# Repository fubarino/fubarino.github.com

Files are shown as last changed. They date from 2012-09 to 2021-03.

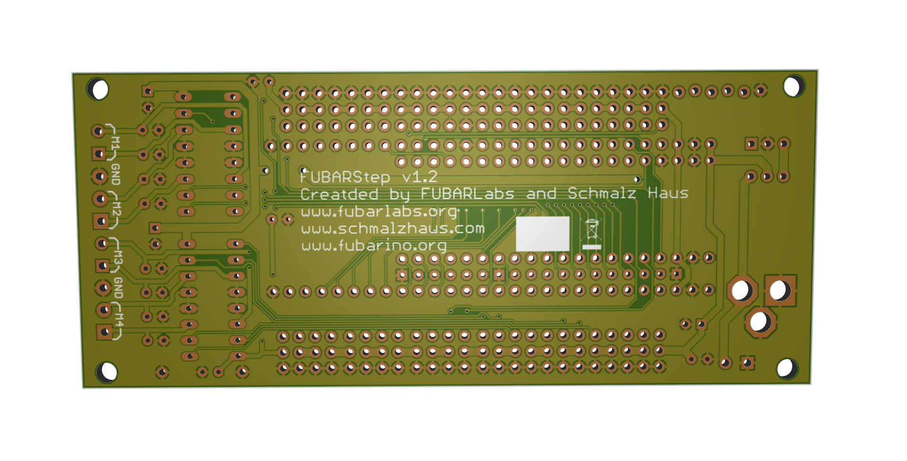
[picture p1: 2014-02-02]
accessories/FubarStep/FuabarStep_v13/BottomRender.png

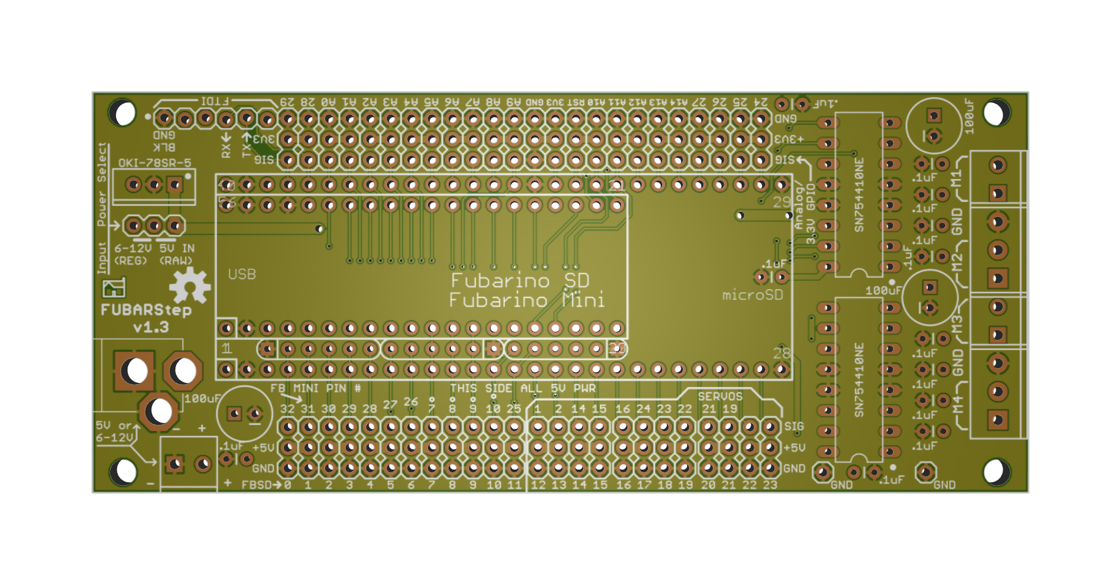
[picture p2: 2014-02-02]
accessories/FubarStep/FuabarStep_v13/TopRender.png

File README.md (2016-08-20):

fubarino: Social Hardware and Software
========
Main Project Pages are:
http://fubarino.org

The chipKIT Fubarino SD board brings affordable, breadboard compatible high speed computing power to the Arduino-compatible chipKIT/MPIDE platform. It is able to run almost all Arduino sketches right out of the box at a great price, and includes more memory, speed, and I/O pins than a typical Arduino or clone. And it includes a microSD card slot for easy sketch access to huge file storage.
chipKIT FubarinoSD
======
Class on a stick. Course materials can fit on the SD card. The device mounts as a USB device. Unfortunately, at 1.0 speeds. But 
it will cut 45 minutes of getting started to 15 minutes. When offering online course using electronics all the course materials can be placed on the board.

The goal with the project is two have two boards that are excellent for small, and bread boardable projects.

Social Hardware:
=====
* Open Source
* Open Hardware
* Sharable

Licensing
====
The chipKIT Fubarino SD hardware is licensed under the Solderpad Hardware License v0.5. All MPIDE source code is licensed under GPL or other open source software licenses.

Availability:
========
These boards are Open Source Hardware and all the files are managed in this project, and are licensed as OpenSource.

* Purchase Fubarino SD version 1.5 at [microchipDIRECT](http://www.microchipdirect.com/ProductSearch.aspx?Keywords=TCHIP010)
* Purchase Fubarino SD version 1.4 at [Seeed Studio](http://www.seeedstudio.com/depot/fubarino-sd-p-1265.html?cPath=132_133)
* Purchase Fubarino Mini version 1.5 at [microchipDIRECT](http://www.microchipdirect.com/ProductSearch.aspx?Keywords=TCHIP011)

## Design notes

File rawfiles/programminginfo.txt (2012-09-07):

Power Fubarino from USB

Unzip Fubarino.zip into variants folder

I have a ICD3 (at the top of the picture) with my custom made RJ-11 to 6-pin .100" header. On that cable (from the ReadlIce) (from left to right)

Direct Connect

ICD3 : value
Blue: unused
Yellow: PGC
Green: PGD
Red: GND
Black: 3.3V
White: MCLR/RESET

Bread Board Example

R:B: value
Blue: White : unused
Yellow: Black : PGC
Green: Red : PGD
Red: Green : GND
Black: Yellow : 3.3V
White: Blue : MCLR/RESET

Then I have five jumpers that connect that ICD3 cable to the Fubarino, again, from left to right

ICD3 : Color : Fubarino
PGC :: Red : A9
PGD :: Yellow : A8
GND :: Green : GND
3.3V :: Black : 3.3
MCLR/RESET : : RST

The important thing is that the cable from the ICD3 goes into the Fubarino 1:1 except for PGC and PGD which need to be reversed.

Hopefully this will help you when you start to program yours on Friday.

ICD3: FubarinoSD
1: PGM 
2: PGC : A9
3: PGD : A8
4: Ground : GND
5: Vdd : 3.3
6: MCLR/Vpp, reset : RST

ICD3: Fubarino Mini end of board left to right
White: Reset
Black: 3.3V
Red: GND
Green: PGD
Yellow: PGC

Note: no blue, unusued

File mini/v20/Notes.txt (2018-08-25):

Fubarino Mini v1.0 board - changes for v1.1 : 04/04/2012
* For v1.1, move 32KHz crystal so it lies flat. Rotate 90 degrees to right. (done)
* Add some silk screen on some pins so you know where to start counting. (done)
* Calculate correct crystal cap values and update BOM (done)
* Make 32KHz crystal a do not populate on schematic and in BOM (done)
* Move PRG and RESET switches further apart (done)

Fubarino Mini v1.1 board - changes for v1.2 : 06/08/2012
* Add in two diodes to allow USB or external VIN power
* Separate out 5V_OUT and VIN as separate pins
* Swap GND and 5V_OUT/VIN so 5V_OUT/VIN are on end

Fubarino Mini v1.2 board - changes for v1.3 : 07/17/2012
* Extended pads for CPU by .3mm so you can rework the part (at request of SeeedStudio)
* Switched power LED to RED in BOM

Fubarino Mini v1.3 board - changes for v1.4 : 07/18/2012
* Switched CPU footprint to QFN44, routing updates to support this change
* C13 switched to 10uF for better 3.3V stability

Fubarino Mini v1.5 board - changes to v1.4 : 02/23/2012 (for Microchip)
* Added chipKIT to silk screen
* Added RoSH garbage icon to silk screen
* Added CE icon to silk screen
* Updated to different USB connector (Hirose UX60-MB-5ST) and re-routed USB signals to fit

Fubarino Mini v1.6 board - changes to v1.5 : 03/14/2012
* J2 pin 17 is now RESET rather than GND. This allows external RESET connection without needing to use J3
* Changed BOM to use 820 ohm LED current limiting resistors rather than 330s

Fubarino Mini v1.7 (now v2.0) board - changes to v1.6 : 08/13/2015
* Connected VBUS net to VBUS PIC32 pin rather than 5V to prevent over voltage on Vin from damaging PIC32 VBUS pin.
* Changed D1 and D2 to CUS15S40,H3F types to handle 1.5A max current
* Changed IC1 to AP7215-33YG-13 to handle 600mA of current (rather than 250mA from old part). Note that max Vin is now 5.5V. (see below)
* Change CPU to PIC32MX270F256D-I/ML. Same as before but with twice the Flash and RAM
  August 2018 update, to create final v1.7 (v2.0) design, based on emails with Matt Jenkins:
  * Change regulator to SPX1117M3-L-3-3/TR (requires layout change)
  * Change USB connector to micro-USB
  * LEDs get 820 ohm resistors
  
Fubarino Mini v2.0 - 10 built up on 8/24/2018. All work as expected.

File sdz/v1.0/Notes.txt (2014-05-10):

These are internal developer change notes created during the development process of the Fubarino SDZ board.
Written by Brian Schmalz of Schmalz Haus LLC (www.schmalzhaus.com)
2014

Version 1.0 ToDo:
* For primary oscillator, find cheap TTL osc rather than crystal, and replace footprint
*

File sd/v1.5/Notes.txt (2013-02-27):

These are internal developer change notes created during the development process of the Fubarino SD board.
Written by Brian Schmalz of Schmalz Haus LLC (www.schmalzhaus.com)
2012

Version 1.0, problems:

* Silk screen messed up - acidentally turned on the part names on the silk layer
    Fix: turn them off before next build
* Swapped PGC and PGD on ICSP connector
    Fix: swap them back for v1.1
* No LED orentation markers on silk screen
    Fix: add them to v1.1
* Crystal is really, really big
    Fix: Find smaller one for v1.1
* For 3.3V regulator, change to one with fixed voltage (3.3V), and smaller if possible
* 250mA poly fuse is too small
    Fix: Switch to 500mA polyfuse for v1.1
* VUSB needs to be tied to +3.3V
* Update MX440 symbol to have all pin functions listed
* MCLR should not have a pin number - can't use it as an I/O pin
* Should we have a pin 0? (rather than starting at 1)

Version 1.1 problems - fix for v1.2:

* Forgot to remove the PTC - should be removed for v1.2 (done)
* Possible change - make all silk screen pin names read same way? (done)
* Silk screen next to green LED is wrong. It should read 21. (done)
* Reverse green LED so it goes to GND rather than 3.3V. (done)
* Check cap values for both crystals (done)
* Move reset and program switches further apart (done)

Version 1.2 - changes for v1.3:

* Add two diodes to allow power from USB or VIN input pin
* Separate out 5V in from post-diode power net, bring to pins
* Swap GND and 5V_OUT/VIN so 5V_OUT/VIN are on end

Version 1.3 - changes for v1.4:

* C13 changed from 1uF to 10uF, and from 0603 ro 0805, to help reduce VCC drop on microSD insert

Version 1.4 - changes for v1.5 (for Microchip):

* Added chipKIT, CE mark, and RoHS mark to bottom silk screen and chipKIT to top silk screen
* added RX silk to pin 8 and TX silk to pin 9
* changed USB connector to Microchip's preferred Hirose UX60-MB-5ST

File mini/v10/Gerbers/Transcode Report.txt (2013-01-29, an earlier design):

   ---- Transcoding 'D:\Projects\UBW32\EE\FubarinoMini\v10\Gerbers\FubarinoMini_v10.GTS' ----   Tue Mar 20 21:46:35 2012

D10   --> D100
D11   --> D101
D12   --> D102
D13   --> D103
D14   --> D104
D15   --> D105
D16   --> D106
D17   --> D107
-----------------------------------------------------------------

   ---- Transcoding 'D:\Projects\UBW32\EE\FubarinoMini\v10\Gerbers\FubarinoMini_v10.cmp' ----   Tue Mar 20 21:46:35 2012

D10   --> D108
D11   --> D109
D12   --> D110
D13   --> D111
D14   --> D112
D15   --> D113
D16   --> D114
D17   --> D115
D19   --> D116
D20   --> D117
D21   --> D118
D24   --> D119
-----------------------------------------------------------------

   ---- Transcoding 'D:\Projects\UBW32\EE\FubarinoMini\v10\Gerbers\FubarinoMini_v10.GBL' ----   Tue Mar 20 21:46:35 2012

D10   --> D120
D11   --> D121
D12   --> D122
D13   --> D123
D14   --> D124
D15   --> D125
-----------------------------------------------------------------

   ---- Transcoding 'D:\Projects\UBW32\EE\FubarinoMini\v10\Gerbers\FubarinoMini_v10.GBS' ----   Tue Mar 20 21:46:35 2012

D10   --> D126
D11   --> D127
D12   --> D128
-----------------------------------------------------------------

   ---- Transcoding 'D:\Projects\UBW32\EE\FubarinoMini\v10\Gerbers\FubarinoMini_v10.GBO' ----   Tue Mar 20 21:46:36 2012

D10   --> D129
D11   --> D130
D12   --> D131
D13   --> D132
-----------------------------------------------------------------

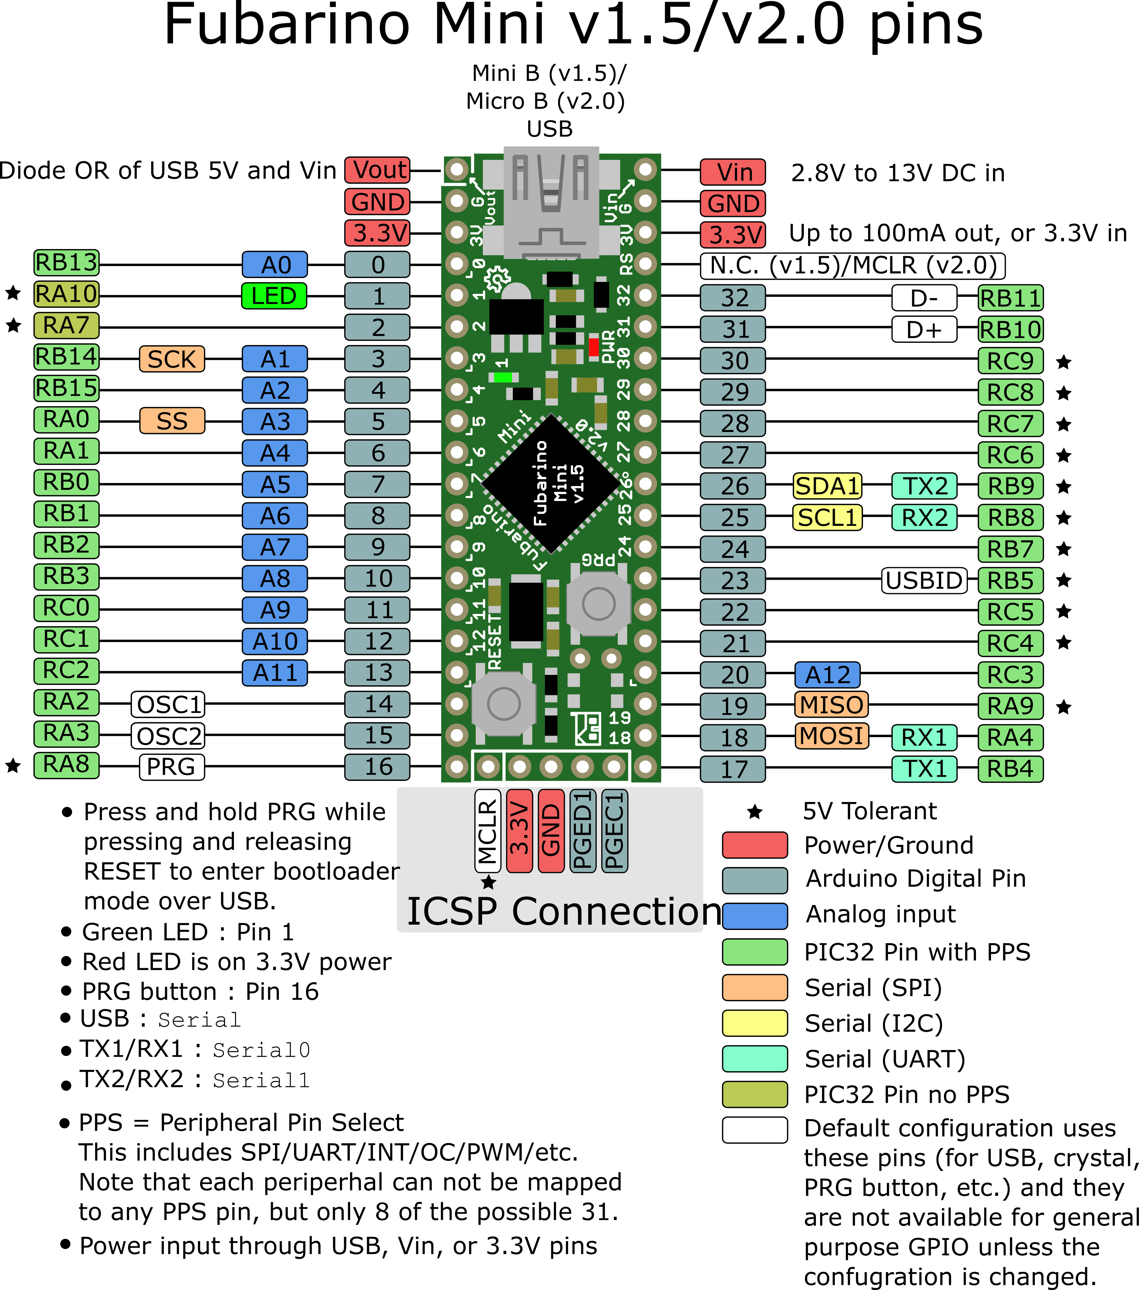
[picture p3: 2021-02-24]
mini/docs/FubarinoMiniDiagram.png

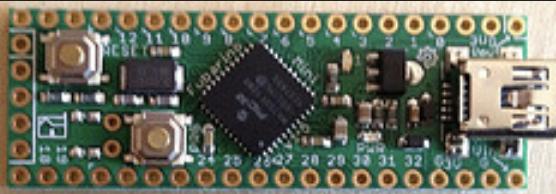
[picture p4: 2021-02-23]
images/FubarinoMini.png

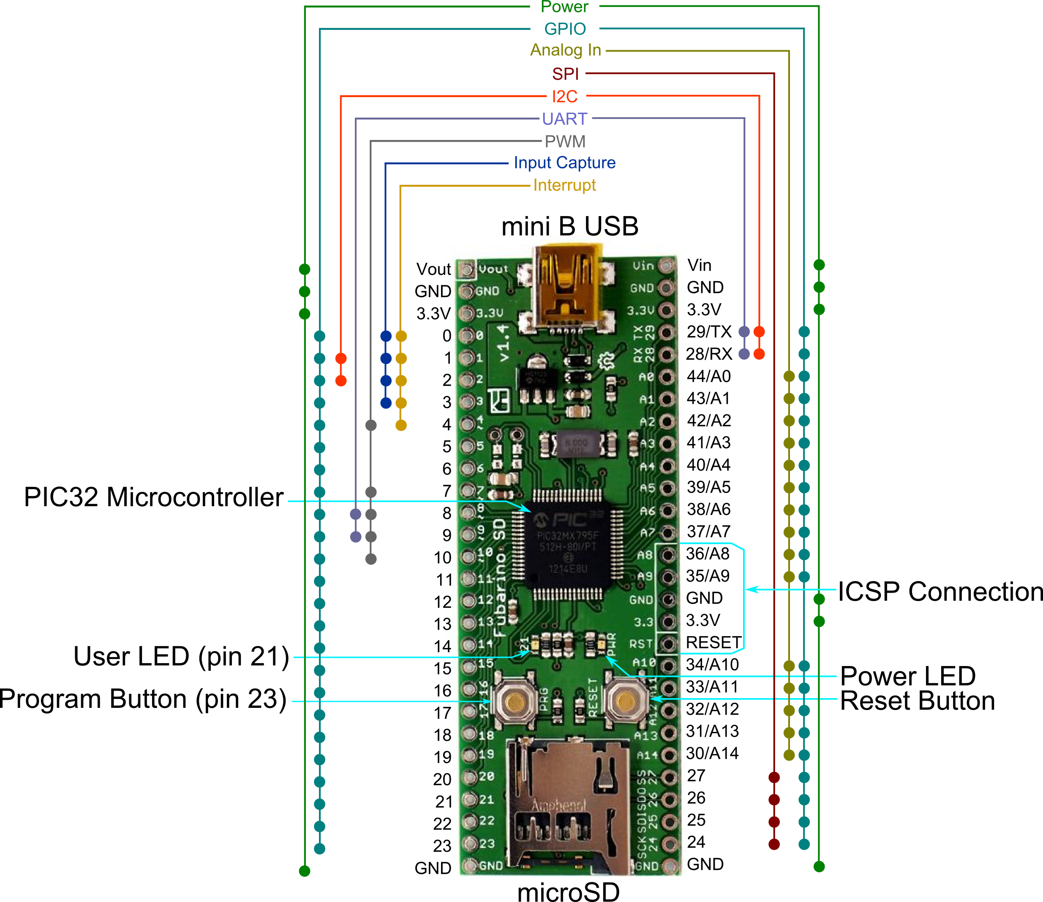
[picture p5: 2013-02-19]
sd/docs/FubarinoSDv1_4Diagram.png

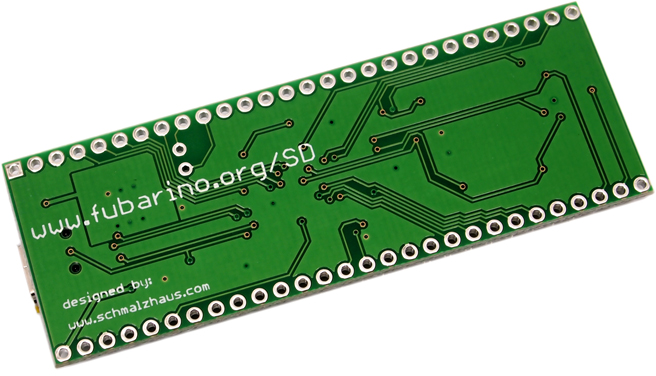
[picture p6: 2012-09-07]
images/fubarinosd2.png

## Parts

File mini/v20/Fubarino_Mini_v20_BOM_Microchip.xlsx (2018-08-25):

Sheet: BOM Report
Bill of Materials |  | Bill of Materials For Project Fubarino Mini v2.0
Part Number: | 02-10133r16.xls
Revision: | 2
Engineer: | Brian Schmalz
Drawn By: | Brian Schmalz
Creation Date:
Print Date:
Quantity | Designator | Description | Manufacturer 1 | Manufacturer Part Number 1 | Supplier 1 | Supplier Part Number 1 | RoHS compliant? | Supplier Order Qty 1 | Supplier Unit Price 1 | Extension | Price @1K | Total @1K
1 | Q1 | CRYSTAL 8.0000MHZ 8PF SMD | NDK America, Inc. | NX3225GD-8MHZ-STD-CRA-3 | Digi-Key | 644-1178-1-ND | Yes | 1 | $0.94 | $0.94 | $0.54 | $0.54
1 | U2 | IC REG LINEAR 3.3V 800MA SOT223 | MaxLinear, Inc. | SPX1117M3-L-3-3/TR | Digi-Key | 1016-1848-1-ND | Yes | 1 | $0.45 | $0.45 | $0.12 | $0.12
1 | C3 | CAP CER 4.7UF 35V X5R 0603 | Murata Electronics North America | GRM188R6YA475KE15D | Digi-Key | 490-7205-1-ND | Yes | 1 | $0.57 | $0.57 | $0.15 | $0.15
2 | C5, C13 | CAP CER 10UF 10V X5R 0805 | Samsung Electro-Mechanics | CL21A106KPFNNNE | Digi-Key | 1276-1052-1-ND | Yes | 2 | $0.16 | $0.32 | $0.03 | $0.06
1 | J8 | CONN RCPT USB MICRO B 2.0 5P SMD | Hirose Electric Co Ltd | ZX62D-B-5PA8(30) | Digi-Key | H125718CT-ND | Yes | 1 | $0.77 | $0.77 | $0.40 | $0.40
2 | PRG, RESET | SWITCH TACTILE SPST-NO 0.05A 16V | C&K Components | PTS810 SJM 250 SMTR LFS | Digi-Key | CKN10502DKR-ND | Yes | 2 | $0.30 | $0.60 | $0.17 | $0.35
4 | C4, C8, C9, C10 | CAP CER 0.1UF 50V Y5V 0603 | Yageo | CC0603ZRY5V9BB104 | Digi-Key | 311-1343-1-ND | Yes | 4 | $0.10 | $0.40 | $0.02 | $0.06
1 | LED1 | LED RED CLEAR CHIP SMD | Lite-On Inc. | LTST-C193KRKT-5A | Digi-Key | 160-1830-1-ND | Yes | 1 | $0.41 | $0.41 | $0.08 | $0.08
1 | LED2 | LED GREEN CLEAR CHIP SMD | Lite-On Inc. | LTST-C193KGKT-5A | Digi-Key | 160-1828-1-ND | Yes | 1 | $0.41 | $0.41 | $0.08 | $0.08
2 | R8,R11 | RES 820 OHM 1/10W 5% 0603 SMD | Panasonic | ERJ-3GEYJ821V | Digi-Key | P820GCT-ND | Yes | 2 | $0.10 | $0.20 | $0.01 | $0.02
3 | R1,R9,R10 | RES 10K OHM 1/10W 5% 0603 SMD | Panasonic | ERJ-3GEYJ103V | Digi-Key | P10KGCT-ND | Yes | 3 | $0.10 | $0.30 | $0.01 | $0.03
1 | U1 | IC MCU 32BIT 256KB FLASH 44QFN | Microchip | PIC32MX270F256D-50I/ML | Digi-Key | PIC32MX270F256D-50I/ML-ND | Yes | 1 | $4.62 | $4.62 | $3.84 | $3.84
2 | C14, C15 | CAP CER 12PF 50V C0G/NP0 0603 | AVX Corporation | 06035A120GAT2A | Digi-Key | 478-7910-1-ND | Yes | 2 | $0.52 | $1.04 | $0.14 | $0.27
1 |  | Fubarino Mini v1.7 blank PCB |  |  |  |  | Yes | 1 |  | $0.00 |  | $0.00
2 | D1, D2 | DIODE SCHOTTKY 40V 1.5A SOD323 | Toshiba Semiconductor and Storage | CUS15S40,H3F | Diki-Key | CUS15S40H3FCT-ND | Yes | 2 | $0.47 | $0.94 | $0.09 | $0.17
DO NOT POPULATE ANY PARTS BELOW THIS LINE
0 | Q2 | CRYSTAL 32.768KHZ 12.5PF | Siko Insturments | VT200F-12.5PF20PPM | Digi-Key | 728-1001-ND | Yes | 0 | $0.30 | $0.00 |  | $0.00
0 | C1, C2 | CAP CERAMIC 18PF 50V NP0 0603 | Kemet | C0603C180J5GACTU | Digi-Key | 399-1052-1-ND | Yes | 0 | $0.10 | $0.00 |  | $0.00
0 | J3 | ICSP 5-pin .100" header
 |  |  |  |  |  |  |  |  |  | $11.97 |  | $6.17
Approved | Notes
 |  | Parts changed from last production build

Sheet: Project Information
Project Full Path
Project Filename
Variant Name
Data-Source Filename
Data-Source Full Path
Title
Total Quantity
Report Time
Report Date
Report Date & Tine
Output Name
Output Type
Output Generator Name
Output Generator Description

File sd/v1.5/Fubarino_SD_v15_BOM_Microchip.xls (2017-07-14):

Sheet: BOM Report
Bill of Materials |  | Bill of Materials For Project Fubarino SD v1.5
Part Number: | 05-10133r15.xls |  |  |  |  |  |  | M
Revision: | 1.5
Engineer: | Brian Schmalz
Drawn By: | Brian Schmalz
Creation Date:
Print Date:
Quantity | Designator | Description | Manufacturer 1 | Manufacturer Part Number 1 | Supplier 1 | Supplier Part Number 1 | RoHS compliant? | Supplier Order Qty 1 | Supplier Unit Price 1 | Extension
1 | Q1 | CRYSTAL 8.00 MHZ 8PF SMD | NDK | NX5032GA 8MHZ AT-W | Digikey | 644-1132-1-ND | Yes | 1 | 1.7 | $1.70
1 | IC2 | IC REG SOT89 3.3V | Microchip | MCP1702T-3302E/MB | MicrochipDirect | MCP1702T-3302E/MB | Yes | 1 | 0.48 | $0.48
1 | C3 | CAP 1UF 10V CER Y5V SMD 0603 | Kemet | C0603C105Z8VACTU | Digi-Key | 399-3216-1-ND | Yes | 1 | 0.1 | $0.10
2 | C5, C13 | CAP CER 10UF 10V Y5V 0805 | Kemet | C2012Y5V1A106Z | Digi-Key | 445-1371-1-ND | Yes | 2 | 0.15 | $0.30
1 | J8 | CONN RECEPT MINI USB2.0 5POS | Hirose | UX60-MB-5ST | Digi-Key | H2959TR-ND | Yes | 1 | 0.528 | $0.53
2 | PRG, RESET | SWITCH TACT SMT SPST 160GF | C&K Components | PTS525SM10SMTR LFS | Digi-Key | CKN9104CT-ND | Yes | 2 | 0.61 | $1.22
4 | C4, C8, C9, C10 | CAP CERAMIC .100UF 50V X7R 0603 | Kemet | C0603C104K5RACTU | Digi-Key | 399-5089-1-ND | Yes | 4 | 0.1 | $0.40
1 | LED1 | LED SMARTLED 630NM RED 0603 SMD | OSRAM | LS L29K-G1J2-1-Z | Digi-Key | 475-2506-1-ND | Yes | 1 | 0.17 | $0.17
1 | LED2 | LED SMARTLED GREEN 570NM 0603 | OSRAM | LG L29K-G2J1-24-Z | Digi-Key | 475-2709-1-ND | Yes | 1 | 0.22 | $0.22
2 | R8,R11 | RES 330 OHM 1/10W 5% 0603 SMD | Panasonic | ERJ-3GEYJ331V | Digi-Key | P330GCT-ND | Yes | 2 | 0.1 | $0.20
4 | R1,R3,R9,R10 | RES 10K OHM 1/10W 5% 0603 SMD | Panasonic | ERJ-3GEYJ103V | Digi-Key | P10KGCT-ND | Yes | 4 | 0.1 | $0.40
1 | IC1 | PIC32 USB CPU | Microchip | PIC32MX795F512H-80I/PT | MicrochipDirect | PIC32MX795F512H-80I/PT | Yes | 1 | 8.75 | $8.75
2 | C14, C15 | CAP CER 12PF 50V 5% NP0 0603 | Kemet | C0603C120J5GACTU (http://www.digikey.com/product-detail/en/C0603C120J5GACTU) | Digi-Key | 399-1050-1-ND | Yes | 2 | 0.1 | $0.20
1 |  | Fubarino SD v1.5 blank PCB | ??? | ??? | ??? | ??? | Yes | 1 |  | $0.00
2 | D1, D2 | DIODE SCHOTTKY 0.5A 40V SOD323 | Diodes Inc | B0540WS-7 (http://www.digikey.com/product-detail/en/B0540WS-7) | Digi-Key | B0540WSDICT-ND | Yes | 2 | 0.45 | $0.90
1 | MICROSD | CONN MINI MICRO-SD 8PIN PCB GOLD | Amphenol | 101-00581-59 | Digi-Key | 101-00581-59-1-ND | Yes | 1 | 1.97 | $1.97
DO NOT POPULATE ANY PARTS BELOW THIS LINE
0 | Q2 | CRYSTAL 32.768KHZ 12.5PF | Siko Insturments | VT200F-12.5PF20PPM | Digi-Key | 728-1001-ND | Yes | 0 | 0.3 | $0.00
0 | C1, C2 | CAP CERAMIC 18PF 50V NP0 0603 | Kemet | C0603C180J5GACTU | Digi-Key | 399-1052-1-ND | Yes | 0 | 0.1 | $0.00
 |  |  |  |  |  |  |  |  |  | $17.54
Approved | Notes

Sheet: Project Information
Project Full Path
Project Filename
Variant Name
Data-Source Filename
Data-Source Full Path
Title
Total Quantity
Report Time
Report Date
Report Date & Tine
Output Name
Output Type
Output Generator Name
Output Generator Description

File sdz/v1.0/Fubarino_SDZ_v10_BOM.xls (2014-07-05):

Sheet: BOM Report
Bill of Materials |  | Bill of Materials For Project Fubarino SDZ v1.0
Part Number: |  |  |  |  |  |  |  | M
Revision: | 1.0
Engineer: | Brian Schmalz
Drawn By: | Brian Schmalz
Creation Date:
Print Date:
Quantity | Designator | Description | Manufacturer 1 | Manufacturer Part Number 1 | Supplier 1 | Supplier Part Number 1 | RoHS compliant? | Supplier Order Qty 1 | Supplier Unit Price 1 | Extension
1 | IC3 | OSC MEMS 24.000MHZ CMOS SMD | Silicon Labs | 501JCA24M0000CAF | Digi-Key | 336-2924-ND | Yes | 1 | 1.04 | $1.04
1 | IC2 | IC REG SOT89 3.3V | Microchip | MCP1702T-3302E/MB | Digi-Key | MCP1702T-3302E/MBCT-ND | Yes | 1 | 0.58 | $0.58
1 | C3 | CAP 1UF 10V CER Y5V SMD 0603 | Kemet | C0603C105Z8VACTU | Digi-Key | 399-3216-1-ND | Yes | 1 | 0.1 | $0.10
2 | C13 | CAP CER 10UF 10V Y5V 0805 | Kemet | C2012Y5V1A106Z | Digi-Key | 445-1371-1-ND | Yes | 2 | 0.15 | $0.30
1 | J4 | Conn Micro USB Type B RCP 5 POS | Hirose | ZX62-B-5PA(11) | Digi-Key | H11634CT-ND | Yes | 1 | 0.96 | $0.96
2 | PRG, RESET | SWITCH TACTILE SPST-NO 0.05A 32V | C&K Components | KMR221NG LFS | Digi-Key | CKN10244CT-ND | Yes | 2 | 0.58 | $1.16
4 | C4, C6, C8, C9, C10 | CAP CERAMIC .100UF 50V X7R 0603 | Kemet | C0603C104K5RACTU | Digi-Key | 399-5089-1-ND | Yes | 4 | 0.1 | $0.40
1 | LED1 | LED SMARTLED 630NM RED 0603 SMD | OSRAM | LS L29K-G1J2-1-Z | Digi-Key | 475-2506-1-ND | Yes | 1 | 0.17 | $0.17
1 | LED2 | LED SMARTLED GREEN 570NM 0603 | OSRAM | LG L29K-G2J1-24-Z | Digi-Key | 475-2709-1-ND | Yes | 1 | 0.22 | $0.22
2 | R8,R11 | RES 330 OHM 1/10W 5% 0603 SMD | Panasonic | ERJ-3GEYJ331V | Digi-Key | P330GCT-ND | Yes | 2 | 0.1 | $0.20
4 | R1,R3,R9,R10 | RES 10K OHM 1/10W 5% 0603 SMD | Panasonic | ERJ-3GEYJ103V | Digi-Key | P10KGCT-ND | Yes | 4 | 0.1 | $0.40
1 | IC1 | PIC32 USB CPU | Microchip | PIC32MZ2048ECH064 | MicrochipDirect | PIC32MZ2048ECH064 | Yes | 1 | 8.75 | $8.75
1 | R2 | RES 1K OHM 1/10W 5% 0603 SMD | Panasonic | ERJ-3GEYJ102V | Digi-Key | P1.0KGCT-ND | Yes | 1 | 0.1
1 |  | Fubarino SDZ v1.0 blank PCB |  |  |  |  | Yes | 1 |  | $0.00
2 | D1, D2 | DIODE SCHOTTKY 0.5A 40V SOD323 | Diodes Inc | B0540WS-7 (http://www.digikey.com/product-detail/en/B0540WS-7) | Digi-Key | B0540WSDICT-ND | Yes | 2 | 0.5 | $1.00
1 | MICROSD | CONN MINI MICRO-SD 8PIN PCB GOLD | Amphenol | 101-00581-59 | Digi-Key | 101-00581-59-1-ND | Yes | 1 | 1.84 | $1.84
DO NOT POPULATE ANY PARTS BELOW THIS LINE
0 | Q2 | CRYSTAL 32.768KHZ 12.5PF | Siko Insturments | VT200F-12.5PF20PPM | Digi-Key | 728-1001-ND | Yes | 0 | 0.3 | $0.00
0 | C5 | CAP CER 10UF 10V Y5V 0805 | Kemet | C2012Y5V1A106Z | Digi-Key | 445-1371-1-ND | Yes | 2 | 0.15 | $0.30
0 | J5
0 | C1, C2 | CAP CERAMIC 18PF 50V NP0 0603 | Kemet | C0603C180J5GACTU | Digi-Key | 399-1052-1-ND | Yes | 0 | 0.1 | $0.00
 |  |  |  |  |  |  |  |  |  | $17.42
Approved | Notes

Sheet: Project Information
Project Full Path
Project Filename
Variant Name
Data-Source Filename
Data-Source Full Path
Title
Total Quantity
Report Time
Report Date
Report Date & Tine
Output Name
Output Type
Output Generator Name
Output Generator Description

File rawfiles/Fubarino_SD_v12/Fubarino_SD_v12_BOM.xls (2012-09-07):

Qty | Ref | Description | Mfg Part Number | Disti part number | Distributor | Price @1 | Price @1000 | Total @1 | Total @1000
1 | Q1 | CRYSTAL 8.00 MHZ 8PF SMD | NX5032GA 8MHZ AT-W | 644-1132-1-ND | Digi-Key | $1.70 | $0.86 | $1.70 | $0.86
1 | IC2 | IC REG SOT89 3.3V | MCP1702T-3302E/MB | MCP1702T-3302E/MB | MicrochipDirect | $0.48 | $0.86 | $0.48 | $0.86
2 | C3, C13 | CAP 1UF 10V CER Y5V SMD 0603 | C0603C105Z8VACTU | 399-3216-1-ND | Digi-Key | $0.04 | $0.03 | $0.08 | $0.06
1 | C5 | CAP CER 10UF 10V Y5V 0805 | C2012Y5V1A106Z | 445-1371-1-ND | Digi-Key | $0.32 | $0.08 | $0.32 | $0.08
1 | J8 | CONN RECEPT MINI USB2.0 5POS | 10033526-N3212MLF | 10033526-N3212MLF | Newark | $0.54 | $0.35 | $0.54 | $0.35
2 | PRG, RESET | SWITCH TACT SMT SPST 160GF | PTS525SM10SMTR LFS | CKN9104CT-ND | Digi-Key | $0.56 | $0.36 | $1.12 | $0.71
4 | C4, C8, C9, C10 | CAP CERAMIC .100UF 50V X7R 0603 | C0603C104K5RACTU | 399-5089-1-ND | Digi-Key | $0.14 | $0.05 | $0.58 | $0.21
1 | LED1 | LED SMART 470NM BLUE 0603 SMD | LB L293-M2P1-36-1-10-R18-Z | 475-1383-1-ND | Digi-Key | $0.69 | $0.46 | $0.69 | $0.46
1 | LED2 | LED GRN HI BRT SS TYPE LO CUR S | LNJ308G8TRA | P525CT-ND | Digi-Key | $0.46 | $0.20 | $0.46 | $0.20
2 | R8,R11 | RES 330 OHM 1/10W 5% 0603 SMD | ERJ-3GEYJ331V | P330GCT-ND | Digi-Key | $0.02 | $0.01 | $0.04 | $0.01
3 | R1,R3,R10 | RES 10K OHM 1/10W 5% 0603 SMD | ERJ-3GEYJ103V | P10KGCT-ND | Digi-Key | $0.02 | $0.01 | $0.06 | $0.02
1 | U1 | PIC32 USB CPU | PIC32MX440F256H-80I/PT | PIC32MX440F256H-80I/PT | MicrochipDirect | $6.30 | $4.81 | $6.30 | $4.81
1 |  | 2.8 sq inches of PCB at .71 each |  |  | GoldPhoenix | $1.99 | $0.50 | $1.99 | $0.50
4 | C1, C2, C14, C15 | CAP CERAMIC 18PF 50V NP0 0603 | C0603C180J5GACTU | 399-1052-1-ND | Digi-Key | $0.07 | $0.03 | $0.28 | $0.10
1 | MICROSD | CONN MINI MICRO-SD 8PIN PCB GOLD | 101-00581-59 | 101-00581-59-1-ND | Digi-Key | $1.94 | $1.05 | $1.94 | $1.05
1 | Q2 | CRYSTAL 32.768KHZ 12.5PF | VT200F-12.5PF20PPM | 728-1001-ND | Digi-Key | $0.42 | $0.28 | $0.42 | $0.28
 |  |  |  |  |  |  | Total | $15.30 | $10.56

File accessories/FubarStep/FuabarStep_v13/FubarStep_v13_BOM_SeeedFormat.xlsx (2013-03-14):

Electronic Engineering BOM List
Product Name： FubarStep
Version：V1.0
Issue Date：03/13/2013
Item No. (序号) | Reference Des (上件位置) | Qty (用量) | Catalog (分类） | Part_Description (规格描述) | Part_Value （元件值） | Part_Package （元件封装） | Manufacturers Name (使用厂牌名称) | Manufacturers Part No. (使用厂牌型号) | Distributors Name （供应商名称） | Distributors Part No. (供貨商型号) | Unit Price （单价） | Price Break To Use （价格分段的购买量） | Notes/Remark （备注）
Example（填写范例）
1 | U1 | 2 | Connector | 28 pin female .100" header for Fubarino SD footprint |  |  | Ebay |  |  |  | $0.5500 |  | $1.10
2 | U2 | 2 | Connector | 20 pin female .100" header for Fubarino Mini footprint |  |  | Ebay |  |  |  | $0.3500 |  | $0.70
3 | JP7,JP9,JP13,JP24,JP30,JP25,JP28,JP29,JP31,JP32,JP33, | 3 | Connector | 12 pin male .100" header for servo connections |  |  | Ebay |  |  |  | $0.1200 |  | $0.36
4 | JP18,JP19,JP20,Jp21,JP26,JP27,JP14,JP15,JP16,JP17,Jp22,JP23,JP10,JP11,JP12 | 3 | Connector | 15 pin male .100" header for analog connections |  |  | Ebay |  |  |  | $0.1500 |  | $0.45
5 | C3,C11,C10,C12,C9,C13,C8,C15,C14,C18,C19,C1 | 12 | Capacitor | .1uF through hole ceramic capactor |  |  | Murata | RPER71H104K2P1A03B | Arrow | RPER71H104K2P1A03B | $0.0485 |  | $0.58
6 | C5,C2,C17,C16 | 4 | Capacitor | 100uF >35V electrolytic through hole capacitor |  |  | Nichicon | UVR1H101MPD | Arrow | UVR1H101MPD | $0.0426 |  | $0.17
7 | IC2,IC3 | 2 | IC | SN754410NE H-Bridge in 16 PDIP |  |  | Texas Instruments | SN754410NE | Arrow | SN754410NE | $0.8899 |  | $1.78
8 | SOC1,SOC2 | 2 | Connector | 16 PDIP socket for IC2, IC3 |  |  | TE Connectivity | 13902614 | Arrow | 13902614 | $0.0923 |  | $0.18
9 | JP1, JP2 | 2 | Connector | 4-pin 3.5mm screw terminal |  |  | Molex | 393570004 | Arrow | 393570004 | $0.5619 |  | $1.12
10 | JP8 | 1 | Connector | 6-pin right angle .100 male header |  |  | FCI | 68016136HLF | Arrow | 68016136HLF | $0.8062 |  | $0.81
11 | JP3 | 1 | Connector | 3-pin male .100 header for power select |  |  | Ebay |  |  |  | $0.0300 |  | $0.03
12 | JP4 | 1 | Connector | 2-pin 3.5mm screw terminal |  |  | Molex | 393570002 | Arrow | 393570002 | $0.2721 |  | $0.27
13 | X1 | 1 | Connector | barrel jack power input |  |  | Switchcraft | RAPC722X | Arrow | RAPC722X | $0.3942 |  | $0.39
14 | U3 | 1 | IC | 5V switching regulator |  |  | Murata Power Solutions | OKI-78SR-5/1.5-W36H-C | DigiKey | 811-2196-5-ND | $4.3000 |  | $4.30
15 | JP3_JUMP | 1 | Connector | .100 2-pin shorting jumper |  |  | FCI | 68786102LF | Arrow | 68786102LF | $0.0726 |  | $0.07
16 | PCB | 1 | OTHER | FubarStep v1.0 PCB |  |  | SeeedStudio |  |  |  | $3.4000 |  | $3.40
 |  |  |  |  |  |  |  |  |  |  |  |  | $0.00
 |  |  |  |  |  |  |  |  |  |  |  | Total | $15.73
1. Recommended Distributor: Digi-Key, Mouser, Avnet Express, Farnell.
2. Catalog: Capacitor,Resister,Diode,Connector,Transistor,IC,PROTECTOR CATEGORY,OTHER
3. Required Fields: Item No, Reference Des, Qty, Catalog, Part_Value, Part Package
Optional Fields: Part_Description, Manufacturers Name, Manufacturers Part No, Distributors Name, Distributors Part No, Unit Cost, Price break to use, Notes/Remark

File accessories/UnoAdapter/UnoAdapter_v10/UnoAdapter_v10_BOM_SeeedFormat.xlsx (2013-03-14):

Electronic Engineering BOM List
Product Name： Fubarino UnoAdapter
Version : 1.0
Issue Date
Item No. (序号) | Reference Des (上件位置) | Qty (用量) | Catalog (分类） | Part_Description (规格描述) | Part_Value （元件值） | Part_Package （元件封装） | Manufacturers Name (使用厂牌名称) | Manufacturers Part No. (使用厂牌型号) | Distributors Name （供应商名称） | Distributors Part No. (供貨商型号) | Unit Price （单价） | Price Break To Use （价格分段的购买量） | Notes/Remark （备注）
Example（填写范例）
1 |  | 1 | Connector | 10 pin .100" x .735" high female header |  |  | Samtec | ESW-110-44-T-S | Samtec | ESW-110-44-T-S | 1.09
2 |  | 2 | Connector | 8 pin .100" x .735" high female header |  |  | Samtec | ESW-108-44-T-S | Samtec | ESW-108-44-T-S | .869
3 |  | 1 | Connector | 6 pin .100" x .735" high female header |  |  | Samtec | ESW-106-44-T-S | Samtec | ESW-106-44-T-S | .652
1. Recommended Distributor: Digi-Key, Mouser, Avnet Express, Farnell.
2. Catalog: Capacitor,Resister,Diode,Connector,Transistor,IC,PROTECTOR CATEGORY,OTHER
3. Required Fields: Item No, Reference Des, Qty, Catalog, Part_Value, Part Package
Optional Fields: Part_Description, Manufacturers Name, Manufacturers Part No, Distributors Name, Distributors Part No, Unit Cost, Price break to use, Notes/Remark

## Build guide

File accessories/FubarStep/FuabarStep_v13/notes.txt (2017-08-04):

FUBARStep v1.0

First board soldered up on 4/1/2013 at Schmalz Haus.

Problems to fix for v1.1:

* 100uF caps are too wide. Either find skinnier caps, or move footprints around for more space
* 3-pin power header is really hard to get to. Could there be a better place? Or more room?
* Need to use 5-pin screw terminals for motors so we can accommodate uni-polar motors
* Make sure to check voltage regulator part number for vertical, not horizontal, part
* Give power jack a touch more room - it's squashed against header
* Re-order motor outputs so that motor 1 is at top and motor 4 is at bottom
* Fix silk screen label for center pin on top I/O row - should be +3V3 not +5V

Problems to fix for v1.2:

* FTDI TX and RX are backwards (Make sure to check with SD and Mini to be sure)

Problems to fix for v1.3:

* Silk screen is too thin for Seeed's process : make bigger/thicker
* Swap placement for power selector header and 5V regulator - in v1.2, regulator may interfere with USB connector
* Copy silk screen for motor outputs to bottom of board
* Add pull-down resistors to all 4 enable lines
* Add pull-down resistors to all 8 motor control lines
* Change text of PWRSEL to REG/UNREG or something similar - 5V/6-12V is too confusing
* Separate 3-pin servo headers so that you can stack them full of servos
* Move PWRSEL to right in front of USB connection
* Move voltage regulator away from USB connection a bit.
* Make silk text thicker
* Update BOM so it's accurate
* (From Rick) Add heat shrink around the switcher to protect it from wires

Problems with v1.3:
* The voltage regulator is too close to the voltage jumper. They need to be moved apart more.
* Make the + and - on the power input screw terminal bigger/thicker
* Could separate each of the 3-pin servo headers even a bit more (now grouped in groups of 4)
* Forgot to change the version number on the silk screen!! Should be v1.3, is v1.2

Assembly Notes:
  Assemble in the following (height) order:
  1) .1uf caps
  2) resistor packs
  3) chip sockets
  4) Female Headers (make sure to use FBMini and FBSD or male headers to get spacing correct)
  5) Male Headers (make sure to use separate 3-pin headers for servos)
  6) Screw Terminals, barrel jack
  7) Electrolytic caps
  8) Switching regulator

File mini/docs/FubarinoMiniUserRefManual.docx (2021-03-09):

# Fubarino™ Mini Reference Manual

Last Revision: March 7th, 2021

## Introduction:

The Fubarino™ Mini is a small microcontroller board that uses a powerful PIC32 microcontroller. It is chipKITTM/MPIDE compatible and can run the same sketches that run on an ArduinoTM. It is designed to have all I/O pins on either side of the board in a traditional DIP pattern so that it can easily be plugged into a breadboard. It has a USB connector for power, programming, and a connection to a PC.

Features:

- PIC32MX250F128D-50I/ML microcontroller, which includes 128KB Flash and 32K RAM (FB Mini v1.5)
- PIC32MX250F256D-50I/ML microcontroller, which includes 256KB Flash and 64K RAM (FB Mini v2.5)
- Supported as development target from within MPIDE
- Max 33 I/O pins (normally 27)
- Pads for 32 KHz crystal
- CPU runs at 48MHz
- USB connector for power, programming, and connection to PC (serial, mass storage, etc.)
- Two buttons: RESET for resetting the board, and PRG for getting into bootloader mode and user application use
- USB bootloader pre-programmed at the factory – no other hardware needed to program board\
- Separate ICSP connector – for hardware programming/debugging with PICKit3 or other ICSP programmer (not needed for use with MPIDE environment)

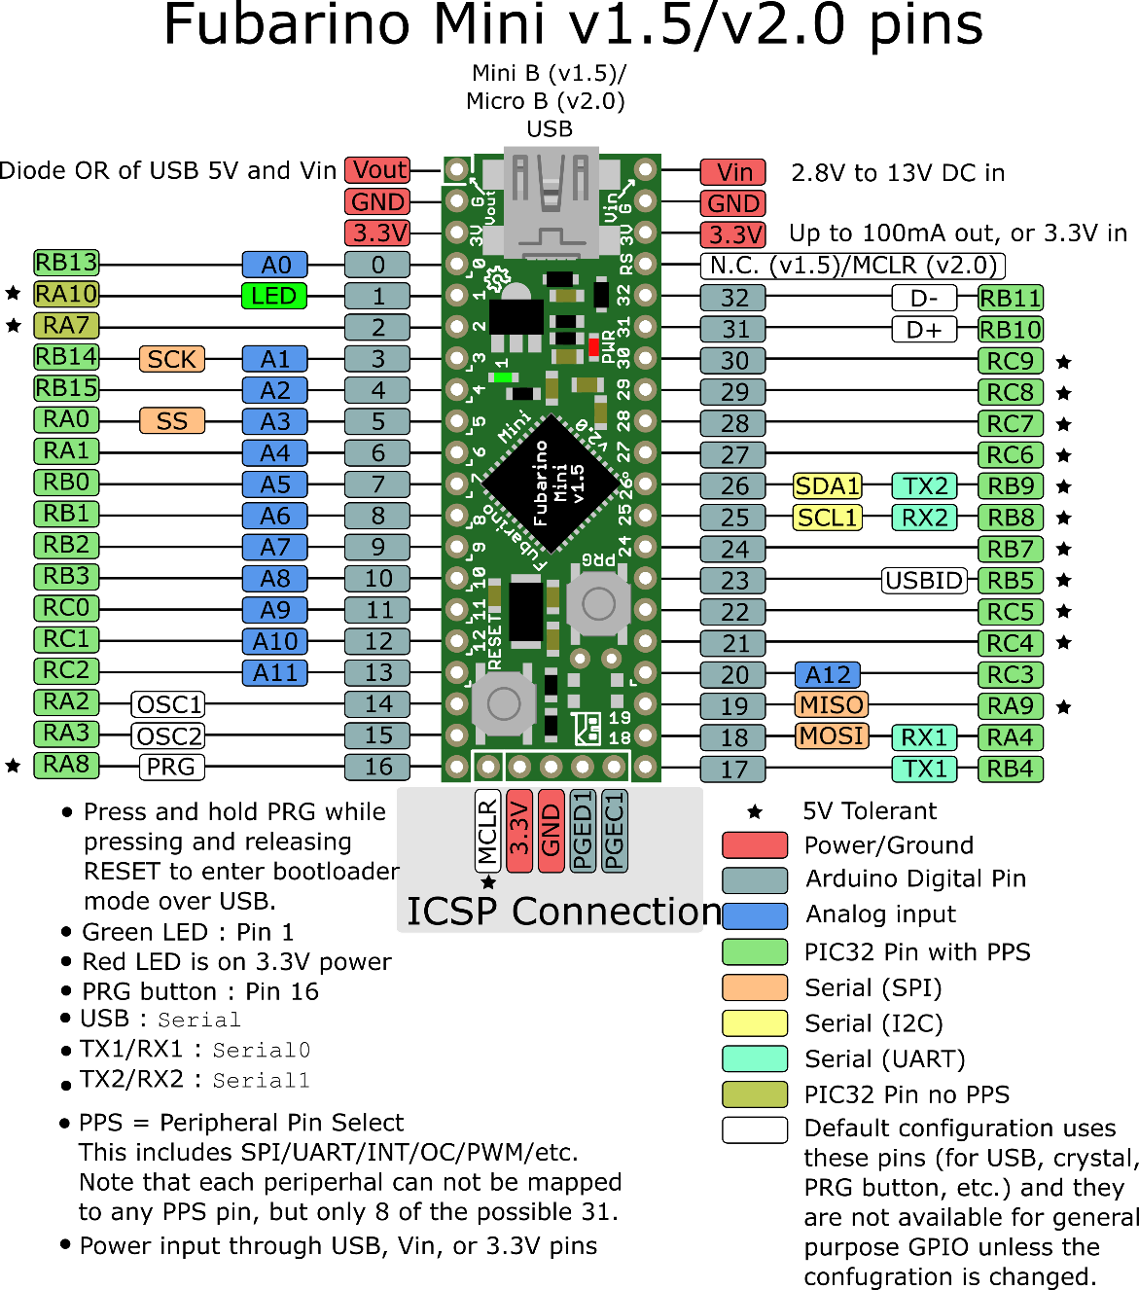
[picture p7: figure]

Figure 1 : Fubarino™ Mini Pin Map

## Entering Bootloader Mode

To enter bootloader mode (also called programming mode) simply press the PRG button while pressing and releasing the RESET button. As long as the PRG button is held down when the RESET button is released, the bootloader will start waiting for a new program to be downloaded over USB. It will wait indefinitely.

The bootloader on the Fubarino™ Mini implements the avrdude STK500 v2 protocol, just like the other chipKITTM/MPIDE boards. For Windows users, you may need to install the drivers\Stk500v2.ini file so that the FubarinoTM Mini is recognized by the PC. Mac and Linux users do not have to install any drivers.

## Programming in MPIDE

To program the Fubarino Mini board from within MPIDE, simply download the latest MPIDE version (http://bit.ly/getmpide), http://bit.ly/getmpide, unzip and run it, and select “Fubarino Mini” from the Tools->Boards->Fubarino menu. Then, put the Fubarino Mini into bootloader mode (see above), and then select the proper serial port in the Tools->Serial Port menu.

After you enter your sketch and click the Upload button, MPIDE will compile your sketch and upload it to the Fubarino Mini. After the upload is complete, the Fubarino Mini will automatically reset and immediately begin running your sketch code. This includes sending information to the USB serial, UART1, and UART2.

## Serial communications

The Fubarino Mini board has two hardware serial ports: UART1 on pins 17 (TX) and 18 (RX), and UART2 on pins 26 (TX) and 25 (RX). It also has a USB serial port that operates as the default serial port. See the Code Examples wiki page on the Fubarino Mini website for example sketch code on how to uses the three serial ports. Note that UART1 and UART2 can be configured (using PPS) to appear on multiple different I/O pins – the pins listed below are simply the defaults that are applied at boot.

- USB serial init: Serial.begin()
- UART1 pins 17 (TX), 18 (RX): Serial0.begin()
- UART2 pins 26 (TX), 25 (RX): Serial1.begin()

## Power

The Fubarino Mini can be powered in a number of different ways.

1. USB: When 5V is present on the USB connector (from a PC or a powered hub for example), the Fubarino Mini will use this power source. This power source has a reverse protection diode connection to the 3.3V regulator. If both USB and Vin are powered, whichever is higher will end up providing the power to the regulator.
2. Vin pin: You can also place 2.8V to 13.2V on the Vin pin to power it from an external power source. This power source has a reverse protection diode connection to the 3.3V regulator. If both USB and Vin are powered, whichever is higher in voltage will power the device.
3. 3.3V pin(s): You can power the Fubarino Mini by connecting a 3.3V source to either 3.3V pin. You must be careful not to exceed 3.6V on these pins or the PIC32 will be destroyed.

## Fubarino Mini Versions

Fubarino Mini versions 1.0 to 1.3 were not produced in any number and were not widely distributed.

Fubarino Mini version 1.4 made its way into several users’ hands and is functionally identical to version 1.5 except that it uses a 40MHz rated PIC32 part and only runs at 40MHz. Thus, the bootloader is slightly different, and the “Fubarino Mini (dev)” board should be chosen in the MPIDE Boards->Fubarino menu.

Fubarino Mini v1.5 was the first version Microchip built and uses a 50MHz rated PIC32 part. Its internal clock speed is set to 48MHz, and thus uses a slightly different bootloader than the v1.4 and earlier boards. Make sure to select “Fubarino Mini” from the MPIDE Boards->Fubarino menu for version 1.5 boards.

Fubarino Mini v2.0 was the last version built by Microchip. It has the following changes from v1.5:

- VBUS pin on PIC32 connected to VBUS net (before D1) rather than 5V net (after D1) to prevent excessive voltage on Vin from damaging VBUS pin on PIC32.
- D1 and D2 changed to handle more current (1.5A).
- 3.3V LDO changed. Higher current (800mA) and higher max input voltage (20V).
- MCU changed to PIC32MX270F256D-I/ML. Doubled the Flash and RAM from v1.5.
- USB connector changed from mini-B to micro-B.
- LED current limiting resistors changed to dim the overly-bright LEDs of v1.5.

## Peripheral Pin Select

The PIC32MX250 part used on Fubarino Mini has a Peripheral Pin Select function for almost all of its I/O pins. When writing sketches for the Fubarino Mini, you must remember to connect an internal peripheral (like SPI or UART) to a particular set of I/O pins using the PPS functions (ppsInputSelect() and ppsOutputSelect()) before trying to use the peripheral if that peripheral is not connected to the pin you want by default. See the example code on the Fubarino Mini Github site for more detailed information.

## Pin Reference

This table provides a cross reference of all functions and labels for each pin of the Fubarino Mini. Note that the ‘Fubarino Pin’ is the pin number of the whole board (as if the whole thing were one large DIP chip), starting with pin 1 = Vout, and correspond to the J1 and J2 pin numbers in the schematic. The ‘Arduino Pin’ is the pin number you use in your code and is what is listed on the silk screen of the board. (Note that the Mini is too small for all pins to have numbers printed next to each pin – so use the diagram above to see the pin number for every pin on the board.) Make sure to never put more than 3.3V into any pin that is not 5V tolerant, as that will damage the PIC32 CPU.

The Arduino pins 14, 15, 16, 23, 31 and 32 are taken up with existing functions in the default configuration and are not available for GPIO use unless the configuration is changed.

Fubarino Pin | Arduino Pin | Analog | PIC32 Pin | Silk Name | Alt functions | 5V tolerant?
J1-1 | - | - | - | Vout | - | -
J1-2 | - | - | - | G | GND | -
J1-3 | - | - | - | 3V | - | -
J1-4 | Pin 0 | Yes (A0) | RB13 | 0 | AN11/RPB13/CTPLS/PMRD/INT2 | No
J1-5 | Pin 1 | - | RA10 | 1 | PGED/TMS/PMA10 (LED) | Yes
J1-6 | Pin 2 | - | RA7 | 2 | PGEC/TCK/CTED8/PMA7 | Yes
J1-7 | Pin 3 | Yes (A1) | RB14 | 3 | CVREF/AN10/C3INB/RPB14/VBUSON/ SCK1/CTED5/INT1 | No
J1-8 | Pin 4 | Yes (A2) | RB15 | 4 | AN9/C3INA/RPB15/SCK2/CTED6/PMCS1/INT4 | No
J1-9 | Pin 5 | Yes (A3) | RA0 | 5 | PGED3/VREF+/CVREF+/AN0/C3INC/ RPA0/CTED1/PMD7 | No
J1-10 | Pin 6 | Yes (A4) | RA1 | 6 | PGEC3/VREF-/CVREF-/AN1/RPA1/ CTED2/PMD6/INT3 | No
J1-11 | Pin 7 | Yes (A5) | RB0 | 7 | PGED1/AN2/C1IND/C2INB/C3IND/ RPB0/PMD0 | No
J1-12 | Pin 8 | Yes (A6) | RB1 | 8 | PGEC1/AN3/C1INC/C2INA/RPB1/ CTED12/PMD1 | No
J1-13 | Pin 9 | Yes (A7) | RB2 | 9 | AN4/C1INB/C2IND/RPB2/SDA2/ CTED13/PMD2 | No
J1-14 | Pin 10 | Yes (A8) | RB3 | 10 | AN5/C1INA/C2INC/RTCC/RPB3/SCL2/ PMWR/CNB3 | No
J1-15 | Pin 11 | Yes (A9) | RC0 | 11 | AN6/RPC0 | No
J1-16 | Pin 12 | Yes (A10) | RC1 | 12 | AN7/RPC1 | No
J2-17 | Pin 13 | Yes (A11) | RC2 | 13 | AN8/RPC2/PMA2 | No
J2-18 | Pin 14 | - | RA2 | 14 | OSC1/CLKI/PRA2 (used - crystal) | No
J2-19 | Pin 15 | - | RA3 | 15 | OSC2/CLKO/RPA3 (used - crystal) | No
J2-20 | Pin 16 | - | RA8 | 16 | TDO/RPA8/PMA8 (PRG button) | Yes
J2-1 | Pin 17 | - | RB4 | 17 | SOSCI/PRB4 | No
J2-2 | Pin 18 | - | RA4 | 18 | SOSCO/RPA4/T1CK/CTED9 | No
J2-3 | Pin 19 | - | RA9 | 19 | TDI/RPA9/PMA9 | Yes
J2-4 | Pin 20 | Yes (A12) | RC3 | 20 | AN12/RPC4 | No
J2-5 | Pin 21 | - | RC4 | 21 | RPC4/PMA4 | Yes
J2-6 | Pin 22 | - | RC5 | 22 | RPC5/PMA3 | Yes
J2-7 | Pin 23 | - | RB5 | 23 | PRB5/USBID (used - USB) | Yes
J2-8 | Pin 24 | - | RB7 | 24 | RPB7/CTED3/PMD5/INT0 | Yes
J2-9 | Pin 25 | - | RB8 | 25 | RPB8/SCL1/CTED10/PMD4 | Yes
J2-10 | Pin 26 | - | RB9 | 26 | RPB9/SDA1/CTED4/PMD3 | Yes
J2-11 | Pin 27 | - | RC6 | 27 | RPC6/PMA1 | Yes
J2-12 | Pin 28 | - | RC7 | 28 | RPC7/PMA0 | Yes
J2-13 | Pin 29 | - | RC8 | 29 | RPC8/PMA5 | Yes
J2-14 | Pin 30 | - | RC9 | 30 | RPC9/CTED7/PMA6 | Yes
J2-15 | Pin 31 | - | RB10 | 31 | PGED2/RPB10/D+/CTED11 (used - USB) | No
J2-16 | Pin 32 | - | RB11 | 32 | PGEC2/RPB11/D- (used - USB) | No
J2-17 (v1.5) | - | - | - | G | Do not use (reserved for future use) | -
J2-17 (v2.0) | | | MCLR | RS | Master Clear (reset) | -
J2-18 | - | - | - | 3V | 3.3V | -
J2-19 | - | - | - | G | GND | -
J2-20 | - | - | - | Vin | Vin | -

## Schematic

For the v1.5 schematic, please see the Fubarino_Mini_v15_sch.pdf (https://github.com/fubarino/fubarino.github.com/blob/master/mini/v15/FubarinoMini_v15_sch.pdf?raw=true) file on the Fubarino Mini website. https://github.com/fubarino/fubarino.github.com/blob/master/mini/v15/FubarinoMini_v15_sch.pdf?raw=true

For the v2.0 schematic, please see the Fubarino_Mini_v20_sch.pdf (https://github.com/fubarino/fubarino.github.com/blob/master/mini/v20/FubarinoMini_v20_schematic.pdf?raw=true) file on the Fubarino Mini website. https://github.com/fubarino/fubarino.github.com/blob/master/mini/v20/FubarinoMini_v20_schematic.pdf?raw=true

## Default Peripherals

There are several hardware peripherals that, by default, are mapped to certain pins.

### PWM

The Arduino analogWrite() function turns on hardware PWM on certain pins. By default, the pins of the Fubarino Mini that can output hardware PWM with the analogWrite() function are 0, 4, 7, 8 and 9.

### Interrupts

The Arduino attachInterrupt() function is used to connect a software function to one of five hardware interrupts.

Interrupt Pins
Digital Pin | Function
24 (PIN_INT0) | INT0
3 (PIN_INT1) | INT1
0 (PIN_INT2) | INT2
4 (PIN_INT3) | INT3
5 (PIN_INT4) | INT4

The attachInterrupt() function takes three arguments. The first is an interrupt number, the second is the function to call and the third is the edge to interrupt on (RISING or FALLING). You can use the digitalPinToInterrupt() function to look up which interrupt number a given pin has been assigned. For example, if you wanted to have the foo() function called on the rising edge of PIN_INT3, write:

attachInterrupt(digitalPinToInterrupt(PIN_INT3), foo, RISING);

While only INT0 is on a fixed pin, and INT1 through INT4 can be changed using PPS, the chipKIT core function attachInterrupt() will always re-set INT1 through INT4 to the above digital pins each time you call it.

### SPI

While the Fubarino Mini has 2 SPI ports, the standard Arduino SPI library <SPI.h> only allows the use of one. On the Fubarino Mini, the SPI port used for this library is SPI1, which uses the following pins:

SPI1 – Default SPI Port for SPI.h and DSPI.h
Digital Pin | Function | Changeable?
3 | SCK (clock) | No
18 | MOSI (SDO) | Yes - via PPS
19 | MISO (SDI) | Yes – via PPS
5 | SS (slave select/chip select) | Yes – any GPIO pin

The DSPI library (<DSPI.h>) allows the use of both SPI ports – both SPI1 and SPI2. These are the pins used for SPI2:

SPI2 – (DSPI only)
Digital Pin | Function | Changeable?
4 | SCK (clock) | No
29 | MOSI (SDO) | Yes - via PPS
28 | MISO (SDI) | Yes – via PPS
30 | SS (slave select/chip select) | Yes – any GPIO pin

## More Information

The best places to get support for Fubarino Mini are

- Main chipKIT website (http://chipkit.net/)
- chipKIT forum (http://www.chipkit.org/forum/index.php)

## License

The Fubarino series of boards are released by Schmalz Haus LLC and FubarLabs under a Solderpad Hardware License v0.51. For more information, see: http://solderpad.org/licenses/SHL-0.51/

## Developers

The Fubarino series of boards were developed by Rick Anderson of FubarLabs (http://www.fubarlabs.org/) and Brian Schmalz of Schmalz Haus LLC (http://www.schmalzhaus.com/). They are registered chipKITTM boards and are designed to be programmed with the MPIDE system.

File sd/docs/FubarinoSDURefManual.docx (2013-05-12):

# FubarinoTM SD Reference Manual

Last Revision: May 11th, 2013

## Introduction:

The FubarinoTM SD is a small microcontroller board that uses a powerful PIC32 microcontroller. It is chipKITTM/MPIDE compatible and can run the same sketches that run on an ArduinoTM. It is designed to have all I/O pins on either side of the board in a traditional DIP pattern so that it can easily be plugged into a breadboard. It has a USB connector for power, programming, and a connection to a PC. It also has a microSD slot for increased storage.

Features:

- PIC32MX440F256H (Fubarino SD v1.4) or PIC32MX795F512H (Fubarino SD v1.5) microcontroller, which includes either 256KB or 512KB Flash and 32K or 128KB of RAM
- Supported as development target from within MPIDE
- 45 I/O pins
- microSD slot connected to hardware SPI port
- Pads for 32 KHz crystal
- USB connector for power, programming, and connection to PC (serial, mass storage, etc.)
- Two buttons: RESET for resetting the board, and PRG for getting into bootloader mode and user application use
- USB bootloader pre-programmed at the factory – no other hardware needed to program board


Figure 1 : FubarinoSD Pin Map

## Entering Bootloader Mode

To enter bootloader mode (also called programming mode) simply press the PRG button while pressing and releasing the RESET button. As long as the PRG button is held down when the RESET button is released, the bootloader will start waiting for a new program to be downloaded over USB. It will wait indefinitely.

The bootloader on the Fubarino SD implements the avrdude STK500 v2 protocol, just like the other chipKITTM/MPIDE boards.

## Programming in MPIDE

To program the Fubarino SD board from within MPIDE, simply download the latest MPIDE version, http://chipkit.net/started/install-chipkit-software/, unzip and run it, and select Fubarino SD from the Tools->Boards->Fubarino menu. Then, put the Fubarino SD into bootloader mode (see above), and then select the proper serial port in the Tools->Serial Port menu.

After you enter your sketch and click the Upload button, MPIDE will compile your sketch and then upload it to the Fubarino SD. After the upload is complete, the Fubarino SD will automatically reset and immediately begin running your sketch code. This includes sending information to the USB serial, UART1, and UART2.

## Serial communications

The Fubarino SD board has two hardware serial ports: UART2 on pins 29 (TX) and 28 (RX), and UART1 on pins 9 (TX) and 8 (RX). It also has a USB serial port that operates as the default serial port. See the Code Examples wiki page on the Fubarino SD website for example sketch code on how to uses the three serial ports.

- USB serial init: Serial.begin()
- On board serial1 pins 8 (RX), 9 (TX): Serial0.begin()
- On board serial2 pins 28 (RX), 29 (TX): Serial1.begin()

## Using the microSD

The Fubarino SD has a single SPI port, which is tied to the microSD memory card slot as well as pins 24 through 27. The standard SD library that comes with MPIDE will work with the FubarinoSD microSD slot without modifications.

## Power

The Fubarino SD can be powered in a number of different ways.

1. USB : When 5V are present on the USB connector (from a PC or a powered hub for example), the FubarinoSD will use this power source. This power source has a reverse protection diode connection to the 3.3V regulator. If both USB and Vin are powered, whichever is higher will end up providing the power to the regulator.
2. Vin pin: You can also place 2.8V to 13.2V on the Vin pin to power it from an external power source. This power source has a reverse protection diode connection to the 3.3V regulator. If both USB and Vin are powered, whichever is higher in voltage will power the device.
3. 3.3V pin(s): You can power the FubarinoSD by connecting a 3.3V source to either 3.3V pin. You must be careful not to exceed 3.6V on these pins or the PIC32 will be destroyed.

## Fubarino SD Versions

Fubarino SD versions 1.0 to 1.3 were not produced in any number and were not widely distributed.

Fubarino SD version 1.4 is being manufactured and sold by SeeedStudio (http://www.seeedstudio.com/depot/fubarino-sd-p-1265.html?cPath=132_208). It uses the PIC32MX440F256H processor, which has 256KB of Flash and 32KB of RAM. Because the memory size is different from other Fubarino SD boards, if you have this version of the board, you should use the “Fubarino SD (Seesd)” board in the MPIDE Boards->Fubarino menu.

Fubarino SD v1.5 was the first version Microchip built, and uses a PIC32MX795F512H PIC32 part. This part has 512KB of Flash and 128KB of RAM. Make sure to select “Fubarino SD” from the MPIDE Boards->Fubarino menu for version 1.5 boards.

## Pin Reference

This table provides a cross reference of all functions and labels for each pin of the Fubarino SD. Note that the ‘Fubarino Pin’ is the pin number of the entire board, starting with pin 1 = Vout and correspond to the J2 and J3 pin numbers in the schematic. The ‘Arduino Pin’ is the pin number you use in your code, and is what is listed on the silk screen of the board.

Fubarino Pin | Arduino Pin | Analog | PIC32 Pin | Silk Name | Alt functions | 5V tolerant?
J2-1 | - | - | - | Vout | - | -
J2-2 | - | - | - | Gnd | - | -
J2-3 | - | - | - | 3.3V | - | -
J2-4 | Pin 0 | - | RD8 | 0 | RTCC/IC1/INT1 | Yes
J2-5 | Pin 1 | - | RD9 | 1 | U1CTS/SDA1/IC2/INT2 | Yes
J2-6 | Pin 2 | - | RD10 | 2 | SCL1/IC3/PMCS2/PMA15/INT3 | Yes
J2-7 | Pin 3 | - | RD11 | 3 | IC4/PMCS1/PMA14/INT4 | Yes
J2-8 | Pin 4 | - | RD0 | 4 | OC1/INT0/RD0 | Yes
J2-9 | Pin 5 | - | RC13 | 5 | SOSCI/CN1 | No
J2-10 | Pin 6 | - | RC14 | 6 | SOSCO/T1CK/CN0 | No
J2-11 | Pin 7 | - | RD1 | 7 | U1RTS/OC2 | Yes
J2-12 | Pin 8 | - | RD2 | 8 | U1RX/OC3 | Yes
J2-13 | Pin 9 | - | RD3 | 9 | U1TX/OC4 | Yes
J2-14 | Pin 10 | - | RD4 | 10 | OC5/IC5/PMWR/CN13 | Yes
J2-15 | Pin 11 | - | RD5 | 11 | PMRD/CN14 | Yes
J2-16 | Pin 12 | - | RD6 | 12 | CN15 | Yes
J2-17 | Pin 13 | - | RD7 | 13 | CN16 | Yes
J2-18 | Pin 14 | - | RF0 | 14 | | Yes
J2-19 | Pin 15 | - | RF1 | 15 | | Yes
J2-20 | Pin 16 | - | RE0 | 16 | PMD0 | Yes
J2-21 | Pin 17 | - | RE1 | 17 | PMD1 | Yes
J2-22 | Pin 18 | - | RE2 | 18 | PMD2 | Yes
J2-23 | Pin 19 | - | RE3 | 19 | PMD3 | Yes
J2-24 | Pin 20 | - | RE4 | 20 | PMD4 | Yes
J2-25 | Pin 21 | - | RE5 | 21 | PMD5 | Yes
J2-26 | Pin 22 | - | RE6 | 22 | PMD6 | Yes
J2-27 | Pin 23 | - | RE7 | 23 | PMD7 | Yes
J2-28 | - | - | - | GND | - | -
J3-1 | - | - | - | GND | - | -
J3-2 | Pin 24 | - | RG6 | SCK/24 | SCK2/PMA5/CN8 | Yes
J3-3 | Pin 25 | - | RG7 | SDI/25 | SDI2/PMA4/CN9 | Yes
J3-4 | Pin 26 | - | RG8 | SDO/26 | SDO2/PMA3/CN10 | Yes
J3-5 | Pin 27 | - | RG9 | SCK/27 | SS2/PMA2/CN11 | Yes
J3-6 | Pin 30 | A14 | RB4 | A14 | AN4/C1IN-/CN6 | No
J3-7 | Pin 31 | A13 | RB3 | A13 | AN3/C2IN+/CN5 | No
J3-8 | Pin 32 | A12 | RB2 | A12 | AN2/C2IN-/CN4 | No
J3-9 | Pin 33 | A11 | RB1 | A11 | PGEC1/AN1/VREF-/CVREF-/CN3 | No
J3-10 | Pin 34 | A10 | RB0 | A10 | PGED1/AN0/VREG+/CVREF+/PMA6/CN2 | No
J3-11 | - | - | MCLR | RST | MCLR | Yes
J3-12 | - | - | - | 3.3V | - | -
J3-13 | - | - | - | GND | - | -
J3-14 | Pin 35 | A9 | RB7 | A9 | PGED2/AN7 | No
J3-15 | Pin 36 | A8 | RB6 | A8 | PGEC2/AN6/OCFA | No
J3-16 | Pin 37 | A7 | RB8 | A7 | AN8/U2CTS/C1OUT | No
J3-17 | Pin 38 | A6 | RB9 | A6 | AN9/C2OUT/PMA7 | No
J3-18 | Pin 39 | A5 | RB10 | A5 | TMS/AN10/CVREFOUT/PMA13 | No
J3-19 | Pin 40 | A4 | RB11 | A4 | TDO/AN11/PMA12/RB11 | No
J3-20 | Pin 41 | A3 | RB12 | A3 | TCK/AN12/PMA11 | No
J3-21 | Pin 42 | A2 | RB13 | A2 | TDI/AN13/PMA10 | No
J3-22 | Pin 43 | A1 | RB14 | A1 | AN14/U2RTS/PMALH/PMA1 | No
J3-23 | Pin 44 | A0 | RB15 | A0 | AN15/OCFB/PMALL/PMA0/CN12 | No
J3-24 | Pin 28 | - | RF4 | RX/28 | SDA2/U2RC/PMA9/CN17 | Yes
J3-25 | Pin 29 | - | RF5 | TX/29 | SCL2/U2TX/PMA8/CN18 | Yes
J3-26 | - | - | - | 3.3V | - | -
J3-27 | - | - | - | GND | - | -
J3-28 | - | - | - | Vin | - | -

## Schematic

For the schematic, please see the Fubarino_SD_v15_sch.pdf file on the Fubarino SD website. https://github.com/fubarino/fubarino.github.com/blob/master/sd/v1.5/Fubarino_SD_v15.sch?raw=true

## More Information

The best places to get support for Fubarino Mini are

- Main chipKIT website (http://chipkit.net/)
- chipKIT forum (http://www.chipkit.org/forum/index.php)

## License

The Fubarino series of boards are released by Schmalz Haus LLC and FubarLabs under a Solderpad Hardware License v0.51. For more information, see: http://solderpad.org/licenses/SHL-0.51/

## Developers

The Fubarino series of boards were developed by Rick Anderson of FubarLabs (http://www.fubarlabs.org/) and Brian Schmalz of Schmalz Haus LLC (http://www.schmalzhaus.com/). They are registered chipKITTM boards and are designed to be programmed with the MPIDE system.

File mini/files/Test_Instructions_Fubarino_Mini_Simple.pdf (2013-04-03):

# Functional Test Procedure – Simple Version

for Fubarino Mini

To be used with FubarinoMini_ManufactureTest_Simple.pde v1.1

Components:

For the test procedure, the following are needed:

1) Assembled Fubarino Mini board
2) Some method of programming the PIC32 (Like a PICKit3)
3) PC with mini B USB cable and terminal emulator
4) Fubarino Mini HEX file (like BL_1_0_8_FuncTest_1_1_48Mhz.hex)

Overview:

This test procedure is to be run after the Fubarino Mini board has been manufactured. It will confirm proper operation of some of the parts of the board. The actual testing is broken down into 4 separate tests:

1) Power on LED test
2) USB test
3) Button/LED test
4) Bootloader entry test

Procedure:

The Fubarino Mini board must be programmed with the latest HEX file. The latest HEX file available is BL_1_0_8_FuncTest_1_1_48Mhz.hex, which indicates that it contains Bootloader version 1.0.8 and Functional Test sketch v1.1. A PICKit3 can be plugged into the 5-pins at the end of the Fubarino Min opposite the USB connector and the PICKit3 can then program the HEX file onto the PIC32 processor. Other programmers can be used, of course, or the parts could be pre-programmed.

1) Power on LED test:

Once the board is programmed, plug in the USB cable to the PC and to the Fubarino Mini board. This will apply power and start the test running. The first thing that should happen is the red power LED should come on. The green LED will also turn blink once. This indicates that the first test (Power on LED test) has passed. If the green LED does not blink once, or the red LED does not come on, then there is a problem with the power supply, or the crystal, or the programming of the HEX file into the part.

2) USB Test

At this point, the test operator waits until the LED is on solid then opens the serial port on the test computer with a terminal emulator. The test will print "Press Enter" over and over to the serial port. When the test program sees an ‘Enter’ press from the terminal emulator, it will print "USB test PASSED". Make sure the terminal emulator being used is sending Carriage Returns (0x0D). If this test passes, it means that the PIC32 is clocking at the right frequency (or USB would not work), and that the USB connector is soldered on properly.

3) Button/LED test

The test operator should now see the green LED blink where the on-time is about 800ms and the off time is about 200ms. If the test operator pushes down the PRG button, the blinking will stop. This indicates proper operation of the PRG button and the green LED.

4) Bootloader entry test

The test operator must then press the PRG button, press and release the RESET button, then release the PRG button. This will test both buttons, and place the board into bootloader mode. The red LED should be on, and the green LED should be blinking rapidly on and off. This indicates proper entry into bootloader mode.

If the main test sketch is entered (green LED blinks once, then turns on solid) then this test has failed because the bootloader was not entered properly.

Once all of the tests have passed, the test operator can remove the USB cable from the Fubarino Mini.

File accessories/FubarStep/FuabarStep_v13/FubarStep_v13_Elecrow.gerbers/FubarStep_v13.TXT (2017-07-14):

%
M48
M72
T01C0.01300
T02C0.01500
T03C0.02756
T04C0.03150
T05C0.03200
T06C0.03543
T07C0.03937
T08C0.04000
T09C0.04724
T10C0.12598
T11C0.13000
%
T01
X155350Y57833
X165350Y59333
X205350Y62333
X215350Y62333
X245350Y115833
X240350Y117333
X240350Y128333
X245350Y128333
X230350Y128333
X225350Y128333
X215350Y128333
X205350Y128333
X195350Y128333
X190350Y128333
X185350Y128333
X175350Y131333
X170350Y131333
X165350Y131333
X160350Y131333
X155350Y131333
X150350Y131333
X145350Y131333
X140350Y131333
X135350Y131333
X125350Y138333
X250350Y172333
X260350Y175333
X335350Y160333
X361350Y143333
X349350Y139833
X342850Y140833
X349350Y135333
X349350Y131333
X342850Y130333
X361350Y133333
X359850Y103333
X359850Y93333
X345350Y89333
X352850Y47333
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

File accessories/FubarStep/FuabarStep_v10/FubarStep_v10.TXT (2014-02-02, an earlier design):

%
M48
M72
T01C0.0120
T02C0.0276
T03C0.0320
T04C0.0394
T05C0.0400
T06C0.0472
T07C0.1260
T08C0.1300
%
T01
X4150Y10833
X4150Y11833
X7150Y14133
X8150Y13633
X8650Y13633
X9150Y13633
X9650Y13483
X10150Y13483
X10400Y13233
X10650Y13483
X11150Y13483
X11450Y13233
X12650Y12833
X13150Y12833
X13650Y12833
X14150Y12833
X15150Y12833
X16150Y12833
X17150Y12833
X17650Y12833
X18150Y12833
X19150Y12833
X20150Y12833
X21150Y12833
X18650Y15083
X18150Y15083
X18150Y11033
X17650Y11033
X13650Y14683
X12650Y13933
X11450Y14683
X10400Y14683
X9650Y14683
X8650Y14683
X15300Y6833
X15600Y6183
X15250Y5933
X16150Y6733
X16650Y6633
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

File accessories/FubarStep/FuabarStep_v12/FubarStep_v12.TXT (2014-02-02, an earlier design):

%
M48
M72
T01C0.0130
T02C0.0276
T03C0.0320
T04C0.0354
T05C0.0394
T06C0.0400
T07C0.0472
T08C0.1260
T09C0.1300
%
T01
X15535Y6983
X16535Y6983
X20535Y7233
X21135Y6733
X24035Y11083
X24535Y11083
X24535Y12833
X24035Y12833
X23035Y12833
X22535Y12833
X21535Y12833
X20535Y12833
X19535Y12833
X19035Y12833
X18535Y12833
X17535Y13133
X17035Y13133
X16535Y13133
X16035Y13133
X15535Y13133
X15035Y13133
X14535Y13133
X14035Y13133
X13535Y13133
X12535Y13833
X25035Y17233
X26035Y17333
X33535Y16033
X36135Y14333
X34935Y13983
X34285Y14083
X34935Y13533
X34935Y13133
X34285Y13033
X36135Y13333
X36185Y10333
X36185Y9333
X34535Y8833
X35285Y4733
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

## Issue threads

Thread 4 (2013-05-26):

"what would you like to see?"

mxmxmx, 2013-05-26:
sorry, didn't find another place to submit this...fubarino SD with dsPIC/DAC would be one of those things ..
ie http://www.microchip.com/wwwproducts/Devices.aspx?dDocName=en532310

Closed 2019-03-14.

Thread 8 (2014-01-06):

Real Time Clock on Fubarino SD

christophe-dupriez, 2014-01-06:
Hi! We are trying to take advantage of Fubarino SD RTC.
We changed the bootloader so the BoardConfig.h so we have now:
#pragma config FSOSCEN  = ON
within
#elif defined(_BOARD_FUBARINO_SD_512K_USB_)
We uploaded the new bootloader with an ICD3 and reuploaded the ChipKit sketch.
This sketch makes an GPRS transaction and get the date/time from the network.
This works.
But the time does not change within the RTC and we do not see the Cristal waves with an oscilloscope.
The class used is RTCC from Majenko.

Any idea would be very very welcome!

Christophe

EmbeddedMan, 2015-01-17:
This issue appears to have been solved - solution on the forum.

JacobChrist, 2015-01-19:
It would be nice to add a link to this thread to the form so that someone
searching the issue list can easily find the solution.

On Sat, Jan 17, 2015 at 8:22 AM, Brian Schmalz <notifications@github.com>
wrote:

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

--
Jacob Christ
*ProLinear/PONTECH, Inc.*
1-877-985-9286 Phone
1-413-235-1651 Fax
http://www.pontech.com

Closed 2015-01-17.

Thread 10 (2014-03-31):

Need binary /  instructions to reload bootloader on Fubarino SD

davidsmoot, 2014-03-31:
My company bought a half dozen or so Fubarino SD's for a rapid prototype for a customer and they worked great.  However I was running my own native PIC code, not MPIDE code.

My company has no more need for these prototypes and I want to use them to teach basic programming skills to a group of kids.  I want to be able to use them with MPIDE again.  Can you please post / provide binaries and instructions?  I have access to a Pickit  programmer as well as several ICD 3's.
Thanks,
David

EmbeddedMan, 2015-01-17:
I believe that the original question has been answered here so I'm going to close this issue.

Closed 2015-01-17.

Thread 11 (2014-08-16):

MISO/MOSI incorrect.

AtomSoftTech, 2014-08-16:
You have this:
SDO, MISO
SDI, MOSI

When its actually supposed to be:
SDO, MOSI
SDI, MISO

Here: https://github.com/fubarino/fubarino.github.com/wiki/SD-Board-Pin-Features

EmbeddedMan, 2015-01-17:
Since the documentation is now fixed, I believe, I'm going to close this issue.

Closed 2015-01-17.

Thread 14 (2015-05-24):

Document I2C pins for Fubarino SD

JacobChrist, 2015-05-24:
It looks like two I2C ports are called out on the diagram for the Fubarino SD, but its not clear which are SCL and SDA and which are the defaults for use with Wire.begin().

JacobChrist, 2015-05-24:
Actually, found SCL/SDA, but it still would be nice if it was on the SVG.  Can't but I still can't tell what is the default port for Wire.begin().

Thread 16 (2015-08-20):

not able to debug

Prasoon7777, 2015-08-20:
hi, in my fubarino mini board debugging is not working. but i am able to program the IC. while trying to debug it is showing an error message

"Programming/Verify complete"
"The target device is not ready for debugging. Please check your configuration bit settings and program the device before proceeding. The most common causes for this failure are oscillator and/or PGC/PGD settings."

here 8MHz crystal frequency is multiplied to 40MHz using PLL.
I am using MPlabX IDE. i am using PGED1 and PGEC1 for programming. i have also tried with PGED3 and PGEC3 but the result is same error message.
configuration bit settings that i am using is also given below

// PIC32MX250F128D Configuration Bit Settings

// 'C' source line config statements

#include <xc.h>

// DEVCFG3
// USERID = No Setting
#pragma config PMDL1WAY = OFF           // Peripheral Module Disable Configuration (Allow multiple reconfigurations)
#pragma config IOL1WAY = OFF            // Peripheral Pin Select Configuration (Allow multiple reconfigurations)
#pragma config FUSBIDIO = OFF           // USB USID Selection (Controlled by Port Function)
#pragma config FVBUSONIO = OFF          // USB VBUS ON Selection (Controlled by Port Function)

// DEVCFG2
#pragma config FPLLIDIV = DIV_2         // PLL Input Divider (2x Divider)
#pragma config FPLLMUL = MUL_20         // PLL Multiplier (20x Multiplier)
#pragma config UPLLIDIV = DIV_12        // USB PLL Input Divider (12x Divider)
#pragma config UPLLEN = OFF             // USB PLL Enable (Disabled and Bypassed)
#pragma config FPLLODIV = DIV_1         // System PLL Output Clock Divider (PLL Divide by 1)

// DEVCFG1
#pragma config FNOSC = PRIPLL           // Oscillator Selection Bits (Primary Osc w/PLL (XT+,HS+,EC+PLL))
#pragma config FSOSCEN = OFF            // Secondary Oscillator Enable (Disabled)
#pragma config IESO = OFF               // Internal/External Switch Over (Disabled)
#pragma config POSCMOD = HS             // Primary Oscillator Configuration (HS osc mode)
#pragma config OSCIOFNC = OFF           // CLKO Output Signal Active on the OSCO Pin (Disabled)
#pragma config FPBDIV = DIV_2           // Peripheral Clock Divisor (Pb_Clk is Sys_Clk/2)
#pragma config FCKSM = CSDCMD           // Clock Switching and Monitor Selection (Clock Switch Disable, FSCM Disabled)
#pragma config WDTPS = PS1048576        // Watchdog Timer Postscaler (1:1048576)
#pragma config WINDIS = OFF             // Watchdog Timer Window Enable (Watchdog Timer is in Non-Window Mode)
#pragma config FWDTEN = OFF             // Watchdog Timer Enable (WDT Disabled (SWDTEN Bit Controls))
#pragma config FWDTWINSZ = WINSZ_25     // Watchdog Timer Window Size (Window Size is 25%)

// DEVCFG0
#pragma config JTAGEN = ON              // JTAG Enable (JTAG Port Enabled)
#pragma config ICESEL = ICS_PGx1        // ICE/ICD Comm Channel Select (Communicate on PGEC1/PGED1)
#pragma config PWP = OFF                // Program Flash Write Protect (Disable)
#pragma config BWP = OFF                // Boot Flash Write Protect bit (Protection Disabled)
#pragma config CP = OFF                 // Code Protect (Protection Disabled)

EmbeddedMan, 2015-08-21:
I think I have found the problem.

You need to change
#pragma config FPLLODIV = DIV_1 // System PLL Output Clock Divider (PLL Divide by 1)
to
#pragma config FPLLODIV = DIV_2 // System PLL Output Clock Divider (PLL Divide by 1)

and then you'll be able to debug. If you look at Figure 6-1 in the Oscillators chapter (chapter 6) of the PIC32 reference manual, you can see that you're taking an 8Mz crystal (on the Fubarino), dividing it by 2 (FPLLIDIV), multiplying it by 20 to get 80MHz (FPLLMUL), then you were trying to use that 80MHz to run your part. These parts are only rated to 50Mhz, so that's why you need to then divide that 80Mhz down by 2 to get 40MHz (FPLLODIV). You can of course try to overclock it past it's rated speed, but then you may run into unexpected problems.

Let me know if that solves the problem for you or not.

*Brian

Prasoon7777, 2015-08-22:
@EmbeddedMan, Thanks for your valuable support. Its working fine and i am able to debug now.

~Prasoon.

EmbeddedMan, 2015-08-22:
Great! Closed-

Closed 2015-08-22.

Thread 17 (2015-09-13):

mini schematic shows possible error

bravo685, 2015-09-13:
On v1.6 mini schematic 5v is connected to pin 42 (vbus) on micro. What would happen if Vin was used and greater than max voltage allowed on vbus input at micro (+5.5v). I think this port should be changed to Vbus instead of the 5v port.

EmbeddedMan, 2015-09-13:
Yes, good find. I think you're spot on. I'll get that updated.

EmbeddedMan, 2015-09-13:
Version 1.7 has been created with this change.

bravo685, 2015-09-14:
Brian,
Thanks for the update.

One question though, doesn't the PIC32MX have an internal clock? Is this a
limitation do to MPIDE not able to set the configuration registrar bits?

Thanks,
Robert

On Sun, Sep 13, 2015 at 4:52 PM, Brian Schmalz <notifications@github.com>
wrote:

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

EmbeddedMan, 2015-09-14:
Robert,

Yes, the PIC32 does have an internal clock. However, it's not accurate
enough to use for USB - not on all systems anyway. So we have to use an
external crystal in order to have the accuracy required by USB.

MPIDE does not set configuration bits - that's done in the bootloader,
which is also available on Github if you want to compile it yourself. (It's
really easy.)

*Brian

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

JacobChrist, 2015-09-14:
Brian,

Do you know if the USB stability issue is unique to PIC32?  We have several
PIC18 boards that we use the internal oscillator with USB with no apparent
problem (can't say we have tested over temperature).

Jacob

On Mon, Sep 14, 2015 at 3:14 PM, Brian Schmalz <notifications@github.com>
wrote:

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

--
Jacob Christ
*ProLinear/PONTECH, Inc.*
1-877-985-9286 Phone
1-413-235-1651 Fax
http://www.pontech.com

bravo685, 2015-09-14:
Thanks Brian, Understood.

I would be interested in working with the bootloader. I looked over the
project on github and don't see it. Am I overlooking it?

On Mon, Sep 14, 2015 at 6:14 PM, Brian Schmalz <notifications@github.com>
wrote:

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

JacobChrist, 2015-09-14:
https://github.com/chipKIT32/PIC32-avrdude-bootloader

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

--
Jacob Christ
*ProLinear/PONTECH, Inc.*
1-877-985-9286 Phone
1-413-235-1651 Fax
http://www.pontech.com

EmbeddedMan, 2015-09-14:
Jacob,

No, the USB stability issue is not just a PIC32 issue. However, it's not a
blanket thing- you have to research the exact part, and the exact crystal,
in order to see if it will be good enough.

On my UBW board (which was PIC18F2553 based) the built-in RC oscillator was
nowhere near good enough - it wouldn't ever enumerate. So SparkFun built
the first several hundred UBW boards with an external resonator. I tested
many UBWs, and never once had a problem. But users started complaining that
their UBW boards would randomly not work, they had to plug into different
PCs to make them work, they would work for a while but then stop, etc. We
traced it down to the external resonator not being accurate enough to stay
in spec. So we had to move to a real crystal. That stopped all of our
problems.

There are some more recent PICs that have USB that actually get their own
clocks from the USB signal sent by the PC - thus they're always 'accurate'
enough and never need an external crystal.

So you have to do your homework and make sure your crystal and processor
will be in spec across all temps and over aging as well.

*Brian

On Mon, Sep 14, 2015 at 5:22 PM, Jacob Christ <notifications@github.com>
wrote:

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

JacobChrist, 2015-09-14:
Thanks Brian, good to know.

On Mon, Sep 14, 2015 at 3:52 PM, Brian Schmalz <notifications@github.com>
wrote:

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

--
Jacob Christ
*ProLinear/PONTECH, Inc.*
1-877-985-9286 Phone
1-413-235-1651 Fax
http://www.pontech.com

Closed 2015-09-13.

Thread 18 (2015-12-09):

JTAG programming?

cfriedt, 2015-12-09:
Hi, the PIC32 is fully JTAG programmable as well, and is even supported with OpenOCD.

Are the JTAG pins exposed on this device? Are there any other limitations that would make JTAG programming impossible?

cfriedt, 2015-12-09:
Viewing the schematic [here](https://github.com/fubarino/fubarino.github.com/raw/master/sd/v1.4/Fubarino_SD_v14_sch.pdf), I see that TDI, TDO, TCK, and TMS are not brought out. I would highly advise that you make JTAG available as well, as it greatly increases the size of your market for this product.

EmbeddedMan, 2015-12-09:
Christopher,

I'm not quite sure what you mean by 'not brought out' - all JTAG signals
are already available on the I/O headers. Anyone can hook up a JTAG
programmer/debugger to the Fubarino SD if they want to.

*Brian

On Wed, Dec 9, 2015 at 5:16 AM, Christopher Friedt <notifications@github.com
> wrote:

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

cfriedt, 2015-12-13:
Sorry - I misread the schematic. Looks like it does go to RB12, RB13, etc. Thanks!

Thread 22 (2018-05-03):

Fubarino SD error at address 1D0000FC: file=9D001264, mem=9D00126C

emcgill03, 2018-05-03:
Hi I am using a Fubarino SD board with arduino and code that has been previously working is now bringing up this error code, anyone have an idea of what it is?
Thanks

EmbeddedMan, 2018-05-03:
Hmm. Can you provide more details? What version of chipKIT-core are you
using? What sketch are you trying to compile? Does the error code come up
in the Arduino IDE when verifying, or only when downloading?

*Brian

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

emcgill03, 2018-05-03:
I was using chipkit version 1.4.3, I will try a newer version and see if that works. Its is a 'slaveUART 7 segment display' sketch and the error only comes up when downloading.

EmbeddedMan, 2018-05-03:
Would you be willing to share the sketch with me? I'd like to try to
reproduce the error (if you are able to make it happen with the latest
chipKIT-core) which I won't be able to do without the sketch.

*Brian

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

EmbeddedMan, 2018-05-03:
With chipKIT-core v2.0.3 installed in Arduino IDE 1.8.5, this sketch
compiles and downloads without error or warning for me on a FubarinoSD.

*Brian

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

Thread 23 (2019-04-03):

Fubarino Mini USB Serial drops out after download

lenhalio, 2019-04-03:
After downloading via the USB Serial port, the USB Serial port drops out and the application cannot re-establish the USB Serial connection (e.g. Serial(115200)) does not start and the USB serial link is not started even when "Serial" is selected in the IDE

EmbeddedMan, 2019-04-03:
Does the sketch you downloaded use the serial object?

JacobChrist, 2019-04-04:
In later versions of chipKIT-core the bootloader and application use
different USB VID/PID numbers. This causes the serial port to change on
Windows and Mac. I think it does not change on Linux because Linux always
assigns the next available port.  Check to see if the board exists on
another port after programming.

Jacob

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

lenhalio, 2019-04-04:
Hi Brian,

Yes, I instantiate the Serial object by Serial.begin(115200) and then use it later in the sketch by Serial(“Program Started”);

Just a simple “Blink program” :

#define LED_BUILTIN    1   // was13   Fubarino SD is pin 21, Fubarino Mini is pin 1

// the setup function runs once when you press reset or power the board
void setup() {

// intialize the serial ports and report interface type
	Serial.begin(115200);

	// initialize digital pin LED_BUILTIN as an output.
	pinMode(LED_BUILTIN, OUTPUT);
}

// the loop function runs over and over again forever
void loop() {
	digitalWrite(LED_BUILTIN, HIGH);   // turn the LED on (HIGH is the voltage level)
	Serial.println("LED ON");
	delay(5000);                       // wait for a second
	digitalWrite(LED_BUILTIN, LOW);    // turn the LED off by making the voltage LOW
	Serial.println("LED OFF");
	delay(5000);                       // wait for a second
}

This works for Fubarino SD just fine.

Regards,

Len

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

lenhalio, 2019-04-04:
Hi Jacob,

Thanks for your reply.

Yes, I did look to see if the Serial link came up on another port but it doesn’t seem that is the case.

But if the VID/PID numbers changed that would make sense…..expect that works fine for the Fubarino SD but the the Mini…crazy huh…

Regards,

Len

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

EmbeddedMan, 2019-04-04:
OK, that's good to know. Something strange is definitely going on here. What version of chipKIT-core are you using? And can you tell me what version of Fubarino Mini you have?

JacobChrist, 2019-04-04:
Len,

In the tools menu there are three USB options. I think Brian was eluding to
these being correctly set to Serial.

But if its working on an SD and not a Mini that is weird. There are several
Mini options 40Mhz, 48MHz, etc. Have you tried them all?

Jacob

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

lenhalio, 2019-04-04:
Sure….yes, I had set the USB options to Serial.

Not sure which version….is there a version number on the board.

Just bought a few from Microchip Direct….would that tell you which version?

I did try the 48 MHz bootloader but not the 50 MHz….

Regards,

Len

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

EmbeddedMan, 2019-04-04:
The ones from Microchip Direct will either be v1.5 or v2.0. It is printed
on the circuit board in white silk screen around the processor chip. The
v2.0s are *very* new, and maybe have problems yet?

There are no 50MHz Fubarino Minis (except at my desk I think, and possibly
a couple of other chipKIT devs), as they require a special bootloader.
Choosing 48MHz is the correct choice.

When you put your FBMini back into bootloader mode, are you still able to
get it to bootload new sketches?

*Brian

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

lenhalio, 2019-04-04:
Hi Brian,

The version is 1.5.   I assumed the boot loader that came with the board would be the right one but I did try the 48 MHz boot loader on another board….same issue.

Yes, there is no problem downloading the hex file and getting the code to execute…..just no output via the USB Serial port from the downloaded code.

I should mention that I am using UECIDE from Matt Majenko but since that works fine with the Fubarino SD I didn’t see that IDE as a problem.

Regards,

Len

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

EmbeddedMan, 2019-04-04:
Hmm. Any chance you could try Arduino IDE with chipKIT core? I wonder if
there's something strange going on with UECIDE? (I don't normally test with
UECIDE.)

*Brian

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

lenhalio, 2019-04-04:
It will take a while as I will have to download and set up the Arduino IDE but will try it and let you know.

Regards,

Len

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

lenhalio, 2019-04-04:
Hi Brian,

Got the Arduino IDE downloaded and set up.

Compiled and loaded the Blink program with no problem….runs fine

After the download, when I tried opening the Serial Monitor, I got the error message below:

Board at /dev/cu.usbmodem141101 is not available

This time, as Jacob suggested, there seemed to be another port.

When I connected to that port, sure enough the Serial messages appeared !!

But I am not seeing this new port using UECIDE……Hummm…..Matt, any ideas?

Regards,

Len

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

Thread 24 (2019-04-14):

Fubarino SD, High Voltage on Vout

JacobChrist, 2019-04-14:
So a common failure mode of the Fubarino SD and Mini is when students short 3.3V to GND (for too long).  This causes the regulator to go and the board to stop working.  So I sat down today to try and repair some five blown boards and found that the when powered with USB that Vout will have between 14-25VDC on it.  The 3.3V output will also have a large voltage and this has probably fried the processors too.  I suspect that the failed regulator, D1 and C3 are working together to form some kind of charge pump.  Very strange.

JacobChrist, 2019-04-14:
I removed the microcontroller and replaced the regulator.  With the microprocessor off the board, 5V on Vin. I get 28V on Vout and 3.3V.  Weird.  If I press either button (to add a little load) the voltage drops a couple of volts but still well above 20VDC.

JacobChrist, 2019-04-14:
Your gonna laugh.  My probe was on x1 and my scope on x10.  I'm shelving this problem for the moment.

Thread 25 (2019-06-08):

shorted Vout- will it recover

spicedreams, 2019-06-08:
Hi, I think I accidentally shorted Vout to GND with power on the board... it no longer boots, the power LED flickers a little.

Is there any way I can still use this board? a soft fuse or something that will heal over time?

Thanks

spicedreams, 2019-06-08:
for clarity, this is a Seeedstudio fubarino SD v1.4

JacobChrist, 2019-06-08:
This is a pretty common failure mode. I have about 10 boards that failed
for this same reason. I'm sure the voltage regulator fails and I think it
takes the processor with it.

Jacob

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

spicedreams, 2019-06-08:
Thanks Jacob. Guess I will have to add it to the scrap pile, unfortunately.

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

--
Best,

Graham
+64 27 275 4396

EmbeddedMan, 2019-06-09:
I concur with Jacob. From what you describe it's likely not worth trying to replace the chips on the board unless you have no easy to buy more.

Closed 2019-06-09.

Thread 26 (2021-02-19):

fubarino.github.com/mini/docs/FubarinoMini1_5Diagram.pdf

JacobChrist, 2021-02-19:
SPI SCK is on the wrong pin.  The picture in the manual appears to be correct (SCK on pin 3/RB14).

The PNG is also wrong:
fubarino.github.com/mini/docs/FubarinoMini1_5Diagram.png

The SVG does appear to be correct.

Probably just need to regenerate the pdf and png from the svg.

EmbeddedMan, 2021-02-20:
Confirmed. I will regenerate from the SVG.

Also v2.0 versions are needed (not that they are that different from v1.5)

EmbeddedMan, 2021-02-23:
Please check the PNG and PDF now. They should be correct. I've also included SVG, PDF and PNG files for FB Mini v2.0 in the same directory, although they're not linked to from anywhere yet. Let me know if you find any problems, or if they all look good, and I'll close this issue out.

ApiumJacob, 2021-02-24:
Looks good Brian!

Closed 2021-03-09.

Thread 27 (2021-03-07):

Fubarino Mini Interrupts

JacobChrist, 2021-03-07:
I'm working on an interrupt lab for the Fubarino Mini 2.0 for my class.

I have found that the macros PIN_INT0-4 are defined as the following in Board_Defs.h:

```
#define	PIN_INT0	24		// B7   non-PPS
#define	PIN_INT1	3		// B14  INT1R = RPB14 = 1
#define PIN_INT2	0		// B13  INT2R = RPB13 = 3
#define	PIN_INT3	6		// A1   INT3R = RPA1 = 0
#define	PIN_INT4	4		// B15  INT4R = RPB15 = 3
```

Board_Data.c has the following array defined:

```
const uint8_t external_int_to_digital_pin_PGM[] = {
	NOT_PPS_PIN,			// INT0 is not mappable
	PIN_INT1,				// INT1
	PIN_INT2,				// INT2
	PIN_INT3,				// INT3
	PIN_INT4				// INT4
};
```
If I use:
```
   attachInterrupt(PIN_INTx, isrX, MODE);
```
Where PIN_INTx is a defined interrupt pin and isrX is function that prints out a value if called that looks something like this:

```
void isr0()
{
  digitalWrite(LED_BUILTIN, !digitalRead(LED_BUILTIN)); // toggle pin 1
  Serial.println("ISR0");
}
```

 I find that:

PIN_INT1 is mapped to pin 6 RISING or FALING
PIN_INT2 is mapped to pin 24 RISING or FALING
PIN_INT4 is mapped to pin 4 RISING or FALING

None of the CHANGE interrupt modes work (there is no code to support this type in WInterrupts).

Also, PIN_INT0 and PIN_INT3 do not seem to be working, didn't dig too deep to understand why.

ricklon, 2021-03-08:
I've had the same issue for a long time.

For the Autonomous Vehicle project Foocars. I've got custom code for the
interrupts. I've been hoping we would support the change notice options to
be compatible with the rotary encoder code from Paul at Teensy.

Here's the example sketch with change notice:
https://github.com/fubarlabs/foocars/blob/master/cars/templatecar/arduino/FullAutoDrive-mini2/src/FullAutoDrive.ino
```

//This function pulls the data being populated by the input capture
interrupts.
//it corrects for the timer restarting.
inline int pulseRead(int RCindex){return
(pulseHighTime[RCindex]>0)?(int)(4.0*pulseHighTime[RCindex]/3.0):(int)(4.0*pulseHighTime[RCindex]/3.0+0xFFFF);}
//inline int pulseRead(int RCindex){return
(int)(0.8*pulseHighTime[RCindex]);}

//interrupt service routine for second input capture module
void __USER_ISR InputCaptureTHR_ISR(void) {
  static uint16_t risingEdgeTime = 0;
  static uint16_t fallingEdgeTime = 0;

  clearIntFlag(_INPUT_CAPTURE_4_IRQ);
  if (IC4CONbits.ICBNE == 1)
  {
    if (digitalRead(RC_INPUT_THR) == HIGH)
    {
      risingEdgeTime = IC4BUF;
      pulseLowTime[1] = risingEdgeTime - fallingEdgeTime;
    }
    else
    {
      fallingEdgeTime = IC4BUF;
      pulseHighTime[1] = fallingEdgeTime - risingEdgeTime;
    }
  }
}

//interrupt service routine for first input capture module
void __USER_ISR InputCaptureSTR_ISR(void) {
  static uint16_t risingEdgeTime = 0;
  static uint16_t fallingEdgeTime = 0;

  clearIntFlag(_INPUT_CAPTURE_1_IRQ);
  if (IC1CONbits.ICBNE == 1)
  {
    if (digitalRead(RC_INPUT_STR) == HIGH)
    {
      risingEdgeTime = IC1BUF;
      pulseLowTime[0] = risingEdgeTime - fallingEdgeTime;
    }
    else
    {
      fallingEdgeTime = IC1BUF;
      pulseHighTime[0] = fallingEdgeTime - risingEdgeTime;
    }
  }
}

void setup() {

    Serial.begin(9600);

    Serial.println( "Starting up..." );

    mapPps(0, PPS_IN_IC1);
    mapPps(10, PPS_IN_IC4);

        //setup input capture modules one and two
    IC1CON = 0;
    IC1CONbits.ICM = 1;   // Capture an interrupt on every rising and
falling edge
    IC1CONbits.ICTMR = 1; // Set to user Timer2
    IC1CONbits.ON = 1;    // Turn IC1 on

    IC4CON = 0;
    IC4CONbits.ICM = 1;   // Capture an interrupt on every rising and
falling edge
    IC4CONbits.ICTMR = 1; // Set to user Timer2
    IC4CONbits.ON = 1;    // Turn IC2 on

        /*We're using timer2 for the input capture. This shouldn't
interfere with pwm
          output, which uses timers 3-5.
        */
    PR2 = 0xFFFF;         // This tells timer 2 to count up to 0xFFFF,
after which it will restart at 0
    T2CONbits.TCKPS = 6;  // 1:64 prescale, which means 48MHz/64 or 0.75MHz
clock rate
    T2CONbits.TON = 1;    // Turn on Timer2

    pinMode(RC_INPUT_STR, INPUT);
    pinMode(RC_INPUT_THR, INPUT);
    pinMode(PIN_LED, OUTPUT);
    digitalWrite(PIN_LED, LOW);

        //these lines set up the interrupt functions to trigger
    setIntVector(_INPUT_CAPTURE_1_VECTOR, InputCaptureSTR_ISR);
    setIntPriority(_INPUT_CAPTURE_1_VECTOR, 4, 0);
    clearIntFlag(_INPUT_CAPTURE_1_IRQ);
    setIntEnable(_INPUT_CAPTURE_1_IRQ);

    setIntVector(_INPUT_CAPTURE_4_VECTOR, InputCaptureTHR_ISR);
    setIntPriority(_INPUT_CAPTURE_4_VECTOR, 4, 0);
    clearIntFlag(_INPUT_CAPTURE_4_IRQ);
    setIntEnable(_INPUT_CAPTURE_4_IRQ);
   }

void loop () {
  unsigned long STR_VAL = pulseRead(0); // Read pulse width of
   unsigned long THR_VAL = pulseRead(1); // each channel
}

```

I hope this is helpful.

--Rick

On Sun, Mar 7, 2021 at 2:26 PM Jacob Christ <notifications@github.com>
wrote:

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

--
Co-founder
Fair Use Building and Research (FUBAR) Labs
http://fubarlabs.org

EmbeddedMan, 2021-03-08:
Rick,

If you have a fix for the wrong interrupt pin definitions, could you submit
a PR to chipKIT to fix them?

*Brian

On Sun, Mar 7, 2021 at 8:46 PM Rick Anderson <notifications@github.com>
wrote:

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

ricklon, 2021-03-08:
I can try. I've only worked around it by using the code example above. If
that code is on the right track I could possibly figure out the problem.
But I don't really know, yet.

--Rick

On Sun, Mar 7, 2021 at 9:47 PM Brian Schmalz <notifications@github.com>
wrote:

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

--
Co-founder
Fair Use Building and Research (FUBAR) Labs
http://fubarlabs.org

EmbeddedMan, 2021-03-08:
No worries Rick. I'll work on it too and see if I can get things
straightened out.

*Brian

On Sun, Mar 7, 2021 at 8:54 PM Rick Anderson <notifications@github.com>
wrote:

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

ricklon, 2021-03-08:
My code was about using INPUT CAPTURE. It required mapping the pins via:
 ```
 mapPps(0, PPS_IN_IC1);
 mapPps(10, PPS_IN_IC4);
```

On Sun, Mar 7, 2021 at 9:56 PM Brian Schmalz <notifications@github.com>
wrote:

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

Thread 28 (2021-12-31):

Chip / memory discrepancy for Fubarino Mini 2.0 (chipKit-core V2.1.0)

JacobChrist, 2021-12-31:
I'm am prototyping a new board with the Fubarino Mini 2.0.  Both the [Fubarino Mini 2.0 web page](http://www.fubarino.org/mini2/index.html) and the [Microchip Direct web page](https://www.microchipdirect.com/dev-tools/TCHIP011?productLoaded=true&allDevTools=true) indicate that the board has a PIC32MX250F128D-50I/ML while the actual physical board in my possession and the linker scripts selected in the boards.txt file are for the PIC32MX270F256.

excerpt from boards.txt:
```
# Fubarini Mini v2.0

fubarino_mini_20.ccflags=-Map="map.map"
fubarino_mini_20.ldscript=chipKIT-application-32MX270F256.ld
```

I actually noticed the discrepancy when building the project and seeing that the Maximum program space didn't match the PIC32MX250F128D:

```
Sketch uses 29916 bytes (12%) of program storage space. Maximum is 245760 bytes.
Global variables use 7752 bytes (12%) of dynamic memory, leaving 55736 bytes for local variables. Maximum is 63488 bytes.
    Copyright: (C) 2011-2015 Serge Vakulenko
                   2016-2017 Majenko Technologies
Programmer for Microchip PIC32 microcontrollers, Version 2.1.46
      Adapter: STK500v2 Bootloader
 Program area: 1d000000-1d1fffff
    Processor: Bootloader
 Flash memory: 2048 kbytes
  Boot memory: 80 kbytes
         Data: 31220 bytes
        Erase: done
Program flash: .................................################################## done
 Verify flash: .................................################################# done
 Program rate: 6371 bytes per second
```

And a picture of the chip on my board:

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

EmbeddedMan, 2021-12-31:
Jacob, the first page of the FB Mini User Manual does talk about about both chips.

Probably the best solution is to have separate sets of board files for the different versions of FB Mini (v1.5 vs v2.0 and above).

JacobChrist, 2022-01-01:
So v1.5 is the 250 and v2.0 is the 270, the manual doesn't really make that clear either, but I get it.  Just adding a note here in case you want to fix it.

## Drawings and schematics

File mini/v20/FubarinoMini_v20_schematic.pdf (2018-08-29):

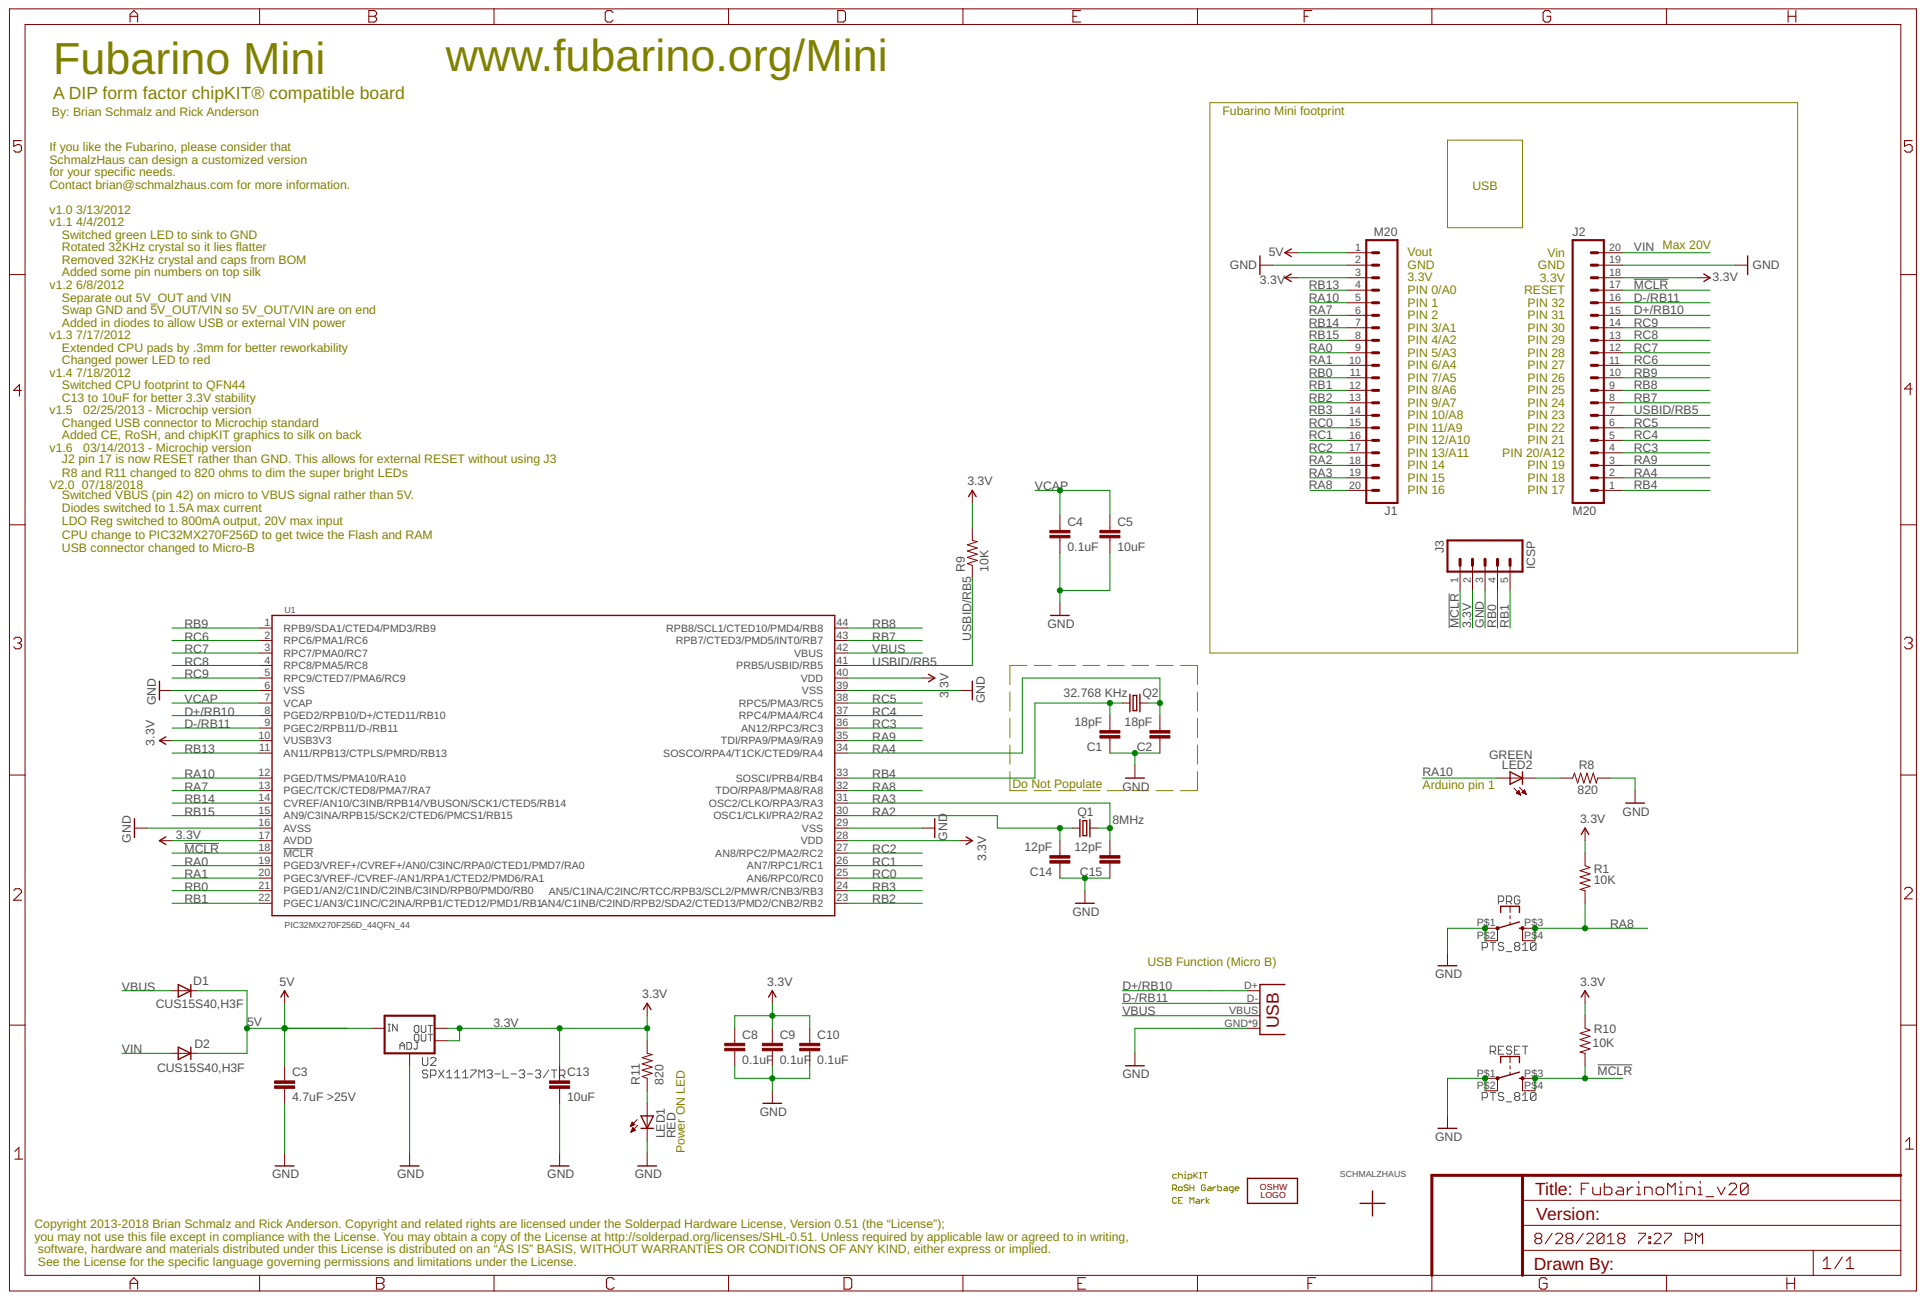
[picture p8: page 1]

A DIP form factor chipKIT® compatible board

By: Brian Schmalz and Rick Anderson

If you like the Fubarino, please consider that SchmalzHaus can design a customized version

for your specific needs. Contact brian@schmalzhaus.com for more information.

v1.1 4/4/2012 Switched green LED to sink to GND

Added some pin numbers on top silk
v1.2 6/8/2012 Added in diodes to allow USB or external VIN power v1.3 7/17/2012 Extended CPU pads by .3mm for better reworkability Swap GND and 5V_OUT/VIN so 5V_OUT/VIN are on end Separate out 5V_OUT and VIN

Changed power LED to red
v1.4 7/18/2012 Switched CPU footprint to QFN44 C13 to 10uF for better 3.3V stability

v1.5 02/25/2013 - Microchip version Changed USB connector to Microchip standard Added CE, RoSH, and chipKIT graphics to silk on back

v1.6 03/14/2013 - Microchip version
J2 pin 17 is now RESET rather than GND. This allows for external RESET without using J3 R8 and R11 changed to 820 ohms to dim the super bright LEDs

V2.0 07/18/2018 Switched VBUS (pin 42) on micro to VBUS signal rather than 5V. Diodes switched to 1.5A max current LDO Reg switched to 800mA output, 20V max input CPU change to PIC32MX270F256D to get twice the Flash and RAM

USB connector changed to Micro-B

Drawn By: Title: Version: OSHW
LOGO

Copyright 2013-2018 Brian Schmalz and Rick Anderson. Copyright and related rights are licensed under the Solderpad Hardware License, Version 0.51 (the “License”); you may not use this file except in compliance with the License. You may obtain a copy of the License at http://solderpad.org/licenses/SHL-0.51. Unless required by applicable law or agreed to in writing, software, hardware and materials distributed under this License is distributed on an “AS IS” BASIS, WITHOUT WARRANTIES OR CONDITIONS OF ANY KIND, either express or implied. See the License for the specific language governing permissions and limitations under the License.

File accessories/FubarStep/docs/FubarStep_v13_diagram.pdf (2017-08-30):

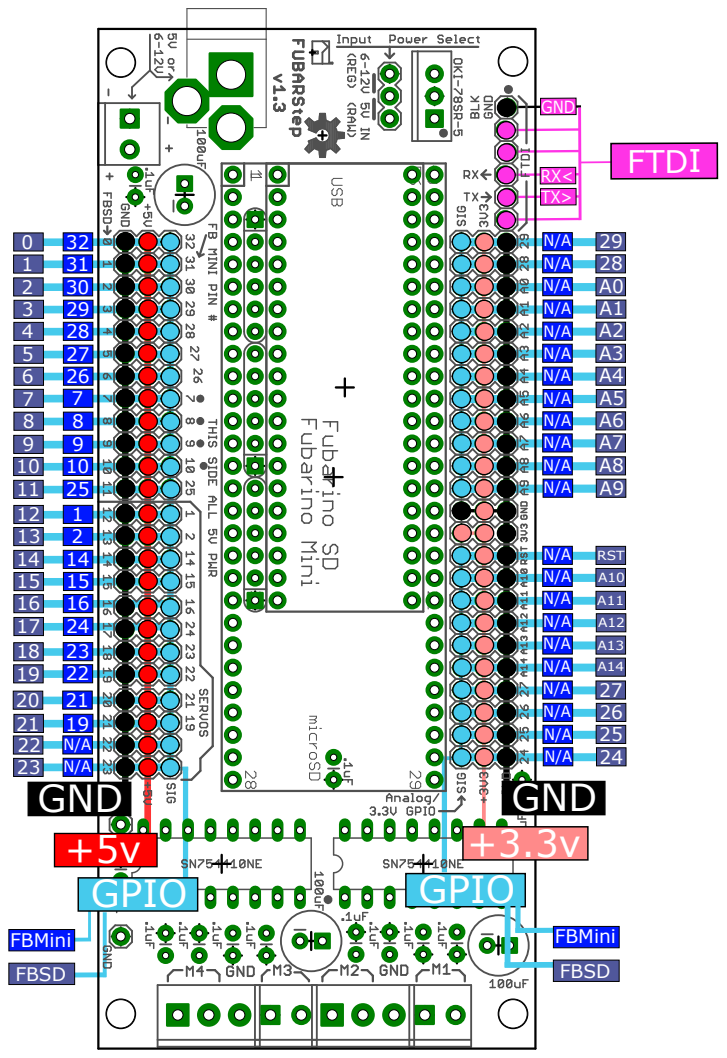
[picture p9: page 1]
RST; GND; FTDI; GPIO; FBMini FBSD

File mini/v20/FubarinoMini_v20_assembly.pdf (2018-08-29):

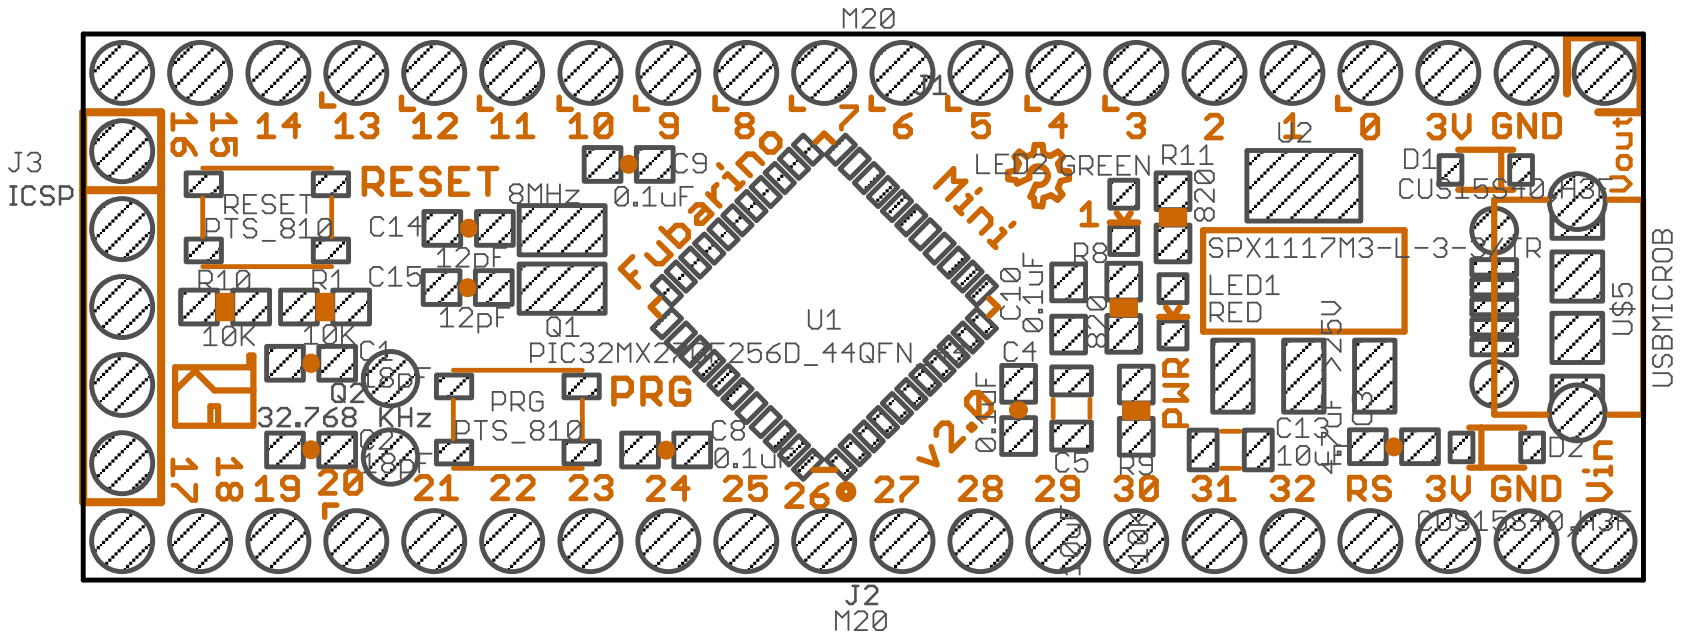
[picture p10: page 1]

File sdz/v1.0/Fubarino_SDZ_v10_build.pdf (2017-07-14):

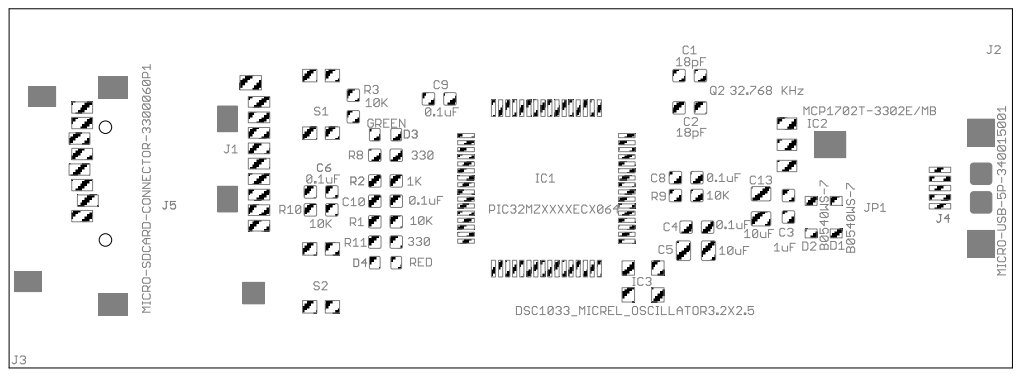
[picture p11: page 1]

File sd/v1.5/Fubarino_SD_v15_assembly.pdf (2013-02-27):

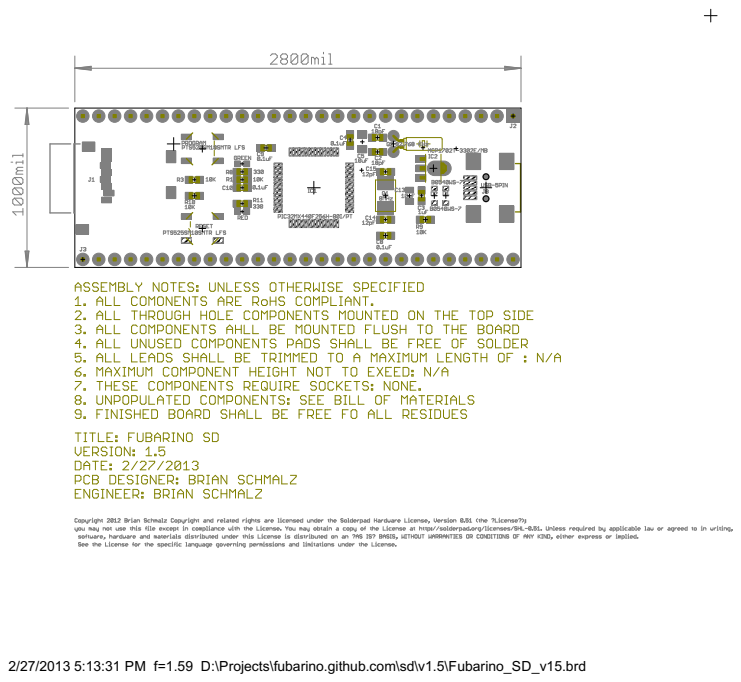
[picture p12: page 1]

2/27/2013 5:13:31 PM f=1.59 D:\Projects\fubarino.github.com\sd\v1.5\Fubarino_SD_v15.brd

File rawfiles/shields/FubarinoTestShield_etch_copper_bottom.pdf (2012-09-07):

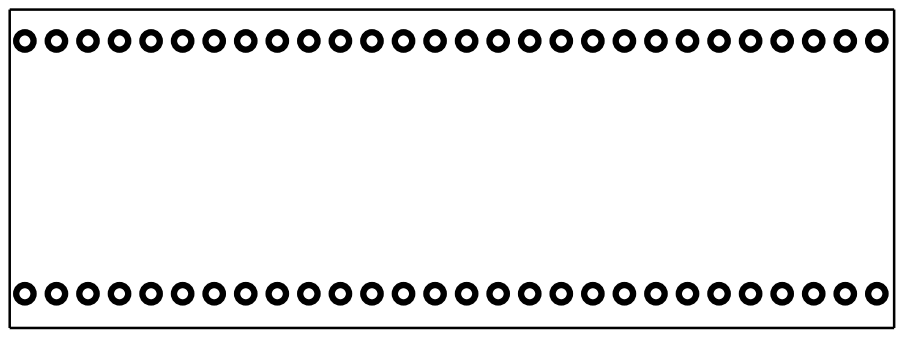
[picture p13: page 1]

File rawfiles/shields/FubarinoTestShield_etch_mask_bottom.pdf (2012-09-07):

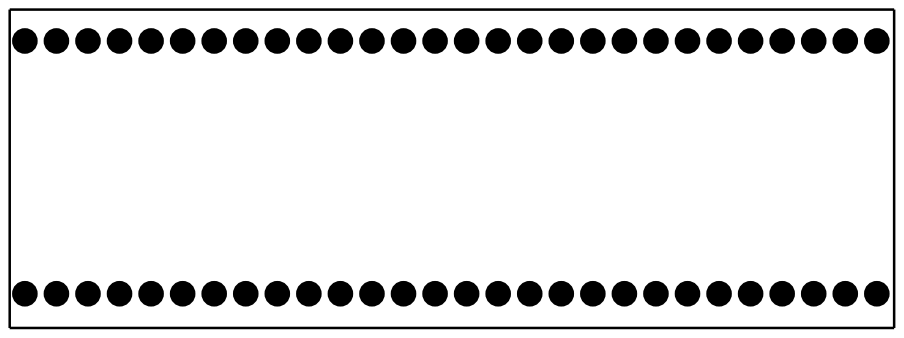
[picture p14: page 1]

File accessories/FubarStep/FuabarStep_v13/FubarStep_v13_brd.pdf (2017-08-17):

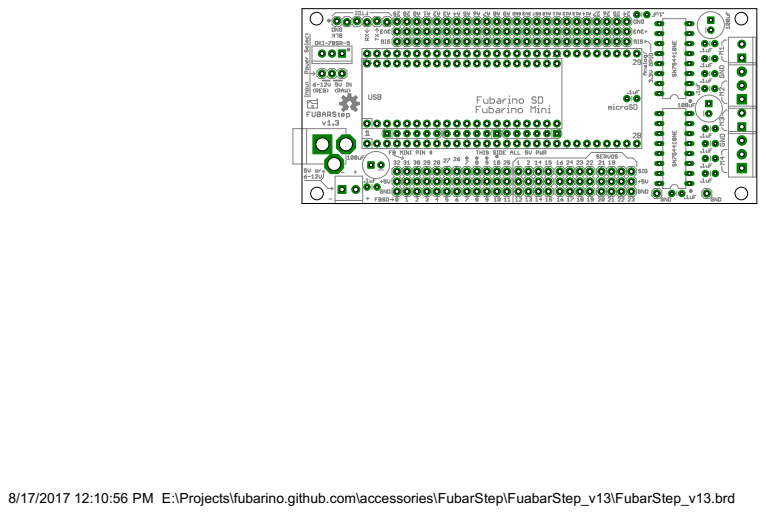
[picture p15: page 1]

8/17/2017 12:10:56 PM E:\Projects\fubarino.github.com\accessories\FubarStep\FuabarStep_v13\FubarStep_v13.brd

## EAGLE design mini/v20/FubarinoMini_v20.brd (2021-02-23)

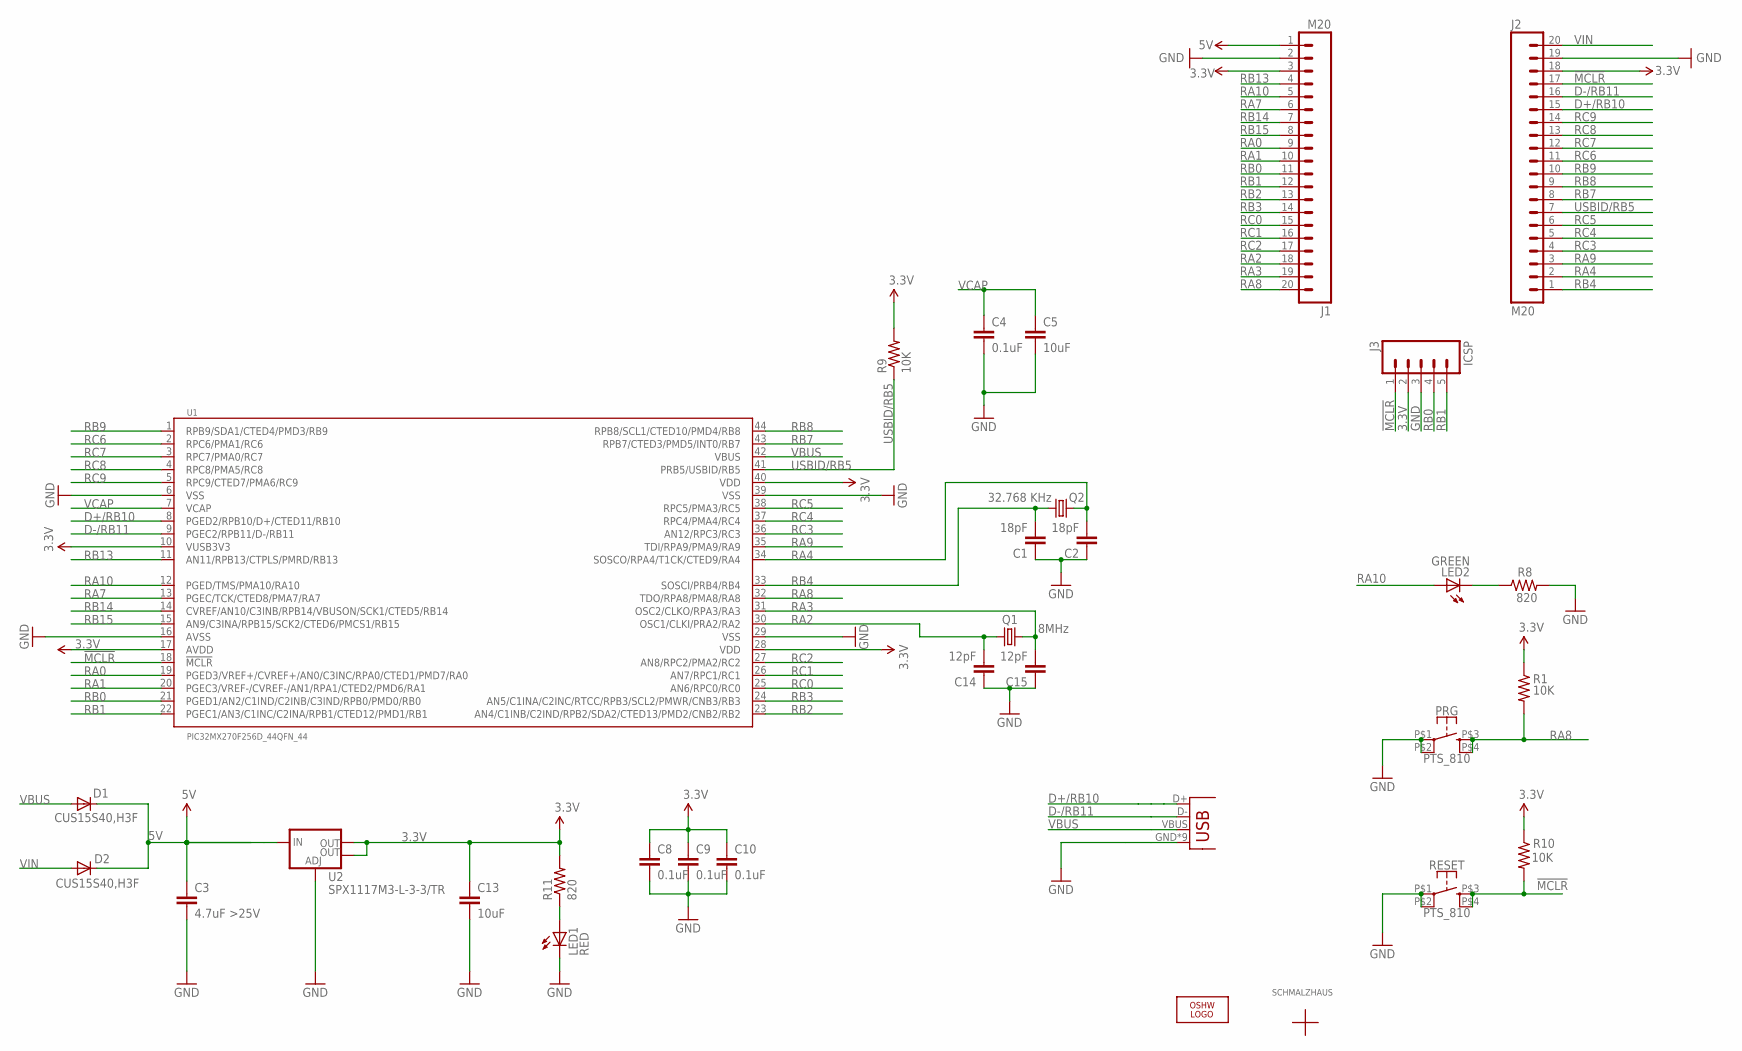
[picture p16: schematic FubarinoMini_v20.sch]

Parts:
C1, C2: 18pF; 0603-CAP
C3: 4.7uF >25V; 0603-CAP
C4, C8, C9: 0.1uF; 0603-CAP
C5, C13: 10uF; 0805
C10: 0.1uF; 0603
C14, C15: 12pF; 0603-CAP
D1, D2: CUS15S40,H3F; SOD-323
ICSP: J3; 1X05_NOSILK
J1, J2: M20; 1X20_NO_PIN1
LED1: RED; LED-0603
LED2: GREEN; LED-0603
LOGO1: OSHW_LOGO_8MILX0070-NT; OSHW_8X70_NOTEXT
PRG: PTS_810
Q1: 8MHz; NX3225GD
Q2: 32.768 KHz; TC26H
R1, R9, R10: 10K; 0603-RES
R8, R11: 820; 0603-RES
RESET: PTS_810
U1: PIC32MX270F256D_44QFN_44; QFN-44-8X8-NOPAD
U2: SPX1117M3-L-3-3/TR; SOT223
U$1: SCHMALZHAUSSCHMALZHAUS_SMALL; SCHMALZHAUS_SMALL
U$2: CE_MARK5MM; CE_5MM
U$3: ROSH_GARBAGE; ROHS_GARBAGE_5MM
U$4: CHIPKIT2MM; CHIPKIT_2MM
U$5: USBMICROB; USB-MICROB_FCI_PINS

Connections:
3.3V: C8.1, C9.1, C10.1, C13.1, ICSP.2, J1.3, J2.18, R1.1, R9.2, R10.1, R11.2, U1.10 (VUSB3V3), U1.17 (AVDD), U1.28 (VDD), U1.40 (VDD), U2.2 (OUT), U2.4 (OUT)
5V: C3.1, D1.1 (C), D2.1 (C), J1.1, U2.3 (IN)
!MCLR!: ICSP.1, J2.17, R10.2, RESET.P$3 (3), RESET.P$4 (4), U1.18 (!MCLR!)
D+/RB10: J2.15, U1.8 (PGED2/RPB10/D+/CTED11/RB10), U$5.D+
D-/RB11: J2.16, U1.9 (PGEC2/RPB11/D-/RB11), U$5.D-
GND: C1.1, C2.1, C3.2, C4.2, C5.2, C8.2, C9.2, C10.2, C13.2, C14.1, C15.1, ICSP.3, J1.2, J2.19, LED1.C, PRG.P$1 (1), PRG.P$2 (2), R8.2, RESET.P$1 (1), RESET.P$2 (2), U1.6 (VSS), U1.16 (AVSS), U1.29 (VSS), U1.39 (VSS), U2.1 (ADJ), U$5.GND, U$5.GND@1 (GND), U$5.GND@2 (GND), U$5.GND@3 (GND), U$5.GND@4 (GND), U$5.GND@5 (GND), U$5.GND@6 (GND), U$5.GND@7 (GND), U$5.GND@8 (GND)
unnamed: LED1.A, R11.1
unnamed: LED2.C, R8.1
RA0: J1.9, U1.19 (PGED3/VREF+/CVREF+/AN0/C3INC/RPA0/CTED1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)
RA1: J1.10, U1.20 (PGEC3/VREF-/CVREF-/AN1/RPA1/CTED2/PMD6/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)
RA2: C14.2, J1.18, Q1.P$1 (1), U1.30 (OSC1/CLKI/PRA2/RA2)
RA3: C15.2, J1.19, Q1.P$2 (2), U1.31 (OSC2/CLKO/RPA3/RA3)
RA4: C2.2, J2.2, Q2.1, U1.34 (SOSCO/RPA4/T1CK/CTED9/RA4)
RA7: J1.6, U1.13 (PGEC/TCK/CTED8/PMA7/RA7)
RA8: J1.20, PRG.P$3 (3), PRG.P$4 (4), R1.2, U1.32 (TDO/RPA8/PMA8/RA8)
RA9: J2.3, U1.35 (TDI/RPA9/PMA9/RA9)
RA10: J1.5, LED2.A, U1.12 (PGED/TMS/PMA10/RA10)
RB0: ICSP.4, J1.11, U1.21 (PGED1/AN2/C1IND/C2INB/C3IND/RPB0/PMD0/R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)
RB1: ICSP.5, J1.12, U1.22 (PGEC1/AN3/C1INC/C2INA/RPB1/CTED12/PMD1/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)
RB2: J1.13, U1.23 (AN4/C1INB/C2IND/RPB2/SDA2/CTED13/PMD2/C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)
RB3: J1.14, U1.24 (AN5/C1INA/C2INC/RTCC/RPB3/SCL2/PMWR/CNB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)
RB4: C1.2, J2.1, Q2.2, U1.33 (SOSCI/PRB4/RB4)
RB7: J2.8, U1.43 (RPB7/CTED3/PMD5/INT0/RB7)
RB8: J2.9, U1.44 (RPB8/SCL1/CTED10/PMD4/RB8)
RB9: J2.10, U1.1 (RPB9/SDA1/CTED4/PMD3/RB9)
RB13: J1.4, U1.11 (AN11/RPB13/CTPLS/PMRD/RB13)
RB14: J1.7, U1.14 (CVREF/AN10/C3INB/RPB14/VBUSON/SCK1/CTED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)
RB15: J1.8, U1.15 (AN9/C3INA/RPB15/SCK2/CTED6/PMCS1/RB15)
RC0: J1.15, U1.25 (AN6/RPC0/RC0)
RC1: J1.16, U1.26 (AN7/RPC1/RC1)
RC2: J1.17, U1.27 (AN8/RPC2/PMA2/RC2)
RC3: J2.4, U1.36 (AN12/RPC3/RC3)
RC4: J2.5, U1.37 (RPC4/PMA4/RC4)
RC5: J2.6, U1.38 (RPC5/PMA3/RC5)
RC6: J2.11, U1.2 (RPC6/PMA1/RC6)
RC7: J2.12, U1.3 (RPC7/PMA0/RC7)
RC8: J2.13, U1.4 (RPC8/PMA5/RC8)
RC9: J2.14, U1.5 (RPC9/CTED7/PMA6/RC9)
USBID/RB5: J2.7, R9.1, U1.41 (PRB5/USBID/RB5)
VBUS: D1.2 (A), U1.42 (VBUS), U$5.VBUS
VCAP: C4.1, C5.1, U1.7 (VCAP)
VIN: D2.2 (A), J2.20

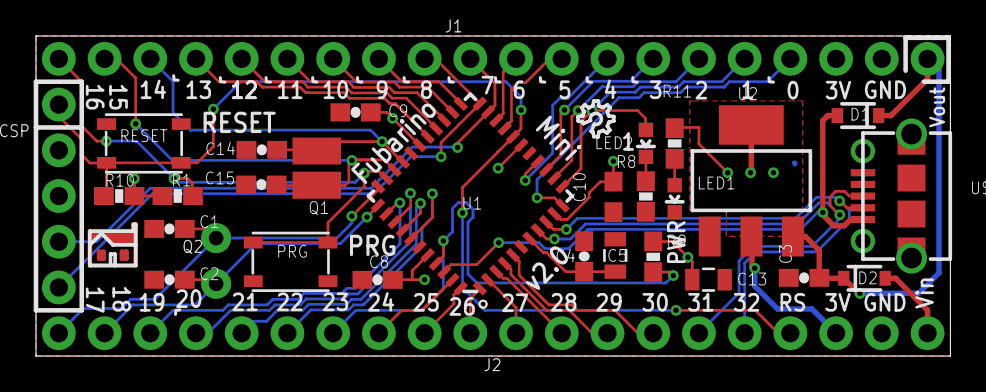
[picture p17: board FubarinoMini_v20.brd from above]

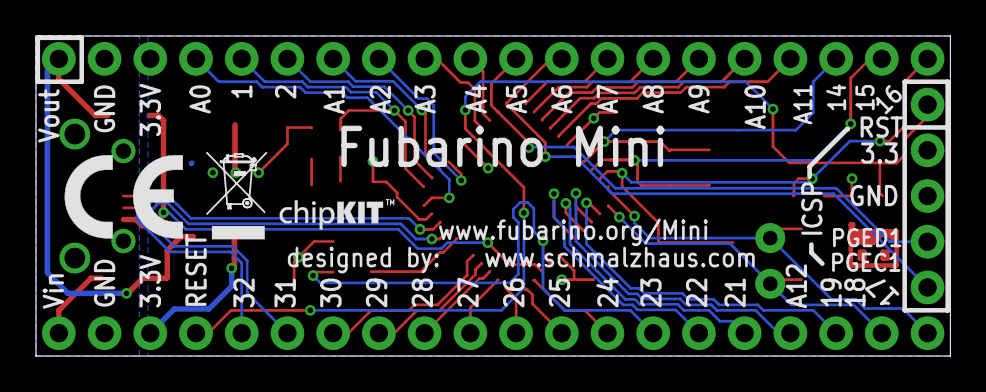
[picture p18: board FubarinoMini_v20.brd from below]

Board: 2 copper layers, 50.8 x 17.8 mm, 36 parts (3 on the bottom side), 42 nets.

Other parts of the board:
DRILEGEND: DRILEGEND

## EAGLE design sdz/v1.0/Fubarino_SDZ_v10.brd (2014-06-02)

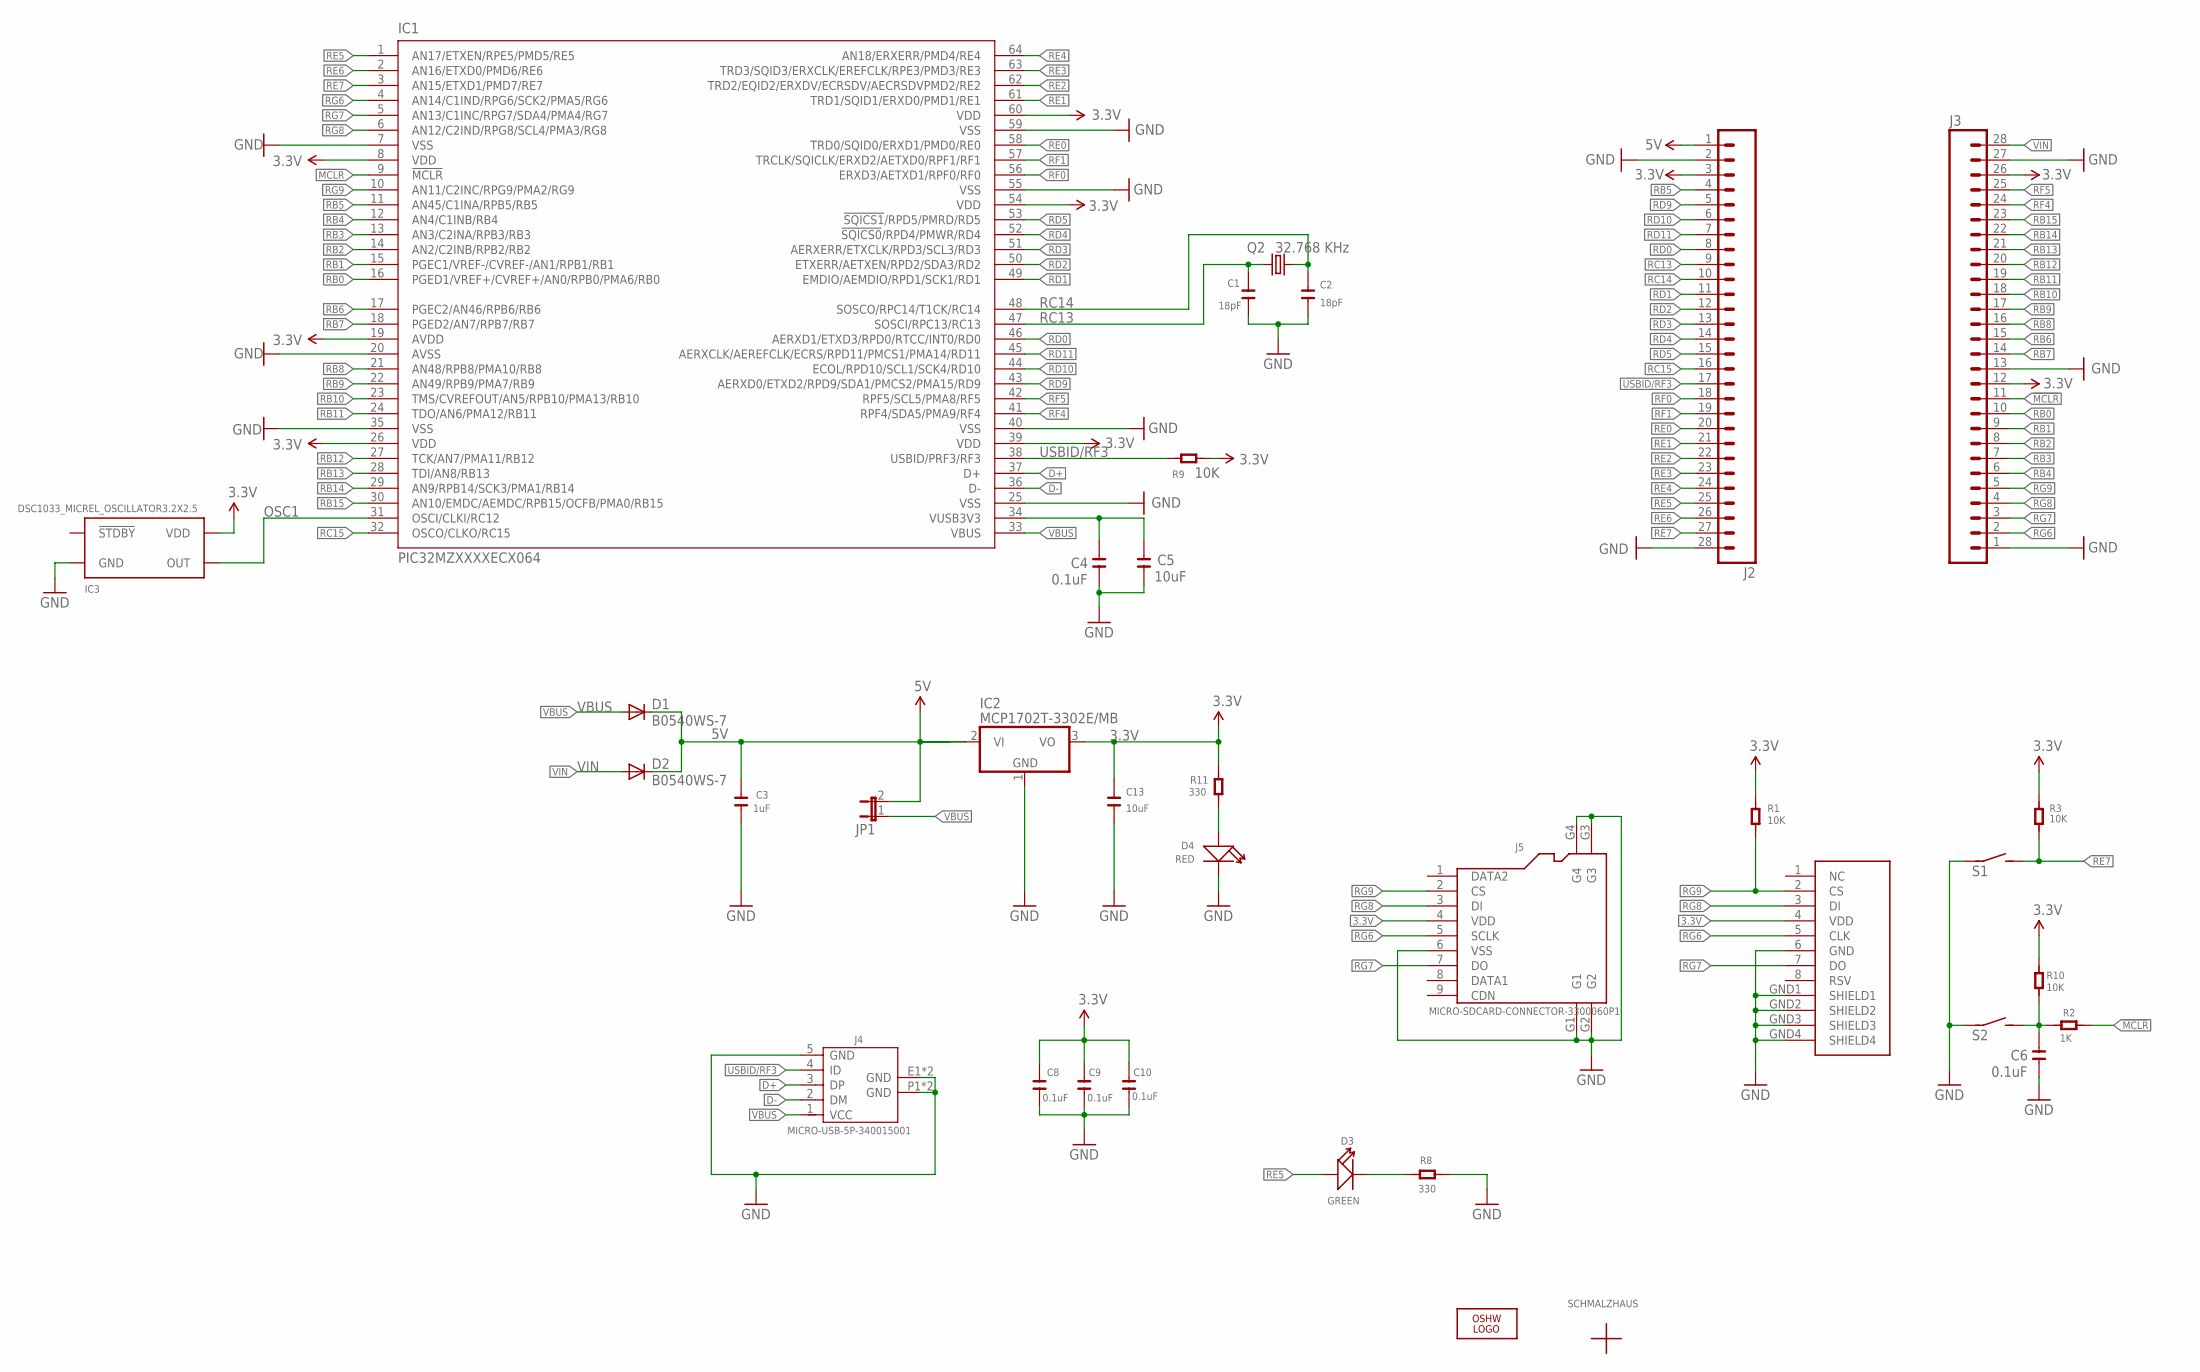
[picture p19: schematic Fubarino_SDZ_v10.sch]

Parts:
C1, C2: 18pF; C0603
C3: 1uF; C0603
C4, C6, C8, C9, C10: 0.1uF; C0603
C5, C13: 10uF; C0805
D1, D2: B0540WS-7; SOD-323
D3: GREEN; LED0603
D4: RED; LED0603
IC1: PIC32MZXXXXECX064; TQFP64-10X10
IC2: MCP1702T-3302E/MB; SOT89
IC3: DSC1033_MICREL_OSCILLATOR3.2X2.5; 3.2X2.5_SILABS_OSC_DSC1033
J1: MICRO_SD_CARD_SOCKET; SD-MMC_SOCKET-PP
J2: M28USEPIN1; 1X28
J3: M28NOPIN1; 1X28_NO_PIN_1
J4: MICRO-USB-5P-340015001; B-SMD-5P
J5: MICRO-SDCARD-CONNECTOR-3300060P1; 9P-SMD-W-RING
JP1: JUMPER-2SMD-NO; SJ_2S-NO
LOGO1: OSHW_LOGO_8MILX0070-NT; OSHW_8X70_NOTEXT
Q2: 32.768 KHz; TC26H
R1, R3, R9, R10: 10K; R0603
R2: 1K; R0603
R8, R11: 330; R0603
S1, S2: SWITCH; SWITCH_KMR_SMT_TACT
U$1: SCHMALZHAUSSCHMALZHAUS_SMALL; SCHMALZHAUS_SMALL
U$2: CE_MARK5MM; CE_5MM
U$3: ROHS_GARBAGE; ROHS_GARBAGE_5MM
U$4, U$5: CHIPKIT2MM; CHIPKIT_2MM

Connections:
3.3V: C8.1, C9.1, C10.1, C13.1, IC1.8 (VDD), IC1.19 (AVDD), IC1.26 (VDD), IC1.39 (VDD), IC1.54 (VDD), IC1.60 (VDD), IC2.3 (VO), IC3.P$4 (VDD), J1.4 (VDD), J2.3, J3.12, J3.26, J5.4 (VDD), R1.1, R3.1, R9.2, R10.1, R11.2
5V: C3.1, D1.1 (C), D2.1 (C), IC2.2 (VI), IC2.2@1 (VI1), J2.1, JP1.2
!MCLR!: IC1.9 (!MCLR!), J3.11, R2.2
$MCLR: C6.1, R2.1, R10.2, S2.P$3 (2), S2.P$4 (2)
D+: IC1.37 (D+), J4.3 (DP)
D-: IC1.36 (D-), J4.2 (DM)
GND: C1.1, C2.1, C3.2, C4.2, C5.2, C6.2, C8.2, C9.2, C10.2, C13.2, D4.-, IC1.7 (VSS), IC1.20 (AVSS), IC1.25 (VSS), IC1.35 (VSS), IC1.40 (VSS), IC1.55 (VSS), IC1.59 (VSS), IC2.1 (GND), IC3.P$2 (GND), J1.6 (GND), J1.GND1 (SHIELD1), J1.GND2 (SHIELD2), J1.GND3 (SHIELD3), J1.GND4 (SHIELD4), J2.2, J2.28, J3.1, J3.13, J3.27, J4.5 (GND), J4.E1 (GND), J4.E2 (GND), J4.P1 (GND), J4.P2 (GND), J5.6 (VSS), J5.G1, J5.G2, J5.G3, J5.G4, R8.2, S1.P$1 (1), S1.P$2 (1), S2.P$1 (1), S2.P$2 (1)
unnamed: D4.+, R11.1
unnamed: D3.-, R8.1
unnamed: C4.1, C5.1, IC1.34 (VUSB3V3)
OSC1: IC1.31 (OSCI/CLKI/RC12), IC3.P$3 (OUT)
RB0: IC1.16 (PGED1/VREF+/CVREF+/AN0/RPB0/PMA6/RB0), J3.10
RB1: IC1.15 (PGEC1/VREF-/CVREF-/AN1/RPB1/RB1), J3.9
RB2: IC1.14 (AN2/C2INB/RPB2/RB2), J3.8
RB3: IC1.13 (AN3/C2INA/RPB3/RB3), J3.7
RB4: IC1.12 (AN4/C1INB/RB4), J3.6
RB5: IC1.11 (AN45/C1INA/RPB5/RB5), J2.4
RB6: IC1.17 (PGEC2/AN46/RPB6/RB6), J3.15
RB7: IC1.18 (PGED2/AN7/RPB7/RB7), J3.14
RB8: IC1.21 (AN48/RPB8/PMA10/RB8), J3.16
RB9: IC1.22 (AN49/RPB9/PMA7/RB9), J3.17
RB10: IC1.23 (TMS/CVREFOUT/AN5/RPB10/PMA13/RB10), J3.18
RB11: IC1.24 (TDO/AN6/PMA12/RB11), J3.19
RB12: IC1.27 (TCK/AN7/PMA11/RB12), J3.20
RB13: IC1.28 (TDI/AN8/RB13), J3.21
RB14: IC1.29 (AN9/RPB14/SCK3/PMA1/RB14), J3.22
RB15: IC1.30 (AN10/EMDC/AEMDC/RPB15/OCFB/PMA0/RB15), J3.23
RC13: C1.2, IC1.47 (SOSCI/RPC13/RC13), J2.9, Q2.1
RC14: C2.2, IC1.48 (SOSCO/RPC14/T1CK/RC14), J2.10, Q2.2
RC15: IC1.32 (OSCO/CLKO/RC15), J2.16
RD0: IC1.46 (AERXD1/ETXD3/RPD0/RTCC/INT0/RD0), J2.8
RD1: IC1.49 (EMDIO/AEMDIO/RPD1/SCK1/RD1), J2.11
RD2: IC1.50 (ETXERR/AETXEN/RPD2/SDA3/RD2), J2.12
RD3: IC1.51 (AERXERR/ETXCLK/RPD3/SCL3/RD3), J2.13
RD4: IC1.52 (!SQICS0!/RPD4/PMWR/RD4), J2.14
RD5: IC1.53 (!SQICS1!/RPD5/PMRD/RD5), J2.15
RD9: IC1.43 (AERXD0/ETXD2/RPD9/SDA1/PMCS2/PMA15/RD9), J2.5
RD10: IC1.44 (ECOL/RPD10/SCL1/SCK4/RD10), J2.6
RD11: IC1.45 (AERXCLK/AEREFCLK/ECRS/RPD11/PMCS1/PMA14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), J2.7
RE0: IC1.58 (TRD0/SQID0/ERXD1/PMD0/RE0), J2.20
RE1: IC1.61 (TRD1/SQID1/ERXD0/PMD1/RE1), J2.21
RE2: IC1.62 (TRD2/EQID2/ERXDV/ECRSDV/AECRSDVPMD2/RE2), J2.22
RE3: IC1.63 (TRD3/SQID3/ERXCLK/EREFCLK/RPE3/PMD3/RE3), J2.23
RE4: IC1.64 (AN18/ERXERR/PMD4/RE4), J2.24
RE5: D3.+, IC1.1 (AN17/ETXEN/RPE5/PMD5/RE5), J2.25
RE6: IC1.2 (AN16/ETXD0/PMD6/RE6), J2.26
RE7: IC1.3 (AN15/ETXD1/PMD7/RE7), J2.27, R3.2, S1.P$3 (2), S1.P$4 (2)
RF0: IC1.56 (ERXD3/AETXD1/RPF0/RF0), J2.18
RF1: IC1.57 (TRCLK/SQICLK/ERXD2/AETXD0/RPF1/RF1), J2.19
RF4: IC1.41 (RPF4/SDA5/PMA9/RF4), J3.24
RF5: IC1.42 (RPF5/SCL5/PMA8/RF5), J3.25
RG6: IC1.4 (AN14/C1IND/RPG6/SCK2/PMA5/RG6), J1.5 (CLK), J3.2, J5.5 (SCLK)
RG7: IC1.5 (AN13/C1INC/RPG7/SDA4/PMA4/RG7), J1.7 (DO), J3.3, J5.7 (DO)
RG8: IC1.6 (AN12/C2IND/RPG8/SCL4/PMA3/RG8), J1.3 (DI), J3.4, J5.3 (DI)
RG9: IC1.10 (AN11/C2INC/RPG9/PMA2/RG9), J1.2 (CS), J3.5, J5.2 (CS), R1.2
USBID/RF3: IC1.38 (USBID/PRF3/RF3), J2.17, J4.4 (ID), R9.1
VBUS: D1.2 (A), IC1.33 (VBUS), J4.1 (VCC), JP1.1
VIN: D2.2 (A), J3.28

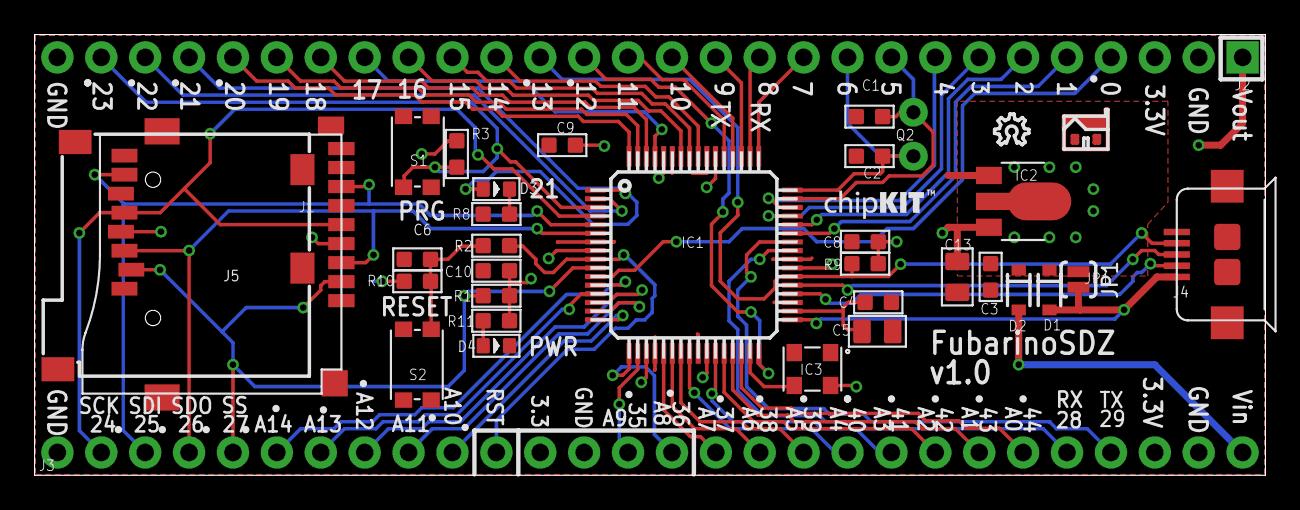
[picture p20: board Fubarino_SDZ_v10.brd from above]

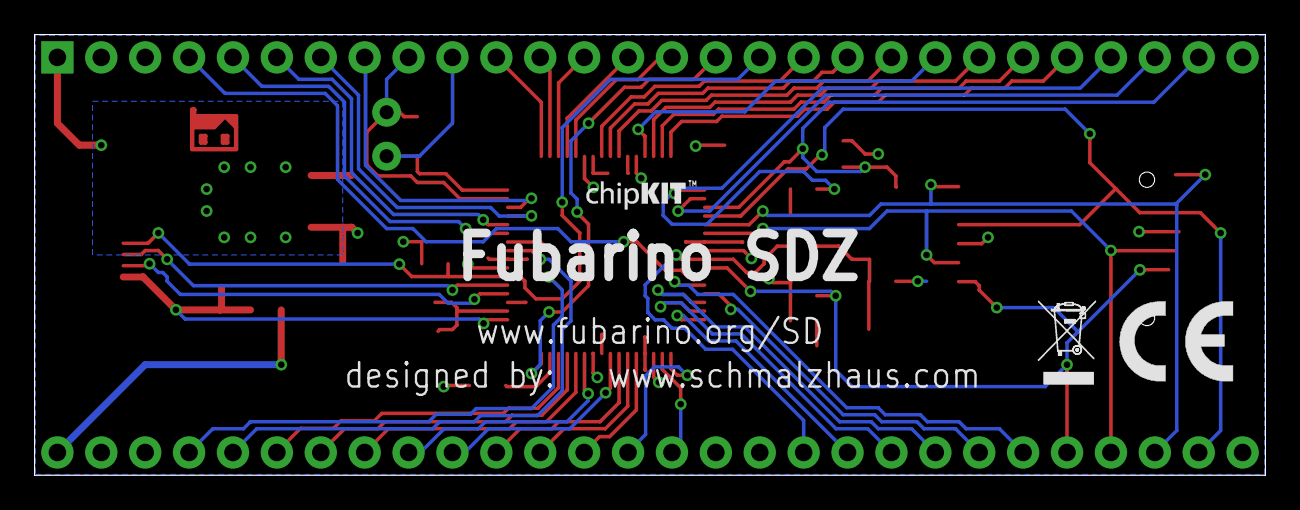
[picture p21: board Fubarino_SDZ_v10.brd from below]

Board: 2 copper layers, 71.2 x 25.5 mm, 40 parts (3 on the bottom side), 58 nets.

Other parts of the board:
DRILEGEND: DRILEGEND

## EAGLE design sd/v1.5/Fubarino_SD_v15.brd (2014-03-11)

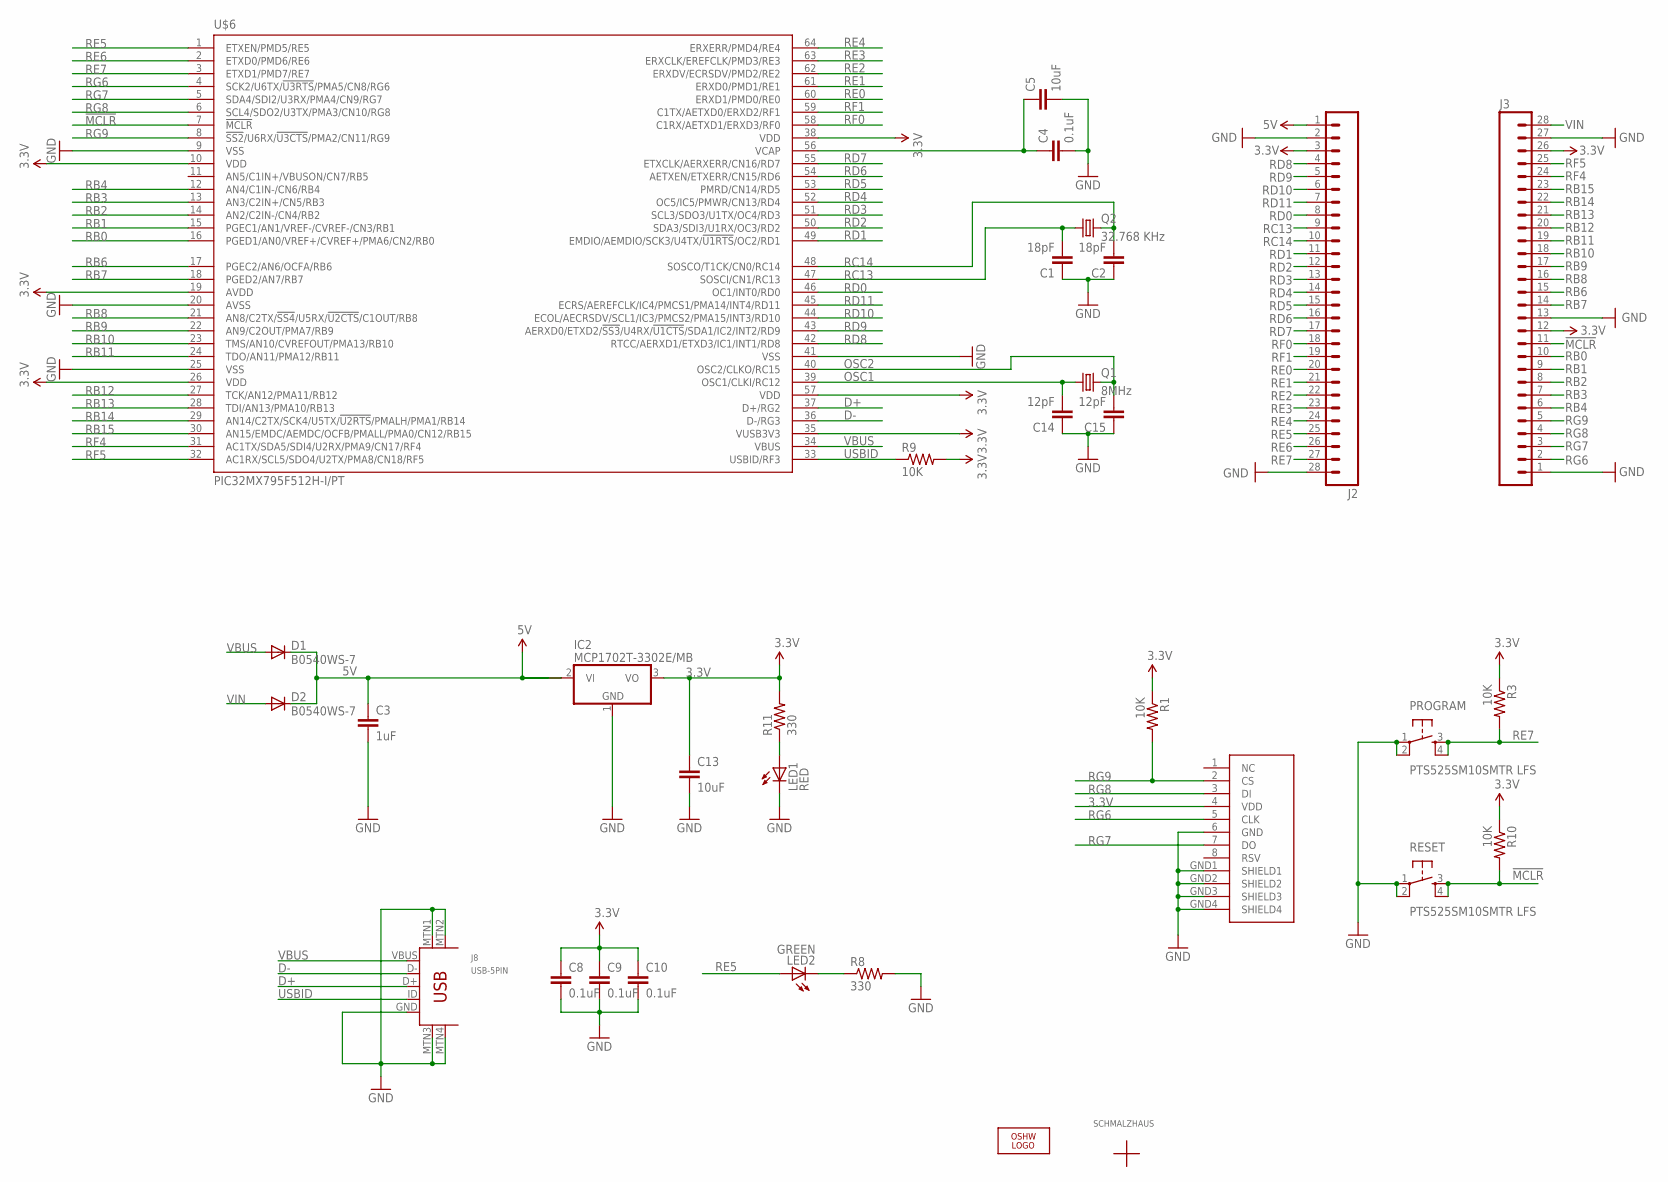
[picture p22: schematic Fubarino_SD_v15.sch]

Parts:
C1, C2: 18pF; 0603-CAP
C3: 1uF; 0603-CAP
C4, C8, C9: 0.1uF; 0603-CAP
C5, C13: 10uF; 0805
C10: 0.1uF; 0603
C14, C15: 12pF; 0603-CAP
D1, D2: B0540WS-7; SOD-323
IC2: MCP1702T-3302E/MB; SOT89
J1: MICRO_SD_CARD_SOCKET; SD-MMC_SOCKET-PP
J2: M28USEPIN1; 1X28
J3: M28NOPIN1; 1X28_NO_PIN_1
J8: USB-5PIN; USB-MINIB-5PIN-HIROSE-UX60-MB-5ST
LED1: RED; LED-0603
LED2: GREEN; LED-0603
LOGO1: OSHW_LOGO_8MILX0070-NT; OSHW_8X70_NOTEXT
PROGRAM: PTS525SM10SMTR LFS; TACTILE_SWITCH_SMD
Q1: 8MHz; NX5032_5MM_3.2MM_CRYSTAL
Q2: 32.768 KHz; TC26H
R1, R3, R9, R10: 10K; 0603-RES
R8, R11: 330; 0603-RES
RESET: PTS525SM10SMTR LFS; TACTILE_SWITCH_SMD
U$1: SCHMALZHAUSSCHMALZHAUS_SMALL; SCHMALZHAUS_SMALL
U$2: CE_MARK5MM; CE_5MM
U$3: ROHS_GARBAGE; ROHS_GARBAGE_5MM
U$4, U$5: CHIPKIT2MM; CHIPKIT_2MM
U$6: PIC32MX795F512H-I/PT; TQFP64-10X10

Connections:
3.3V: C8.1, C9.1, C10.1, C13.1, IC2.3 (VO), J1.4 (VDD), J2.3, J3.12, J3.26, R1.1, R3.1, R9.2, R10.1, R11.2, U$6.10 (VDD), U$6.19 (AVDD), U$6.26 (VDD), U$6.35 (VUSB3V3), U$6.38 (VDD), U$6.57 (VDD)
5V: C3.1, D1.1 (C), D2.1 (C), IC2.2 (VI), IC2.2@1 (VI1), J2.1
!MCLR!: J3.11, R10.2, RESET.3, RESET.4, U$6.7 (!MCLR)
D+: J8.D+, U$6.37 (D+/RG2)
D-: J8.D-, U$6.36 (D-/RG3)
GND: C1.1, C2.1, C3.2, C4.2, C5.2, C8.2, C9.2, C10.2, C13.2, C14.1, C15.1, IC2.1 (GND), J1.6 (GND), J1.GND1 (SHIELD1), J1.GND2 (SHIELD2), J1.GND3 (SHIELD3), J1.GND4 (SHIELD4), J2.2, J2.28, J3.1, J3.13, J3.27, J8.GND, J8.MTN1, J8.MTN2, J8.MTN3, J8.MTN4, LED1.C, PROGRAM.1, PROGRAM.2, R8.2, RESET.1, RESET.2, U$6.9 (VSS), U$6.20 (AVSS), U$6.25 (VSS), U$6.41 (VSS)
unnamed: LED1.A, R11.1
unnamed: LED2.C, R8.1
unnamed: C4.1, C5.1, U$6.56 (VCAP)
OSC1: C14.2, Q1.1, U$6.39 (OSC1/CLKI/RC12)
OSC2: C15.2, Q1.2, U$6.40 (OSC2/CLKO/RC15)
RB0: J3.10, U$6.16 (PGED1/AN0/VREF+/CVREF+/PMA6/CN2/RB0)
RB1: J3.9, U$6.15 (PGEC1/AN1/VREF-/CVREF-/CN3/RB1)
RB2: J3.8, U$6.14 (AN2/C2IN-/CN4/RB2)
RB3: J3.7, U$6.13 (AN3/C2IN+/CN5/RB3)
RB4: J3.6, U$6.12 (AN4/C1IN-/CN6/RB4)
RB6: J3.15, U$6.17 (PGEC2/AN6/OCFA/RB6)
RB7: J3.14, U$6.18 (PGED2/AN7/RB7)
RB8: J3.16, U$6.21 (AN8/C2TX/!SS4!/U5RX/!U2CTS!/C1OUT/RB8)
RB9: J3.17, U$6.22 (AN9/C2OUT/PMA7/RB9)
RB10: J3.18, U$6.23 (TMS/AN10/CVREFOUT/PMA13/RB10)
RB11: J3.19, U$6.24 (TDO/AN11/PMA12/RB11)
RB12: J3.20, U$6.27 (TCK/AN12/PMA11/RB12)
RB13: J3.21, U$6.28 (TDI/AN13/PMA10/RB13)
RB14: J3.22, U$6.29 (AN14/C2TX/SCK4/U5TX/!U2RTS!/PMALH/PMA1/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)
RB15: J3.23, U$6.30 (AN15/EMDC/AEMDC/OCFB/PMALL/PMA0/CN12/RB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)
RC13: C1.2, J2.9, Q2.1, U$6.47 (SOSCI/CN1/RC13)
RC14: C2.2, J2.10, Q2.2, U$6.48 (SOSCO/T1CK/CN0/RC14)
RD0: J2.8, U$6.46 (OC1/INT0/RD0)
RD1: J2.11, U$6.49 (EMDIO/AEMDIO/SCK3/U4TX/!U1RTS!/OC2/RD1)
RD2: J2.12, U$6.50 (SDA3/SDI3/U1RX/OC3/RD2)
RD3: J2.13, U$6.51 (SCL3/SDO3/U1TX/OC4/RD3)
RD4: J2.14, U$6.52 (OC5/IC5/PMWR/CN13/RD4)
RD5: J2.15, U$6.53 (PMRD/CN14/RD5)
RD6: J2.16, U$6.54 (AETXEN/ETXERR/CN15/RD6)
RD7: J2.17, U$6.55 (ETXCLK/AERXERR/CN16/RD7)
RD8: J2.4, U$6.42 (RTCC/AERXD1/ETXD3/IC1/INT1/RD8)
RD9: J2.5, U$6.43 (AERXD0/ETXD2/!SS3!/U4RX/!U1CTS!/SDA1/IC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)
RD10: J2.6, U$6.44 (ECOL/AECRSDV/SCL1/IC3/PMCS2/PMA15/INT3/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)
RD11: J2.7, U$6.45 (ECRS/AEREFCLK/IC4/PMCS1/PMA14/INT4/RD11)
RE0: J2.20, U$6.60 (ERXD1/PMD0/RE0)
RE1: J2.21, U$6.61 (ERXD0/PMD1/RE1)
RE2: J2.22, U$6.62 (ERXDV/ECRSDV/PMD2/RE2)
RE3: J2.23, U$6.63 (ERXCLK/EREFCLK/PMD3/RE3)
RE4: J2.24, U$6.64 (ERXERR/PMD4/RE4)
RE5: J2.25, LED2.A, U$6.1 (ETXEN/PMD5/RE5)
RE6: J2.26, U$6.2 (ETXD0/PMD6/RE6)
RE7: J2.27, PROGRAM.3, PROGRAM.4, R3.2, U$6.3 (ETXD1/PMD7/RE7)
RF0: J2.18, U$6.58 (C1RX/AETXD1/ERXD3/RF0)
RF1: J2.19, U$6.59 (C1TX/AETXD0/ERXD2/RF1)
RF4: J3.24, U$6.31 (AC1TX/SDA5/SDI4/U2RX/PMA9/CN17/RF4)
RF5: J3.25, U$6.32 (AC1RX/SCL5/SDO4/U2TX/PMA8/CN18/RF5)
RG6: J1.5 (CLK), J3.2, U$6.4 (SCK2/U6TX/!U3RTS!/PMA5/CN8/RG6)
RG7: J1.7 (DO), J3.3, U$6.5 (SDA4/SDI2/U3RX/PMA4/CN9/RG7)
RG8: J1.3 (DI), J3.4, U$6.6 (SCL4/SDO2/U3TX/PMA3/CN10/RG8)
RG9: J1.2 (CS), J3.5, R1.2, U$6.8 (!SS2!/U6RX/!U3CTS!/PMA2/CN11/RG9)
USBID: J8.ID, R9.1, U$6.33 (USBID/RF3)
VBUS: D1.2 (A), J8.VBUS, U$6.34 (VBUS)
VIN: D2.2 (A), J3.28

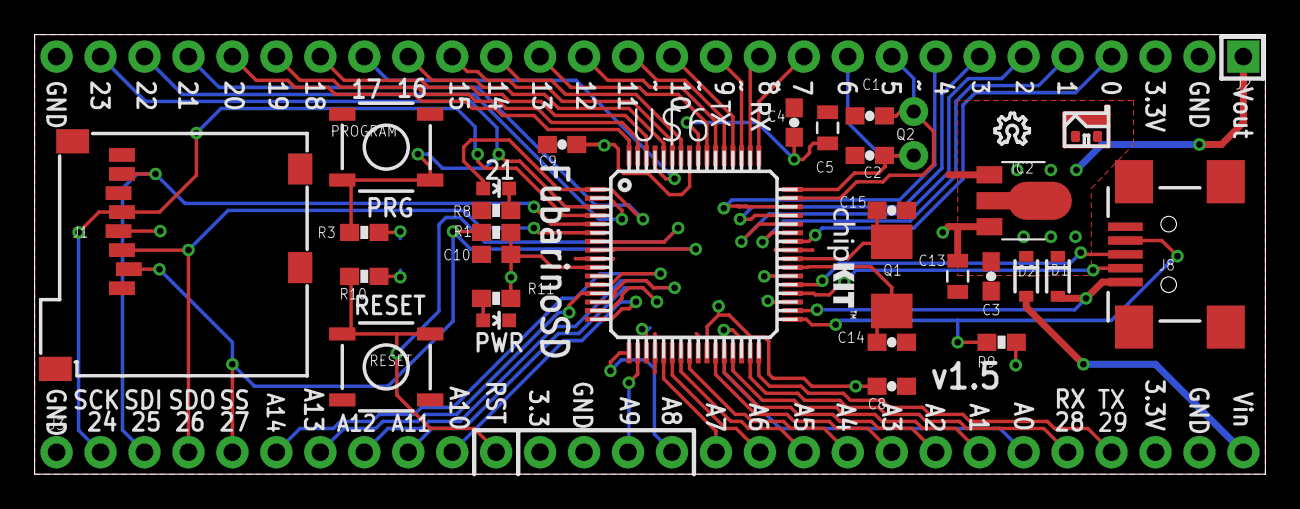
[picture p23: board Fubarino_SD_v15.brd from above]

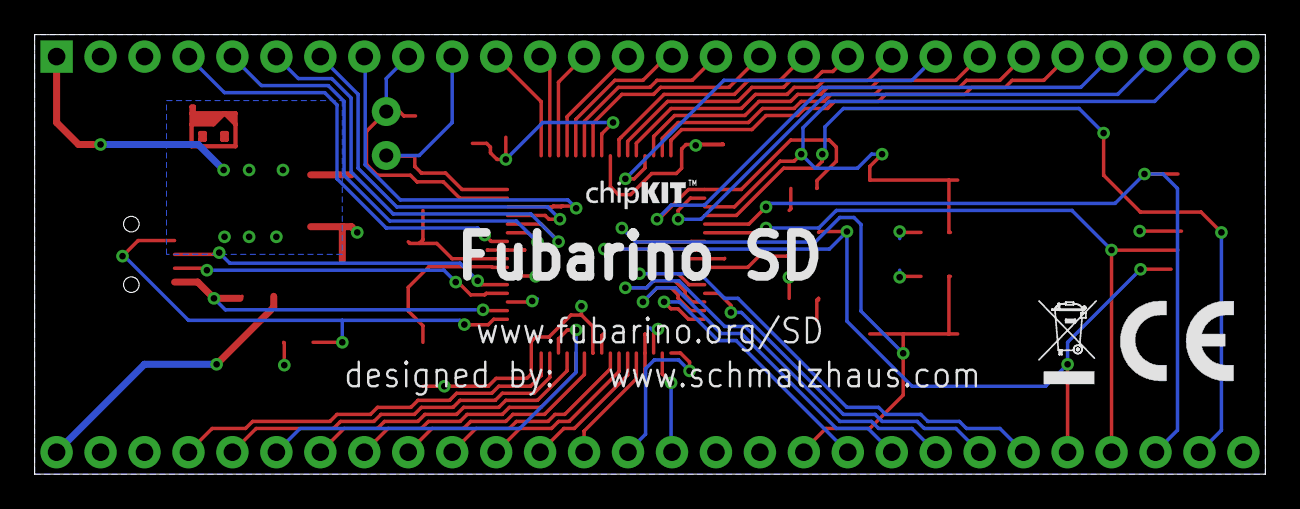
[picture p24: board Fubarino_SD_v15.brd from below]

Board: 2 copper layers, 71.1 x 25.4 mm, 38 parts (3 on the bottom side), 59 nets.

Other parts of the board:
DRILEGEND: DRILEGEND

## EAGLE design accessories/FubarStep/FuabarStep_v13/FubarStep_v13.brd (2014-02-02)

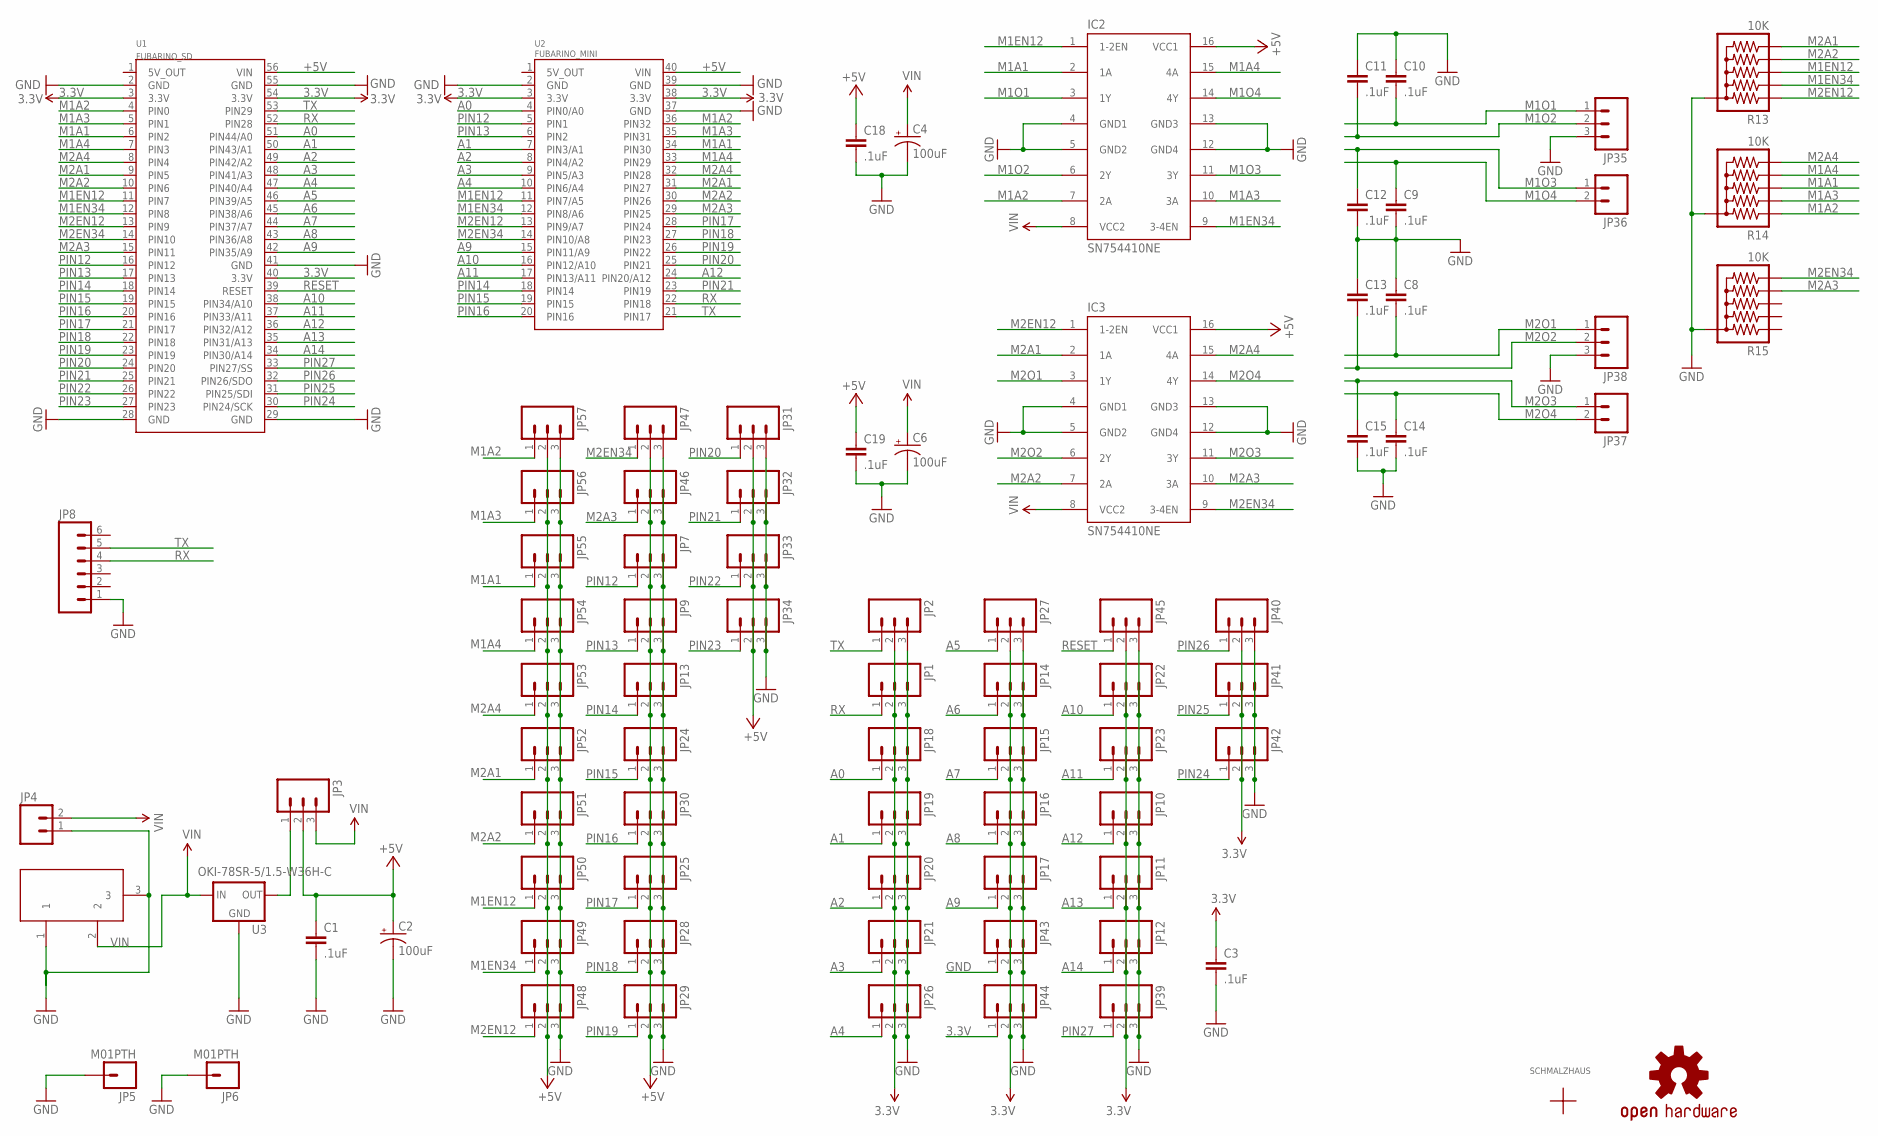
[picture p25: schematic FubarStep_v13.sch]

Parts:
C1, C3, C8, C9, C10, C11, C12, C13, C14, C15, C18, C19: .1uF; CAP-PTH-SMALL
C2, C4, C6: 100uF; CPOL-RADIAL-100UF
IC2, IC3: SN754410NE; DIL16
JP1, JP2, JP3, JP7, JP9, JP10, JP11, JP12, JP13, JP14, JP15, JP16, JP17, JP18, JP19, JP20, JP21, JP22, JP23, JP24, JP25, JP26, JP27, JP28, JP29, JP30, JP31, JP32, JP33, JP34, JP39, JP40, JP41, JP42, JP43, JP44, JP45, JP46, JP47, JP48, JP49, JP50, JP51, JP52, JP53, JP54, JP55, JP56, JP57: M03PTH; 1X03
JP4, JP36, JP37: M023.5MM; SCREWTERMINAL-3.5MM-2
JP5, JP6: M01PTH; 1X01
JP8: M06LOCK; 1X06_LOCK
JP35, JP38: M03SCREW; SCREWTERMINAL-3.5MM-3
LOGO1: OSHW-LOGOM; OSHW-LOGO-M
R13, R14, R15: 10K; RPACK-SIP-PTH-5
U1: FUBARINO_SD
U2: FUBARINO_MINI
U3: OKI-78SR-5/1.5-W36H-C; TO220-IGO
U$1: SCHMALZHAUSSCHMALZHAUS_SMALL; SCHMALZHAUS_SMALL
X1: DC21MMX; DC-21MM

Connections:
3.3V: C3.1, JP1.2, JP2.2, JP10.2, JP11.2, JP12.2, JP14.2, JP15.2, JP16.2, JP17.2, JP18.2, JP19.2, JP20.2, JP21.2, JP22.2, JP23.2, JP26.2, JP27.2, JP39.2, JP40.2, JP41.2, JP42.2, JP43.2, JP44.1, JP44.2, JP45.2, U1.3 (3.3V), U1.40 (3.3V), U1.54 (3.3V), U2.3 (3.3V), U2.38 (3.3V)
+5V: C1.1, C2.1 (+), C18.1, C19.1, IC2.16 (VCC1), IC3.16 (VCC1), JP3.2, JP7.2, JP9.2, JP13.2, JP24.2, JP25.2, JP28.2, JP29.2, JP30.2, JP31.2, JP32.2, JP33.2, JP34.2, JP46.2, JP47.2, JP48.2, JP49.2, JP50.2, JP51.2, JP52.2, JP53.2, JP54.2, JP55.2, JP56.2, JP57.2, U1.56 (VIN), U2.40 (VIN)
A0: JP18.1, U1.51 (PIN44/A0), U2.4 (PIN0/A0)
A1: JP19.1, U1.50 (PIN43/A1), U2.7 (PIN3/A1)
A2: JP20.1, U1.49 (PIN42/A2), U2.8 (PIN4/A2)
A3: JP21.1, U1.48 (PIN41/A3), U2.9 (PIN5/A3)
A4: JP26.1, U1.47 (PIN40/A4), U2.10 (PIN6/A4)
A5: JP27.1, U1.46 (PIN39/A5)
A6: JP14.1, U1.45 (PIN38/A6)
A7: JP15.1, U1.44 (PIN37/A7)
A8: JP16.1, U1.43 (PIN36/A8)
A9: JP17.1, U1.42 (PIN35/A9), U2.15 (PIN11/A9)
A10: JP22.1, U1.38 (PIN34/A10), U2.16 (PIN12/A10)
A11: JP23.1, U1.37 (PIN33/A11), U2.17 (PIN13/A11)
A12: JP10.1, U1.36 (PIN32/A12), U2.24 (PIN20/A12)
A13: JP11.1, U1.35 (PIN31/A13)
A14: JP12.1, U1.34 (PIN30/A14)
GND: C1.2, C2.2 (-), C3.2, C4.2 (-), C6.2 (-), C8.1, C9.2, C10.1, C11.1, C12.2, C13.1, C14.2, C15.2, C18.2, C19.2, IC2.4 (GND1), IC2.5 (GND2), IC2.12 (GND4), IC2.13 (GND3), IC3.4 (GND1), IC3.5 (GND2), IC3.12 (GND4), IC3.13 (GND3), JP1.3, JP2.3, JP4.1, JP5.1, JP6.1, JP7.3, JP8.1, JP9.3, JP10.3, JP11.3, JP12.3, JP13.3, JP14.3, JP15.3, JP16.3, JP17.3, JP18.3, JP19.3, JP20.3, JP21.3, JP22.3, JP23.3, JP24.3, JP25.3, JP26.3, JP27.3, JP28.3, JP29.3, JP30.3, JP31.3, JP32.3, JP33.3, JP34.3, JP35.3, JP38.3, JP39.3, JP40.3, JP41.3, JP42.3, JP43.1, JP43.3, JP44.3, JP45.3, JP46.3, JP47.3, JP48.3, JP49.3, JP50.3, JP51.3, JP52.3, JP53.3, JP54.3, JP55.3, JP56.3, JP57.3, R13.P$1 (1), R14.P$1 (1), R15.P$1 (1), U1.2 (GND), U1.28 (GND), U1.29 (GND), U1.41 (GND), U1.55 (GND), U2.2 (GND), U2.37 (GND), U2.39 (GND), U3.GND, X1.1, X1.3
M1A1: IC2.2 (1A), JP55.1, R14.P$4 (4), U1.6 (PIN2), U2.34 (PIN30)
M1A2: IC2.7 (2A), JP57.1, R14.P$2 (2), U1.4 (PIN0), U2.36 (PIN32)
M1A3: IC2.10 (3A), JP56.1, R14.P$3 (3), U1.5 (PIN1), U2.35 (PIN31)
M1A4: IC2.15 (4A), JP54.1, R14.P$5 (5), U1.7 (PIN3), U2.33 (PIN29)
M1EN12: IC2.1 (1-2EN), JP50.1, R13.P$4 (4), U1.11 (PIN7), U2.11 (PIN7/A5)
M1EN34: IC2.9 (3-4EN), JP49.1, R13.P$3 (3), U1.12 (PIN8), U2.12 (PIN8/A6)
M1O1: C10.2, IC2.3 (1Y), JP35.1
M1O2: C11.2, IC2.6 (2Y), JP35.2
M1O3: C12.1, IC2.11 (3Y), JP36.1
M1O4: C9.1, IC2.14 (4Y), JP36.2
M2A1: IC3.2 (1A), JP52.1, R13.P$6 (6), U1.9 (PIN5), U2.31 (PIN27)
M2A2: IC3.7 (2A), JP51.1, R13.P$5 (5), U1.10 (PIN6), U2.30 (PIN26)
M2A3: IC3.10 (3A), JP46.1, R15.P$5 (5), U1.15 (PIN11), U2.29 (PIN25)
M2A4: IC3.15 (4A), JP53.1, R14.P$6 (6), U1.8 (PIN4), U2.32 (PIN28)
M2EN12: IC3.1 (1-2EN), JP48.1, R13.P$2 (2), U1.13 (PIN9), U2.13 (PIN9/A7)
M2EN34: IC3.9 (3-4EN), JP47.1, R15.P$6 (6), U1.14 (PIN10), U2.14 (PIN10/A8)
M2O1: C8.2, IC3.3 (1Y), JP38.1
M2O2: C13.2, IC3.6 (2Y), JP38.2
M2O3: C15.1, IC3.11 (3Y), JP37.1
M2O4: C14.1, IC3.14 (4Y), JP37.2
unnamed: JP3.1, U3.OUT
PIN12: JP7.1, U1.16 (PIN12), U2.5 (PIN1)
PIN13: JP9.1, U1.17 (PIN13), U2.6 (PIN2)
PIN14: JP13.1, U1.18 (PIN14), U2.18 (PIN14)
PIN15: JP24.1, U1.19 (PIN15), U2.19 (PIN15)
PIN16: JP30.1, U1.20 (PIN16), U2.20 (PIN16)
PIN17: JP25.1, U1.21 (PIN17), U2.28 (PIN24)
PIN18: JP28.1, U1.22 (PIN18), U2.27 (PIN23)
PIN19: JP29.1, U1.23 (PIN19), U2.26 (PIN22)
PIN20: JP31.1, U1.24 (PIN20), U2.25 (PIN21)
PIN21: JP32.1, U1.25 (PIN21), U2.23 (PIN19)
PIN22: JP33.1, U1.26 (PIN22)
PIN23: JP34.1, U1.27 (PIN23)
PIN24: JP42.1, U1.30 (PIN24/SCK)
PIN25: JP41.1, U1.31 (PIN25/SDI)
PIN26: JP40.1, U1.32 (PIN26/SDO)
PIN27: JP39.1, U1.33 (PIN27/SS)
RESET: JP45.1, U1.39 (RESET)
RX: JP1.1, JP8.4, U1.52 (PIN28), U2.22 (PIN18)
TX: JP2.1, JP8.5, U1.53 (PIN29), U2.21 (PIN17)
VIN: C4.1 (+), C6.1 (+), IC2.8 (VCC2), IC3.8 (VCC2), JP3.3, JP4.2, U3.IN, X1.2

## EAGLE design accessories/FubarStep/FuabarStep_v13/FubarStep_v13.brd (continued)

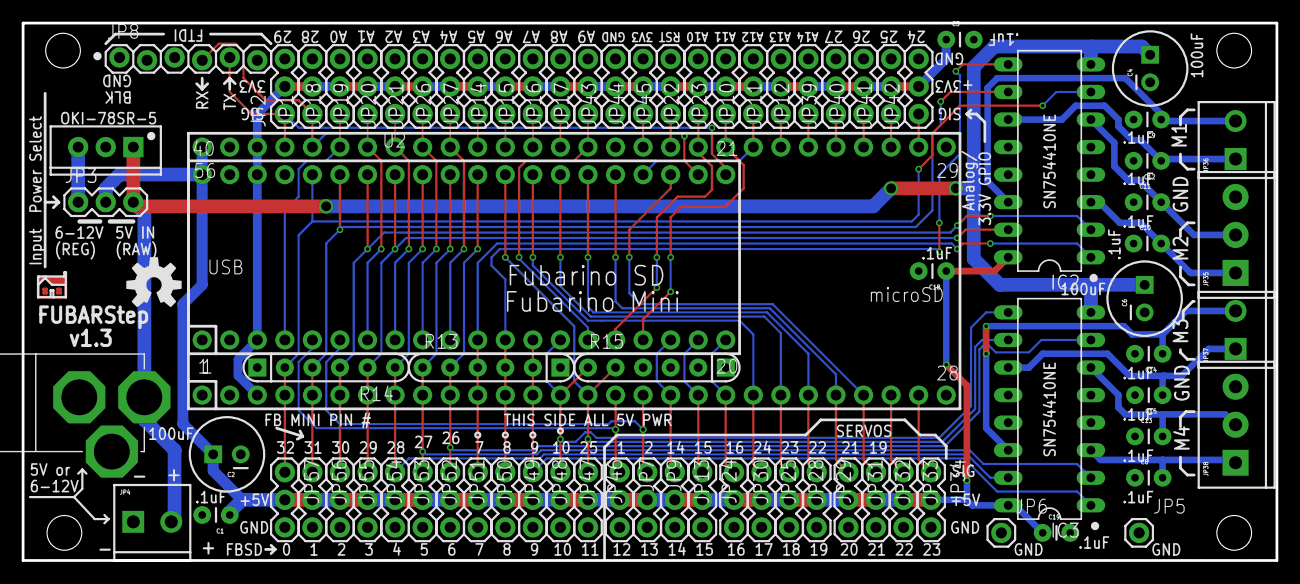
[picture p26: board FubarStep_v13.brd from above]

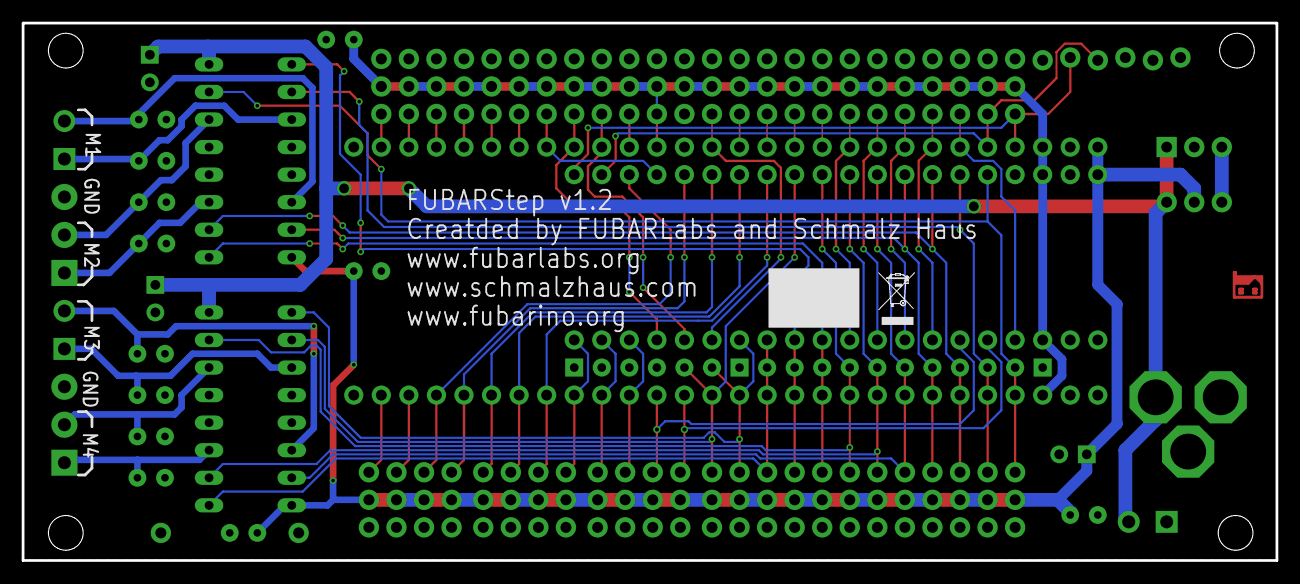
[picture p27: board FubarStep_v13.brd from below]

Board: 2 copper layers, 115.6 x 49.5 mm, 85 parts (2 on the bottom side), 59 nets.

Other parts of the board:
U$2: ROHS_GARBAGE_5MM
U$3: CE_5MM

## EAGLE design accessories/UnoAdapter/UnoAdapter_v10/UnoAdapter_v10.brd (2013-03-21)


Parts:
AD: PINHD-1X6; 1X06
C1: .1uF; CAP-PTH-SMALL
C2: 100uF; CPOL-RADIAL-100UF-25V
D1, D2, D3, D4, D5, D6, D7: DIODE1N4148; DIODE-1N4148
IC1: 7805; 78XXL
IOL: PINHD-1X8; 1X08
JP1: PINHD-1X10; 1X10
JP2: M05PTH; 1X05
JP3: M02PTH; 1X02
POWER: PINHD-1X8; 1X08
R1, R2, R3, R4, R5, R6, R7: RESISTORAXIAL-0.3; AXIAL-0.3
S1, S2: SWITCH-MOMENTARY-2SIDE_EZ; TACTILE-PTH-SIDEEZ
U$1: FUBARINO_SD
U$2: FUBARINO_MINI
X1: DC21MMX; DC-21MM

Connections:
$12: AD.6, R1.P$2 (2)
$13: AD.5, R2.P$2 (2)
$14: AD.4, R3.P$2 (2)
$15: AD.3, R4.P$2 (2)
$16: AD.2, R5.P$2 (2)
$17: AD.1, R6.P$2 (2)
$123: JP1.6, R7.P$2 (2)
+3V3: D1.C, D2.C, D3.C, D4.C, D5.C, D6.C, D7.C, JP2.2, POWER.2, POWER.4, U$1.3 (3.3V), U$1.40 (3.3V), U$1.54 (3.3V), U$2.3 (3.3V), U$2.38 (3.3V)
+5V: C1.1, IC1.OUT, POWER.5, U$1.1 (5V_OUT), U$2.1 (5V_OUT)
AD0: D6.A, R6.P$1 (1), U$1.51 (PIN44/A0), U$2.4 (PIN0/A0)
AD1: D5.A, R5.P$1 (1), U$1.50 (PIN43/A1), U$2.7 (PIN3/A1)
AD2: D4.A, R4.P$1 (1), U$1.49 (PIN42/A2), U$2.9 (PIN5/A3)
AD3: D3.A, R3.P$1 (1), U$1.48 (PIN41/A3), U$2.10 (PIN6/A4)
AD4: D2.A, R2.P$1 (1), U$1.47 (PIN40/A4), U$2.13 (PIN9/A7)
AD4/SDA: JP1.9, U$1.52 (PIN28), U$2.30 (PIN26)
AD5: D1.A, R1.P$1 (1), U$1.46 (PIN39/A5), U$2.14 (PIN10/A8)
AD5/SCL: JP1.10, U$1.53 (PIN29), U$2.29 (PIN25)
AREF: JP1.8
GND: C1.2, C2.2 (-), IC1.GND, JP1.7, JP2.3, POWER.6, POWER.7, S1.1, S2.1, U$1.2 (GND), U$1.28 (GND), U$1.29 (GND), U$1.41 (GND), U$1.55 (GND), U$2.2 (GND), U$2.39 (GND), X1.1, X1.3
IO0: IOL.1, U$1.16 (PIN12), U$2.21 (PIN17)
IO1: IOL.2, U$1.17 (PIN13), U$2.22 (PIN18)
IO2: IOL.3, U$1.8 (PIN4), U$2.23 (PIN19)
IO3: IOL.4, U$2.25 (PIN21)
IO4: IOL.5, U$1.4 (PIN0), U$2.26 (PIN22)
IO5: IOL.6, U$1.14 (PIN10), U$2.27 (PIN23)
IO6: IOL.7, U$1.10 (PIN6), U$2.28 (PIN24)
IO7: IOL.8, U$1.11 (PIN7), U$2.31 (PIN27)
IO8: JP1.1, U$1.12 (PIN8), U$2.32 (PIN28)
IO9: JP1.2, U$1.13 (PIN9), U$2.34 (PIN30)
MISO: JP1.5, U$1.31 (PIN25/SDI), U$2.18 (PIN14)
MOSI: JP1.4, U$1.32 (PIN26/SDO), U$2.33 (PIN29)
M_RB0: JP2.4, U$2.11 (PIN7/A5)
M_RB1: JP2.5, U$2.12 (PIN8/A6)
M_RESET: JP3.2, U$2.37 (GND)
PRG: S2.2, U$1.27 (PIN23), U$2.20 (PIN16)
RESET: JP2.1, JP3.1, POWER.3, S1.2, U$1.39 (RESET)
SCK: D7.A, R7.P$1 (1), U$1.30 (PIN24/SCK), U$2.8 (PIN4/A2)
SS: JP1.3, U$1.26 (PIN22), U$2.19 (PIN15)
SS_SD: U$1.33 (PIN27/SS)
VIN: C2.1 (+), IC1.IN, POWER.8, X1.2

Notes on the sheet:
SCL
SDA


Board: 2 copper layers, 71.1 x 52.7 mm, 28 parts (0 on the bottom side), 38 nets.

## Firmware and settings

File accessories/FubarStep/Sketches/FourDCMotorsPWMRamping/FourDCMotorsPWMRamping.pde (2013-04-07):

#include <SoftPWMServo.h> 

int pos = 1000;         // variable to store the servo position, in microseconds

// For Fubarino SD
#if defined(_BOARD_FUBARINO_SD_)
#define M1EN12  7
#define M1EN34  8

#define M1A1    2
#define M1A2    0
#define M1A3    1
#define M1A4    3

#define M2EN12  9
#define M2EN34  10

#define M2A1    5
#define M2A2    6
#define M2A3    11
#define M2A4    4
// SD has all 12 servos hooked up
#define SRV1    12
#define SRV2    13
#define SRV3    14
#define SRV4    15
#define SRV5    16
#define SRV6    17
#define SRV7    18
#define SRV8    19
#define SRV9    20
#define SRV10   21
#define SRV11   22
#define SRV12   23
#endif

// For Fubarino Mini
#if defined(_BOARD_FUBARINO_MINI_)
#define M1EN12  7
#define M1EN34  8

#define M1A1    30
#define M1A2    32
#define M1A3    31
#define M1A4    29

#define M2EN12  9
#define M2EN34  10

#define M2A1    27
#define M2A2    26
#define M2A3    25
#define M2A4    28
// Mini only has 10 servos hooked up
#define SRV1    1
#define SRV2    2
// Note pin 14 and pin 15 are not available if using a crystal (default)
#define SRV3    14
#define SRV4    15
#define SRV5    16
#define SRV6    24
#define SRV7    23
#define SRV8    22
#define SRV9    21
#define SRV10   19
#endif

int TimeForServoChange;
unsigned long LastMillis = 0;

void setup()
{
    // Set up motor 1  
    pinMode(M1EN12, OUTPUT);
    digitalWrite(M1EN12, 1);
    pinMode(M1A1, OUTPUT);
    digitalWrite(M1A1, LOW);
    pinMode(M1A2, OUTPUT);
    digitalWrite(M1A2, LOW);

    // Set up motor 2
    pinMode(M1EN34, OUTPUT);
    digitalWrite(M1EN34, 1);
    pinMode(M1A3, OUTPUT);
    digitalWrite(M1A3, LOW);
    pinMode(M1A4, OUTPUT);
    digitalWrite(M1A4, LOW);
    
    // Set up motor 3
    pinMode(M2EN12, OUTPUT);
    digitalWrite(M2EN12, 1);
    pinMode(M2A1, OUTPUT);
    digitalWrite(M2A1, LOW);
    pinMode(M2A2, OUTPUT);
    digitalWrite(M2A2, LOW);

    // Set up motor 4
    pinMode(M2EN34,OUTPUT);
    digitalWrite(M2EN34, 1);
    pinMode(M2A3, OUTPUT);
    digitalWrite(M2A3, LOW);
    pinMode(M2A4, OUTPUT);
    digitalWrite(M2A4, LOW);
    
    TimeForServoChange = 25;
}

void loop()
{
    int i;
  
    // Motor 1 on forward - start off
    SoftPWMServoPWMWrite(M1EN12, 0);
    delay(20);
    digitalWrite(M1A1, 1);
    digitalWrite(M1A2, 0);
    // Now ramp up to full power
    for (i=0; i < 255; i++)
    {
      SoftPWMServoPWMWrite(M1EN12, i);
      delay(10);  
    }
    // Now ramp down to zero
    for (i=255; i > 0; i--)
    {
      SoftPWMServoPWMWrite(M1EN12, i);
      delay(10);  
    }
    delay(1000);

    // Motor 2 on forward - start off
    SoftPWMServoPWMWrite(M1EN34, 0);
    delay(20);
    digitalWrite(M1A3, 1);
    digitalWrite(M1A4, 0);
    // Now ramp up to full power
    for (i=0; i < 255; i++)
    {
      SoftPWMServoPWMWrite(M1EN34, i);
      delay(10);  
    }
    // Now ramp down to zero
    for (i=255; i > 0; i--)
    {
      SoftPWMServoPWMWrite(M1EN34, i);
      delay(10);  
    }
    delay(1000);

    // Motor 3 on forward - start off
    SoftPWMServoPWMWrite(M2EN12, 0);
    delay(20);
    digitalWrite(M2A1, 1);
    digitalWrite(M2A2, 0);
    // Now ramp up to full power
    for (i=0; i < 255; i++)
    {
      SoftPWMServoPWMWrite(M2EN12, i);
      delay(10);  
    }
    // Now ramp down to zero
    for (i=255; i > 0; i--)
    {
      SoftPWMServoPWMWrite(M2EN12, i);
      delay(10);  
    }
    delay(1000);

    // Motor 4 on forward - start off
    SoftPWMServoPWMWrite(M2EN34, 0);
    delay(20);
    digitalWrite(M2A3, 1);
    digitalWrite(M2A4, 0);
    // Now ramp up to full power
    for (i=0; i < 255; i++)
    {
      SoftPWMServoPWMWrite(M2EN34, i);
      delay(10);  
    }
    // Now ramp down to zero
    for (i=255; i > 0; i--)
    {
      SoftPWMServoPWMWrite(M2EN34, i);
      delay(10);  
    }
    delay(1000);
    
    // All motors off
    digitalWrite(M1A1, 0);
    digitalWrite(M1A2, 0);
    digitalWrite(M1A3, 0);
    digitalWrite(M1A4, 0);
    digitalWrite(M2A1, 0);
    digitalWrite(M2A2, 0);
    digitalWrite(M2A3, 0);
    digitalWrite(M2A4, 0);
    delay(1000);
}

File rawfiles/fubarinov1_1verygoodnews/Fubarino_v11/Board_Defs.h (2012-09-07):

/************************************************************************/
/*																		*/
/*	Board_Defs.h --	Default Board Customization Declarations			*/
/*																		*/
/************************************************************************/
/*	Author: Gene Apperson												*/
/*	Copyright 2011, Digilent. All rights reserved						*/
/************************************************************************/
/*  File Description:													*/
/*																		*/
/* This file contains the board specific declartions and data structure	*/
/* to customize the chipKIT MPIDE for use with a generic board using a	*/
/* PIC32 part in a 64-pin package.										*/
/*																		*/
/* This code is based on earlier work:									*/
/*		Copyright (c) 2010, 2011 by Mark Sproul							*/
/*		Copyright (c) 2005, 2006 by David A. Mellis						*/
/*																		*/
/************************************************************************/
/*  Revision History:													*/
/*																		*/
/*	10/07/2011(GeneA): Created											*/
/*	11/28/2011(GeneA): Moved data definitions and configuration			*/
/*		functions to Board_Data.c										*/
/*	11/29/2011(GeneA): Moved int priority definitions to System_Defs.h	*/
/*  03/11/2012(BrianS): Modified for Fubarino board                     */
/*																		*/
/************************************************************************/
//*	This library is free software; you can redistribute it and/or
//*	modify it under the terms of the GNU Lesser General Public
//*	License as published by the Free Software Foundation; either
//*	version 2.1 of the License, or (at your option) any later version.
//*	
//*	This library is distributed in the hope that it will be useful,
//*	but WITHOUT ANY WARRANTY; without even the implied warranty of
//*	MERCHANTABILITY or FITNESS FOR A PARTICULAR PURPOSE.  See the GNU
//*	Lesser General Public License for more details.
//*	
//*	You should have received a copy of the GNU Lesser General
//*	Public License along with this library; if not, write to the
//*	Free Software Foundation, Inc., 59 Temple Place, Suite 330,
//*	Boston, MA  02111-1307  USA
/************************************************************************/

#if !defined(BOARD_DEFS_H)
#define BOARD_DEFS_H

#include <inttypes.h>

/* ------------------------------------------------------------ */
/*				Public Board Declarations						*/
/* ------------------------------------------------------------ */
/* The following define symbols that can be used in a sketch to
** refer to periperhals on the board generically.
*/

#define	_BOARD_NAME_	"Fubarino"

/* Define the peripherals available on the board.
*/
#define	NUM_DIGITAL_PINS	46
#define	NUM_ANALOG_PINS		15
#define NUM_OC_PINS			5
#define	NUM_IC_PINS			5
#define	NUM_TCK_PINS		5
#define	NUM_INT_PINS		5

#define	NUM_SERIAL_PORTS	2
#define	NUM_SPI_PORTS		1
#define	NUM_I2C_PORTS		1

#define NUM_DSPI_PORTS		1
#define NUM_DTWI_PORTS		2

/* Define I/O devices on the board.
*/
#define	NUM_LED				1
#define NUM_BTN				1
#define	NUM_SWT				0
#define NUM_SERVO			0

/* ------------------------------------------------------------ */
/*						LED Declarations						*/
/* ------------------------------------------------------------ */

/* Define the pin numbers for the LEDs
*/
#define	PIN_LED1	21

/* ------------------------------------------------------------ */
/*					Button Declarations							*/
/* ------------------------------------------------------------ */

/* No buttons on this board.
*/

/* ------------------------------------------------------------ */
/*					Switch Declarations							*/
/* ------------------------------------------------------------ */

/* No switches on this board.
*/

/* ------------------------------------------------------------ */
/*					Servo Pin Declarations						*/
/* ------------------------------------------------------------ */

/* No servo connectors on this board.
*/

/* ------------------------------------------------------------ */
/*					Timer Pin Declarations						*/
/* ------------------------------------------------------------ */

#define PIN_OC1		5
#define	PIN_OC2		8
#define	PIN_OC3		9
#define	PIN_OC4		10
#define	PIN_OC5		11

#define PIN_IC1		1
#define PIN_IC2		2
#define PIN_IC3		3
#define PIN_IC4		4
#define	PIN_IC5		11

#define	PIN_TCK1	46
//#define	PIN_TCK2	not available on the chip
//#define	PIN_TCK3	not available on the chip
//#define	PIN_TCK4	not available on the chip
//#define	PIN_TCK5	not available on the chip

/* ------------------------------------------------------------ */
/*					Interrupt Pin Declarations					*/
/* ------------------------------------------------------------ */

#define	PIN_INT0	5
#define	PIN_INT1	1
#define PIN_INT2	2
#define	PIN_INT3	3
#define	PIN_INT4	4
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

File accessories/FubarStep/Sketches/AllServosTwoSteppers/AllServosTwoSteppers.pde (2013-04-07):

// MultiStepper.pde
// -*- mode: C++ -*-
//
// Shows how to multiple simultaneous steppers
// Runs one stepper forwards and backwards, accelerating and decelerating
// at the limits. Runs other steppers at the same time
//
// Copyright (C) 2009 Mike McCauley
// $Id: MultiStepper.pde,v 1.1 2011/01/05 01:51:01 mikem Exp mikem $

#include <AccelStepper.h>
#include <SoftPWMServo.h> 

int pos = 1000;         // variable to store the servo position, in microseconds

static int state1 = 0;
static int state2 = 0;

// For Fubarino SD
#if defined(_BOARD_FUBARINO_SD_)
#define M1EN12  7
#define M1EN34  8

#define M1A1    2
#define M1A2    0
#define M1A3    1
#define M1A4    3

#define M2EN12  9
#define M2EN34  10

#define M2A1    5
#define M2A2    6
#define M2A3    11
#define M2A4    4
// SD has all 12 servos hooked up
#define SRV1    12
#define SRV2    13
#define SRV3    14
#define SRV4    15
#define SRV5    16
#define SRV6    17
#define SRV7    18
#define SRV8    19
#define SRV9    20
#define SRV10   21
#define SRV11   22
#define SRV12   23
#endif

// For Fubarino Mini
#if defined(_BOARD_FUBARINO_MINI_)
#define M1EN12  7
#define M1EN34  8

#define M1A1    30
#define M1A2    32
#define M1A3    31
#define M1A4    29

#define M2EN12  9
#define M2EN34  10

#define M2A1    27
#define M2A2    26
#define M2A3    25
#define M2A4    28
// Mini only has 10 servos hooked up
#define SRV1    1
#define SRV2    2
// Note pin 14 and pin 15 are not available if using a crystal (default)
#define SRV3    14
#define SRV4    15
#define SRV5    16
#define SRV6    24
#define SRV7    23
#define SRV8    22
#define SRV9    21
#define SRV10   19
#endif


void motor1output(int state)
{
  switch(state)
  {
    case 0:
      digitalWrite(M1A1,1);
      digitalWrite(M1A2,0);
      digitalWrite(M1A3,1);
      digitalWrite(M1A4,0);      
      break;
      
    case 1:
      digitalWrite(M1A1,1);
      digitalWrite(M1A2,0);
      digitalWrite(M1A3,0);
      digitalWrite(M1A4,1);      
      break;

    case 2:
      digitalWrite(M1A1,0);
      digitalWrite(M1A2,1);
      digitalWrite(M1A3,0);
      digitalWrite(M1A4,1);      
      break;

    case 3:
      digitalWrite(M1A1,0);
      digitalWrite(M1A2,1);
      digitalWrite(M1A3,1);
      digitalWrite(M1A4,0);      
      break;
  }
}

void motor2output(int state)
{
  switch(state)
  {
    case 0:
      digitalWrite(M2A1,1);
      digitalWrite(M2A2,0);
      digitalWrite(M2A3,1);
      digitalWrite(M2A4,0);      
      break;
      
    case 1:
      digitalWrite(M2A1,1);
      digitalWrite(M2A2,0);
      digitalWrite(M2A3,0);
      digitalWrite(M2A4,1);      
      break;

    case 2:
      digitalWrite(M2A1,0);
      digitalWrite(M2A2,1);
      digitalWrite(M2A3,0);
      digitalWrite(M2A4,1);      
      break;

    case 3:
      digitalWrite(M2A1,0);
      digitalWrite(M2A2,1);
      digitalWrite(M2A3,1);
      digitalWrite(M2A4,0);      
      break;
  }
}

void forwardstep1()
{
  state1++;
  if (state1 >= 4)
  {
    state1 = 0;
  }
  motor1output(state1);  
}

void backwardstep1()
{
  state1--;
  if (state1 < 0)
  {
    state1 = 3;
  }  
  motor1output(state1);  
}


void forwardstep2()
{
  state2++;
  if (state2 >= 4)
  {
    state2 = 0;
  }
  motor2output(state2);  
}

void backwardstep2()
{
  state2--;
  if (state2 < 0)
  {
    state2 = 3;
  }
  motor2output(state2);  
}

// Define some steppers and the pins the will use
AccelStepper stepper1(forwardstep1, backwardstep1); 
AccelStepper stepper2(forwardstep2, backwardstep2); 

int TimeForServoChange;
unsigned long LastMillis = 0;


void setup()
{  
    // Set up enable pins to be output, high
    pinMode(M1EN12, OUTPUT);
    pinMode(M1EN34, OUTPUT);
    pinMode(M2EN12, OUTPUT);
    pinMode(M2EN34,OUTPUT);
    digitalWrite(M1EN12, 1);
    digitalWrite(M1EN34, 1);
    digitalWrite(M2EN12, 1);
    digitalWrite(M2EN34, 1);

    pinMode(M1A1, OUTPUT);
    pinMode(M1A2, OUTPUT);
    pinMode(M1A3, OUTPUT);
    pinMode(M1A4,OUTPUT);
    
    pinMode(M2A1, OUTPUT);
    pinMode(M2A2, OUTPUT);
    pinMode(M2A3, OUTPUT);
    pinMode(M2A4,OUTPUT);
    
    stepper1.setMaxSpeed(1000.0);
    stepper1.setAcceleration(500.0);
    stepper1.moveTo(200);
    
    stepper2.setMaxSpeed(300.0);
    stepper2.setAcceleration(100.0);
    stepper2.moveTo(762);
    
    TimeForServoChange = 25;
}

void loop()
{
  // Change direction at the limits
  if (stepper1.distanceToGo() == 0)
	stepper1.moveTo(-stepper1.currentPosition());
  stepper1.run();
  if (stepper2.distanceToGo() == 0)
	stepper2.moveTo(-stepper2.currentPosition());
  stepper2.run();
  if (millis() != LastMillis)
  {
    TimeForServoChange--;  
    LastMillis = millis();
  }
  if (TimeForServoChange <= 0)
  {
    SoftPWMServoServoWrite(SRV1, pos);     // tell servo to go to position in variable 'pos' 
    SoftPWMServoServoWrite(SRV2, pos);     // tell servo to go to position in variable 'pos' 
    SoftPWMServoServoWrite(SRV3, pos);     // tell servo to go to position in variable 'pos' 
    SoftPWMServoServoWrite(SRV4, pos);     // tell servo to go to position in variable 'pos' 
    SoftPWMServoServoWrite(SRV5, pos);     // tell servo to go to position in variable 'pos' 
    SoftPWMServoServoWrite(SRV6, pos);     // tell servo to go to position in variable 'pos' 
    SoftPWMServoServoWrite(SRV7, pos);     // tell servo to go to position in variable 'pos' 
    SoftPWMServoServoWrite(SRV8, pos);     // tell servo to go to position in variable 'pos' 
    SoftPWMServoServoWrite(SRV9, pos);     // tell servo to go to position in variable 'pos' 
    SoftPWMServoServoWrite(SRV10, pos);     // tell servo to go to position in variable 'pos' 
    #if defined(_BOARD_FUBARINO_SD_)
    SoftPWMServoServoWrite(SRV11, pos);     // tell servo to go to position in variable 'pos' 
    SoftPWMServoServoWrite(SRV12, pos);     // tell servo to go to position in variable 'pos' 
    #endif 
    TimeForServoChange = 25;
    pos += 10;
    if (pos > 2000)
    {
      pos = 1000;
    }
  }
}

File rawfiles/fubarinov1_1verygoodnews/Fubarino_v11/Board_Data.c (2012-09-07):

/************************************************************************/
/*																		*/
/*	Board_Data.c --	Default Board Customization Data Declarations		*/
/*																		*/
/************************************************************************/
/*	Author: Gene Apperson												*/
/*	Copyright 2011, Digilent. All rights reserved						*/
/************************************************************************/
/*  File Description:													*/
/*																		*/
/* This file contains the board specific declartions and data structure	*/
/* to customize the chipKIT MPIDE for use with a generic board using a	*/
/* PIC32 part in a 64-pin package.										*/
/*																		*/
/* This code is based on earlier work:									*/
/*		Copyright (c) 2010, 2011 by Mark Sproul							*/
/*		Copyright (c) 2005, 2006 by David A. Mellis						*/
/*																		*/
/************************************************************************/
/*  Revision History:													*/
/*																		*/
/*	11/28/2011(GeneA): Created by splitting data out of Board_Defs.h	*/
/*  03/11/2012(BrianS): Modified for Fubarino board                     */
/*																		*/
/************************************************************************/
//*	This library is free software; you can redistribute it and/or
//*	modify it under the terms of the GNU Lesser General Public
//*	License as published by the Free Software Foundation; either
//*	version 2.1 of the License, or (at your option) any later version.
//*	
//*	This library is distributed in the hope that it will be useful,
//*	but WITHOUT ANY WARRANTY; without even the implied warranty of
//*	MERCHANTABILITY or FITNESS FOR A PARTICULAR PURPOSE.  See the GNU
//*	Lesser General Public License for more details.
//*	
//*	You should have received a copy of the GNU Lesser General
//*	Public License along with this library; if not, write to the
//*	Free Software Foundation, Inc., 59 Temple Place, Suite 330,
//*	Boston, MA  02111-1307  USA
/************************************************************************/

#if !defined(BOARD_DATA_C)
#define BOARD_DATA_C

#include <inttypes.h>

/* ------------------------------------------------------------ */
/*					Data Tables									*/
/* ------------------------------------------------------------ */
/* The following declarations define data used in pin mapping.	*/
/* ------------------------------------------------------------ */

#if defined(OPT_BOARD_DATA)

/* ------------------------------------------------------------ */
/* This table is used to map from port number to the address of
** the TRIS register for the port. This is used for setting the
** pin direction.
*/
const uint32_t	port_to_tris_PGM[] = {
	NOT_A_PORT,				//index value 0 is not used

#if defined(_PORTA)
	(uint32_t)&TRISA,
#else
	NOT_A_PORT,
#endif

#if defined(_PORTB)
	(uint32_t)&TRISB,
#else
	NOT_A_PORT,
#endif

#if defined(_PORTC)
	(uint32_t)&TRISC,
#else
	NOT_A_PORT,
#endif

#if defined(_PORTD)
	(uint32_t)&TRISD,
#else
	NOT_A_PORT,
#endif

#if defined(_PORTE)
	(uint32_t)&TRISE,
#else
	NOT_A_PORT,
#endif

#if defined(_PORTF)
	(uint32_t)&TRISF,
#else
	NOT_A_PORT,
#endif

#if defined(_PORTG)
	(uint32_t)&TRISG,
#else
	NOT_A_PORT,
#endif

	NOT_A_PORT,
};

/* ------------------------------------------------------------ */
/* This table is used to map the digital pin number to the port
** containing that pin. The default mapping is to assign pin numbers
** for every possible port bit in order from PORTA to PORTG.
*/
const uint8_t	digital_pin_to_port_PGM[] = {
    // Pins 0 through 23
    _IOPORT_PD, //  0  RD8
	_IOPORT_PD, //  1  RD9
	_IOPORT_PD, //  2  RD10
	_IOPORT_PD, //  3  RD11
	_IOPORT_PD, //  4  RD0
	_IOPORT_PC, //  5  RC13
	_IOPORT_PC, //  6  RC14
	_IOPORT_PD, //  7  RD1
	_IOPORT_PD, //  8  RD2
	_IOPORT_PD, //  9  RD3
	_IOPORT_PD, // 10  RD4
	_IOPORT_PD, // 11  RD5
	_IOPORT_PD, // 12  RD6
	_IOPORT_PD, // 13  RD7
	_IOPORT_PF, // 14  RF0
	_IOPORT_PF, // 15  RF1
	_IOPORT_PE, // 16  RE0
	_IOPORT_PE, // 17  RE1
	_IOPORT_PE, // 18  RE2
	_IOPORT_PE, // 19  RE3
	_IOPORT_PE, // 20  RE4
	_IOPORT_PE, // 21  RE5
	_IOPORT_PE, // 22  RE6
	_IOPORT_PE, // 23  RE7

    // Pins 24 through 44
    _IOPORT_PG, // 24  RG6
	_IOPORT_PG, // 25  RG7
	_IOPORT_PG, // 26  RG8
	_IOPORT_PG, // 27  RG9
	_IOPORT_PF, // 28  RF4
	_IOPORT_PF, // 29  RF5
	_IOPORT_PB, // 30  RB4
	_IOPORT_PB, // 31  RB3
	_IOPORT_PB, // 32  RB2
	_IOPORT_PB, // 33  RB1
	_IOPORT_PB, // 34  RB0
	_IOPORT_PB, // 35  RB7
	_IOPORT_PB, // 36  RB6
	_IOPORT_PB, // 37  RB8
	_IOPORT_PB, // 38  RB9
	_IOPORT_PB, // 39  RB10
	_IOPORT_PB, // 40  RB11
	_IOPORT_PB, // 41  RB12
	_IOPORT_PB, // 42  RB13
	_IOPORT_PB, // 43  RB14
	_IOPORT_PB, // 44  RB15
};
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

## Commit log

2012-08-19 Raw dump of files. Need to organize for documentation.
    [EagleFubarinoTestShield.sch, FubarinoAdapterShield.fzz, FubarinoMini_v10.brd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]
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2012-08-31 Version v1.4 Fubarino SD board files, and manufacturing HEX and test files committed.
    [Fubarino_SD_v14.brd, Fubarino_SD_v14.sch, Fubarino_SD_v14_BOM_SeeedFormat.xlsx]
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2013-01-01 Fixed reference to UART in diagrams for pins 8,9
2013-01-11 Updated silk screen with chipKIT, RX (pin 8) and TX (pin 9) Bumped rev to 1.5
    [Fubarino_SD_v15.brd, Fubarino_SD_v15.sch, Fubarino_SD_v15_BOM_SeeedFormat.xlsx]
2013-01-12 Added Rick's QR code to top silk layer. Still v1.5
    [Fubarino_SD_v15.brd]
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2013-01-29 Checking in FubarinoMini v1.0 through v1.4, all files including gerbers.
    [FubarinoMini_v10.brd, FubarinoMini_v10.sch, FubarinoMini_v10_BOM.xls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]
2013-02-19 Updated SVG diagram as per Jacob's suggestion (A8/A7 mistake) Updated reference manual with updated diagram. Updated schematic to 1.4.1, with 5V net renamed to Vout as per Jaocb's suggestion.
    [Fubarino_SD_v14.brd, Fubarino_SD_v14.sch]
2013-02-24 Start on version 1.5 for Microchip - added CE, RoSH garbage can, and chipKIT logos to bottom silk layer.
    [02-10064r1.xls, FubarinoMini_v15.brd, FubarinoMini_v15.sch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]
2013-02-24 Created first pass of assembly drawing, drill drawing, and BOM in Microchip format.
    [FubarinoMini_v15.brd, Fubarino_Mini_v15_BOM_Microchip.xls, Fubarino_Mini_v15_BOM_SeeedFormat.xlsx]
2013-02-27 "final" version 1.5 files, submitted to Microchip for their approval Updated USB connector footprint to Microchip's fav Hirose
    [06-10133r15.xls, FubarinoMini_v15.brd, FubarinoMini_v15.sch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]
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2013-02-27 Swapped USB connector for Microchip's Hirose.
    [Fubarino_SD_v15.brd, Fubarino_SD_v15.sch]
2013-02-27 Updated Fubarino SD v1.5 board with CE, RoHS, chipKIT on silk, updated BOM, rendered top and bottom from gerbers.
    [FubarinoMini_v15.brd, Fubarino_SD_v15.brd, Fubarino_SD_v15.sch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]
2013-02-27 "Final" Fubarino Mini v1.5 files for Microchip. Fixed several minor documentation errors, created all new files, created IPC and PNP files.
    [02-10134r15.xls, 06-10133r15.xls, FubarinoMini_v15.brd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]
2013-02-27 "Final" Fubarino SD v1.5 files to Microchip, including IPC and PNP.
    [02-10133r15.xls, Fubarino_SD_v15.brd, Fubarino_SD_v15_centroid.csv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]
2013-02-28 Corrected CPU in BOM for Fubatino SD to MX795.
    [02-10133r15.xls, Fubarino_SD_v15_BOM_Microchip.xls]
2013-02-28 Updated Fubarino SD BOM to use IC2 as the designator for the LDO as the schematic does.
    [02-10133r15.xls, Fubarino_SD_v15_BOM_Microchip.xls]
2013-02-28 Corrected CPU on Fubarino Mini v1.5 to be the VQFN package rather than the VTLA package.
    [02-10134r15.xls, Fubarino_Mini_v15_BOM_Microchip.xls]
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2013-03-10 Started routing. And assigned all the pins except for Mini to SD.
    [FubarStep_v10thin.brd, FubarStep_v10thin.sch]
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2013-03-11 Routing is done, but Mini connections not yet made. Top silk is almost done.
    [FubarStep_v10thin.brd, FubarStep_v10thin.sch]
2013-03-12 Renamed board from thin to normal, added all Mini routing except for 2 pins (maybe TX/RX?) Almost done!
    [FubarStep_v10.brd, FubarStep_v10.sch, FubarStep_v10thin.brd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]
2013-03-13 Version 1.0 done - routed, schematic done (with license), just need to add BOM now.
    [FubarStep_v10.brd, FubarStep_v10.sch]
2013-03-13 Added power mode jumper to select between 12V and 5V inputs. Added two ground pins for debugging Added 2-pin screw terminal for extra power input option.
    [FubarStep_v10.brd, FubarStep_v10.sch]
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2013-03-14 Got some more work done on the board - fixed power issues, added reset/prg switches, moved Fubarinos inside Uno headers.
    [UnoAdapter_v10.brd, UnoAdapter_v10.sch, UnoAdapter_v10_BOM_SeeedFormat.xlsx]
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2013-03-15 Version 1.6 of Fubarino Mini - replaced GND on J2 pin 17 with RESET so that we can use external reset button with shields and such.
    [02-10064r1.xls, 02-10134r16.xls, FubarinoMini_v16.brd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]
2013-03-19 Update to UnoAdapter - still not done yet. Added Fubarino Mini v1.6 files (brought MCLR out to side pin)
    [02-10134r16.xls, DRILEGEND.CFG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]
2013-03-19 Updated BOM on v1.6 Mini to use 820 ohm current limits rather than 330s.
    [02-10134r16.xls, Fubarino_Mini_v16_BOM_Microchip.xls, Fubarino_Mini_v16_BOM_SeeedFormat.xlsx]
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2013-04-02 Created FUBARStep v1.1 - fixed problems found with v1.0 build
    [FubarStep_v11.brd, FubarStep_v11.sch, FubarStep_v11_BOM_SeeedFormat.xlsx]
2013-04-03 Created 'Simple' Fubarino Mini tests for Microchip that doesn't want to build a test jig. Version 1.1 of test PDE and instructions.
    [FubarinoMini_ManufactureTest.pde, FubarinoMini_ManufactureTest_Simple.pde]
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2013-05-01 Fixed a minor silk screen error from FubarStep v1.0 Added RoSH and CE logos to back silk
    [FubarStep_v11.brd]
2013-05-04 Made board taller so that we could fit screws into the mounding holes. Added silk on all pins for better documentation. Ordered this exact board from OSHPark.
    [FubarStep_v11.brd]
2013-05-11 Oops. Found a minor mistake on the FubarStep schematic.
2013-05-11 Started FubarStep v1.2 - fixed TX/RX swap on Mini
    [FubarStep_v12.brd, FubarStep_v12.sch, FubarStep_v12_BOM_SeeedFormat.xlsx]
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2013-05-20 Fixed issues with links and button format on index files.
2013-06-12 Just playing with some ideas for v1.2 board - adding headers to every pin, for a complete break out board type feel.
    [FubarStep_v12.brd, FubarStep_v12.sch]
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2014-02-02 Version 1.3 ready for review. Added pull down resistors to H-Bridge inputs, tweaked part placement for better assembly and silk screen for more information and readability.
    [FubarStep_v10.GBL, FubarStep_v10.GBO, FubarStep_v10.GBP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]
2014-03-11 Created PIC32MX795F512H symbol, and updated schematic with it. Also had to re-do nets to CPU on layout because Eagle reasons.
    [Fubarino_SD_v15.brd, Fubarino_SD_v15.sch]
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2014-05-02 Minor spelling corrections, and switching to "chipKIT Fubarino" word order for both boards (per Microchip's recommendation), and adding TM to Fubarino and chipKIT.
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2014-05-27 Ooooops. Bad footprint for CPU. Got boards back and they had solder mask on all pins. Updated to new footprint, found D-/D+ swap bug, and send out for new boards.
    [Fubarino_SDZ_v10.GBL, Fubarino_SDZ_v10.GBO, Fubarino_SDZ_v10.GBP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]
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2014-07-07 Got most of the PnP running. The Fubarino_SDZ_v10_Top.csv file has all the good stuff.
    [Fubarino_SDZ_v10_Top.csv]
2014-07-09 Final PnP command file we used to build 21 Fubarino SDZ boards.
    [Fubarino_SDZ_v10.csv, Fubarino_SDZ_v10_Bottom.csv, Fubarino_SDZ_v10_PnP.csv]
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2015-09-13 Created version 1.5 - Switched VBUS PIC32 to be connected to VBUS net rather than 5V.
    [FubarinoMini_v17.brd, FubarinoMini_v17.sch, Fubarino_Mini_v17_BOM_Microchip.xls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]
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2016-03-26 Updated SVG pin diagram with correct analog pin names, created EPS version, updated User Reference Manual with updated diagram EPS file. Also updated pin table in Ref Manual with actual analog pin na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
2017-03-04 Updating Fubarino Mini pin diagram to have correct SPI1 pins
2017-03-04 Updated Fubarino Mini pin diagram and Reference Manual to use correct pins for SPI (SPI1) port, also added sections in ref manual giving table of SPI1 and SPI2 pins.
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2018-05-03 Changed LDO to one that has 15V VIn max. Still need to updated caps on either side to be bigger.
    [FubarinoMini_v17.brd, FubarinoMini_v17.sch, Fubarino_Mini_v17_BOM_Microchip.xlsx]
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2018-08-19 Version 2.0, first draft, done and sent to PCB fab. Changed switches, crystal, USB connector, rerouted most of board. Still need to rename folder to 2.0
    [FubarinoMini_v17.GBL, FubarinoMini_v17.GBO, FubarinoMini_v17.GBP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]
2018-08-25 Minor silk screen adjustments for readability, and moving a couple caps around for easier assembly.
    [FubarinoMini_v17.brd]
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2018-08-25 Updated BOM with caps that are available at this minute, and added 1K parts prices.
    [Fubarino_Mini_v20_BOM_Microchip.xlsx]
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2021-02-21 Fixed error on FB Mini v1.5 PNG and PDF pin diagrams (issue #26). Also created FB Mini v2.0 SVG, PDF and PNG.
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

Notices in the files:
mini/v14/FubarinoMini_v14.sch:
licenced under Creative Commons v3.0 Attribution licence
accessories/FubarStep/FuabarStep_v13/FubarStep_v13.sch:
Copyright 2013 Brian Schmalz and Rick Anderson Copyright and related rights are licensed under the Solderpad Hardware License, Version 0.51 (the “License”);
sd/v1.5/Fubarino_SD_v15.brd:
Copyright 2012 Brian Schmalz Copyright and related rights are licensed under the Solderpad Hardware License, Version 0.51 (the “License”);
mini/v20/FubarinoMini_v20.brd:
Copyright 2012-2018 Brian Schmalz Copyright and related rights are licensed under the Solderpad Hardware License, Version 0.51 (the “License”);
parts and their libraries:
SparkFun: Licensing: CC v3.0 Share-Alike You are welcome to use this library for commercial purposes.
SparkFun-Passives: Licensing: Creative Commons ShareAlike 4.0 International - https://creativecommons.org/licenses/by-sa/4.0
